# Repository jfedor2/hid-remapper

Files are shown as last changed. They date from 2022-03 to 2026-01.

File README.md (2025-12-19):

# HID Remapper

_For user documentation please see the project's website at [remapper.org](https://www.remapper.org/)._

This is a configurable USB dongle that allows you to remap inputs from mice, keyboards and other devices. It works completely in hardware and requires no software running on the computer during normal use.

It can do things like reassign buttons, change keyboard layouts, map mouse buttons to keyboard inputs, map keystrokes to mouse inputs, change mouse sensitivity (permanently or when a button is held), rotate mouse axes by arbitrary (non-90 degree) angles, drag-lock for mouse buttons, scroll by moving the mouse, and much more.

It is configurable [through a web browser](https://www.remapper.org/config/) using WebHID (Chrome or Chrome-based browser required).

Wireless receivers are supported and multiple devices can be connected at the same time using a USB hub (with different mappings for each device if desired).

In addition to the remapping functionality, it can do polling rate overclocking up to 1000 Hz.

A separate [serial](SERIAL.md) version of the remapper takes inputs from a serial (RS-232) mouse and translates them to USB.

There's also a [Bluetooth](BLUETOOTH.md) version that runs on nRF52840-based boards, which translates Bluetooth inputs to USB.

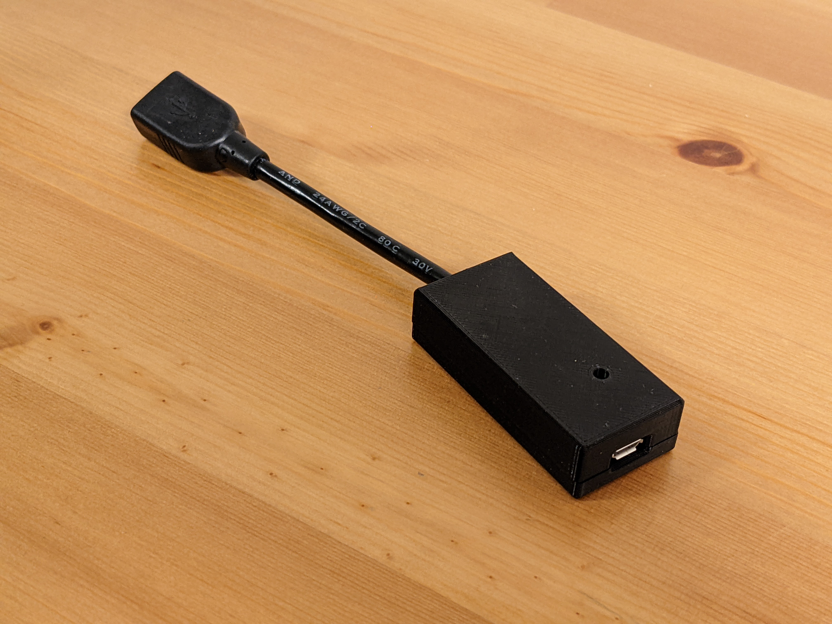
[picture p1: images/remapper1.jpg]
HID Remapper


## How to make the device

There are three main ways of making the HID Remapper. You can either buy [this board](https://www.adafruit.com/product/5723) from Adafruit, make it yourself using a Raspberry Pi Pico (or two), or you can use the provided files to manufacture a custom board at JLCPCB or a similar service. The functionality is the same in all cases.

If you get the Feather RP2040 USB Host board from Adafruit, the device is ready to use, you just need to flash it with the right firmware ([remapper\_feather.uf2](https://github.com/jfedor2/hid-remapper/releases/latest/download/remapper_feather.uf2)). Hold the "Boot" button on the board, then press the "Reset" button. A USB drive should show up on your computer. Copy the UF2 file to that drive. That's it.

See [here](HARDWARE.md) for details on how to make the Pico variants of the device and [here](custom-boards/) for details on the custom board option.

## How to use the configuration tool

A live version of the web configuration tool can be found at [remapper.org/config](https://www.remapper.org/config/).

For details on how to use it, please see the [HID Remapper Manual](https://www.remapper.org/manual/).

If you can't use the browser-based configuration tool, there's also a [command-line tool](config-tool) that takes JSON in the same format as the web tool on standard input. I only tested it on Linux, but in theory it should also run on Windows and Mac.

## How to update the firmware

The procedure to update the firmware is similar on all variants. When you go to the configuration website and try to connect to your device when it doesn't have the latest firmware, you will get a message and a link to a version of the configuration interface that is compatible with your current (old) firmware. Click that link, connect to your HID Remapper by clicking "Open device" as usual, then go to the "Actions" tab and click "Flash firmware". This will put your device in firmware flashing mode. A drive should appear on your computer. For all the RP2040-based variants, the drive will be named "RPI-RP2". For the Bluetooth variants, it will be called something else, depending on what board you're using. Download the correct firmware file for your variant (see table below) and copy it to that drive. On custom boards v1, v2, v5, v6 and v7 (dual RP2040 boards), after flashing the firmware you have to disconnect and reconnect your HID Remapper. That's it, you can go back to the regular version of the configuration interface and carry on.

_(Please note that previously a manual "Flash B side" step was required on custom boards v1, v2, v5, v6 and v7. That is no longer necessary.)_

If you're using the dual Pico variant then you need to flash the A side using the [remapper\_dual\_a.uf2](https://github.com/jfedor2/hid-remapper/releases/latest/download/remapper_dual_a.uf2) file as described above and then flash the B side manually. Disconnect your HID Remapper from your computer, disconnect the OTG adapter from the B-side Pico, hold the BOOTSEL button on the B-side Pico and then, while holding the button, connect the B-side Pico to your computer. A drive named "RPI-RP2" should appear. Copy the [remapper\_dual\_b.uf2](https://github.com/jfedor2/hid-remapper/releases/latest/download/remapper_dual_b.uf2) file to that drive. Disconnect the B-side Pico from your computer, reconnect the OTG adapter and reconnect your HID Remapper to your computer.

When updating firmware, the current configuration on your HID Remapper is preserved. For extra peace of mind you can export your configuration to a JSON file before performing the update. That way if you need to revert to the old version of the firmware for any reason, you'll be able to import the configuration from the JSON file (configuration is lost when going from a newer firmware to an older firmware).

variant | firmware file(s) | notes
------- | ---------------- | -----------------------
single Pico | [remapper.uf2](https://github.com/jfedor2/hid-remapper/releases/latest/download/remapper.uf2) |
dual Pico | [remapper\_dual\_a.uf2](https://github.com/jfedor2/hid-remapper/releases/latest/download/remapper_dual_a.uf2)<br>[remapper\_dual\_b.uf2](https://github.com/jfedor2/hid-remapper/releases/latest/download/remapper_dual_b.uf2) | each Pico needs to be flashed separately
Feather RP2040 with USB Host | [remapper\_feather.uf2](https://github.com/jfedor2/hid-remapper/releases/latest/download/remapper_feather.uf2) |
custom board v1 | [remapper\_board.uf2](https://github.com/jfedor2/hid-remapper/releases/latest/download/remapper_board.uf2) | disconnect and reconnect after flashing
custom board v2 | [remapper\_board.uf2](https://github.com/jfedor2/hid-remapper/releases/latest/download/remapper_board.uf2) | disconnect and reconnect after flashing
custom board v3 | [remapper\_feather.uf2](https://github.com/jfedor2/hid-remapper/releases/latest/download/remapper_feather.uf2) |
custom board v4 | [remapper\_feather.uf2](https://github.com/jfedor2/hid-remapper/releases/latest/download/remapper_feather.uf2) |
custom board v5 | [remapper\_board.uf2](https://github.com/jfedor2/hid-remapper/releases/latest/download/remapper_board.uf2) | disconnect and reconnect after flashing
custom board v6 | [remapper\_board.uf2](https://github.com/jfedor2/hid-remapper/releases/latest/download/remapper_board.uf2) | disconnect and reconnect after flashing
custom board v7 | [remapper\_board\_v7.uf2](https://github.com/jfedor2/hid-remapper/releases/latest/download/remapper_board_v7.uf2) | disconnect and reconnect after flashing
custom board v8 | [remapper\_board\_v8.uf2](https://github.com/jfedor2/hid-remapper/releases/latest/download/remapper_board_v8.uf2) |
Feather nRF52840 Express | [remapper_adafruit_feather_nrf52840.uf2](https://github.com/jfedor2/hid-remapper/releases/latest/download/remapper_adafruit_feather_nrf52840.uf2) |
Xiao nRF52840 | [remapper_seeed_xiao_nrf52840.uf2](https://github.com/jfedor2/hid-remapper/releases/latest/download/remapper_seeed_xiao_nrf52840.uf2) |
serial | [remapper_serial.uf2](https://github.com/jfedor2/hid-remapper/releases/latest/download/remapper_serial.uf2) |

For boards not listed above, use the same file name you used when flashing it for the first time.

## How to compile the firmware

The easiest way to compile the firmware is to let GitHub do it for you. This repository has GitHub Actions that build the firmware, so you can just fork, make your changes, wait for the job to complete, and look for the binaries in the artifacts produced.

To compile the RP2040 firmware on your machine, use the following steps (details may vary depending on your Linux distribution):

```
sudo apt install gcc-arm-none-eabi libnewlib-arm-none-eabi libstdc++-arm-none-eabi-newlib srecord
git clone https://github.com/jfedor2/hid-remapper.git
cd hid-remapper
git submodule update --init
cd firmware
mkdir build
cd build
cmake ..
# or, to build for the custom boards:
# PICO_BOARD=remapper cmake ..
make
```

To compile the nRF52 firmware, you can either follow [Nordic's setup instructions](https://docs.nordicsemi.com/bundle/ncs-latest/page/nrf/installation.html) and then `west build -b seeed_xiao_nrf52840` to compile the firmware, or you can use Docker with a command like this (start from the top level of the repository or adjust the path accordingly):

```
docker run --rm -v $(pwd):/workdir/project -w /workdir/project/firmware-bluetooth nordicplayground/nrfconnect-sdk:v2.2-branch west build -b seeed_xiao_nrf52840
```

## License

The software in this repository is licensed under the [MIT License](LICENSE), unless stated otherwise.

The hardware designs in this repository are licensed under the Creative Commons Attribution 4.0 International license ([CC BY 4.0](https://creativecommons.org/licenses/by/4.0/)), unless stated otherwise.

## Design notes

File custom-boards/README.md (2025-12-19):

# Custom HID Remapper boards

This document describes how to have custom HID Remapper boards manufactured using the provided design files at a service like JLCPCB. If you'd rather make the device using a Raspberry Pi Pico, see [here](../HARDWARE.md) for details on that option.

There are eight versions, imaginatively named v1-v8. v1, v2, v5, v6 and v7 are equivalent to the dual Pico variant when it comes to internal architecture and device compatibility. v3 and v4 are equivalent to the single Pico variant. v8 uses a single RP2040 chip, but it doesn't have USB inputs.

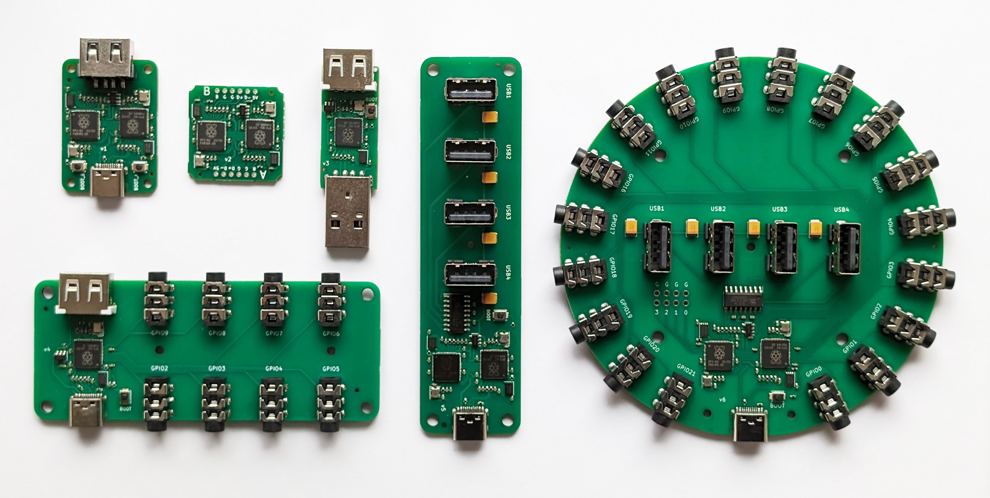
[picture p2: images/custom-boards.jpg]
Custom HID Remapper boards


The main advantage of the v1 board is that it can be made with no soldering, you just order the board, flash the firmware, and have a working device. Files for an optional 3D printable enclosure are also available (it uses M2x8 flat head screws).

The v2 board doesn't have USB connectors and is meant to be built into existing devices like trackballs by soldering the appropriate wires directly to the board.

The v3 board has the form factor of a USB dongle (you plug it directly into your computer).

The v4 board has eight 3.5mm connectors wired to GPIO2-9, meant to be used with external buttons or switches. The 3D printed case for it uses two M2x4 screws and four M3x10 flat head screws.

The v5 board has a built-in four port USB hub. The 3D printed case for it uses one M2x4 screw and four M3x10 flat head screws.

The v6 board has a built-in four port USB hub and eighteen 3.5mm connectors wired to GPIO pins that can be used with external buttons or switches. The 3D printed case for it uses three M2x4 screws and four M3x10 flat head screws.

The v7 board (not pictured above) is a companion device for accessibility controllers like the PlayStation Access and the Xbox Adaptive Controller. It has four analog and ten digital outputs that can be connected to the 3.5mm input ports on those controllers. More information [here](v7).

The v8 board (not pictured above) has one 3.5mm TRRS jack that can be used for analog inputs. For example it could be used to add analog stick inputs to the Hori Flex controller. The jack also works for one or two digital buttons or switches. More information [here](v8).

## How to order the boards

The process of ordering the boards is the same for all versions. You go to JLCPCB's [website](https://jlcpcb.com/), upload the Gerber zip file, enable the "PCB Assembly" option and upload the BOM and CPL files. All the options can be left at their default values. Then click through the rest of the process, making sure that all the components are in stock.

If you want to use some other service than JLCPCB, you will likely need to adapt at least the BOM and CPL files to match their requirements.

## How to flash the firmware

### Firmware flashing mode

v1 and v3-v8 boards have buttons labeled "BOOT\_A" and "BOOT", respectively. These work the same as the BOOTSEL button on a Raspberry Pi Pico. You hold the button while connecting it to a computer to put the board in firmware flashing mode. The v2 board doesn't have a button, but it has the equivalent pin broken out. Short the BOOT pin on the A side to GND while connecting the board to a computer to put it in firmware flashing mode. Then copy the UF2 file to the drive that appears.

If the board is already flashed with some version of the HID Remapper firmware then you can also put it in firmware flashing mode by going to the web config tool and pressing the "Flash firmware" button. This is useful when you want to upgrade the firmware on a device that is not easily accessible.

When the board is fresh from the factory (has never been flashed), it should enter firmware flashing mode automatically when you connect it to a computer with no additional steps necessary.

### v1, v2, v5 and v6

Flash the board with [remapper\_board.uf2](https://github.com/jfedor2/hid-remapper/releases/latest/download/remapper_board.uf2) file by putting it in firmware flashing mode and copying the file to the "RPI-RP2" drive that should appear on your computer.

Disconnect and reconnect your HID Remapper after flashing the firmware.

_(Please note that previously a manual "Flash B side" step was required on these boards. That is no longer necessary.)_

### v7

Flash the board with [remapper\_board\_v7.uf2](https://github.com/jfedor2/hid-remapper/releases/latest/download/remapper_board_v7.uf2) file by putting it in firmware flashing mode and copying the file to the "RPI-RP2" drive that should appear on your computer.

Disconnect and reconnect your HID Remapper after flashing the firmware.

_(Please note that previously a manual "Flash B side" step was required on this board. That is no longer necessary.)_

### v3 and v4

Flash the board with [remapper\_feather.uf2](https://github.com/jfedor2/hid-remapper/releases/latest/download/remapper_feather.uf2) file by putting it in firmware flashing mode and copying the file to the "RPI-RP2" drive that should appear on your computer.

### v8

Flash the board with [remapper\_board\_v8.uf2](https://github.com/jfedor2/hid-remapper/releases/latest/download/remapper_board_v8.uf2) file by putting it in firmware flashing mode and copying the file to the "RPI-RP2" drive that should appear on your computer.

## Acknowledgements

v1, v4, v5, v6 and v7 PCB designs use [Type-C.pretty](https://github.com/ai03-2725/Type-C.pretty) library by [ai03-2725](https://github.com/ai03-2725).

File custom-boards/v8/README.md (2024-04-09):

# HID Remapper custom board v8

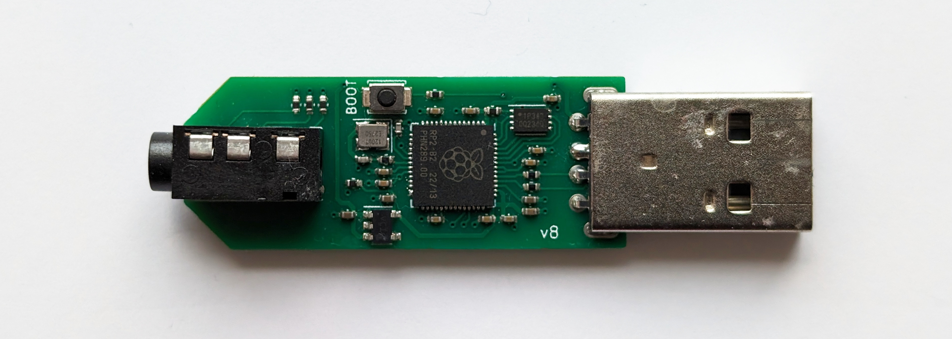
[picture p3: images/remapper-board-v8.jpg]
HID Remapper custom board v8


This variant of HID Remapper doesn't have USB inputs, it only has one 3.5mm TRRS jack. It can be used to connect an analog joystick or trigger (and also one or two digital buttons or switches).

It could be used to add analog stick inputs to the Hori Flex controller or for any type of input when plugged into a computer.

Because different devices will have different ranges and possibly neutral points, you will need to use expressions to scale the readings from the analog inputs to whatever range is expected by the outputs you want to map them to. Use the "Monitor" tab to check what raw values HID Remapper is getting from your joystick or other analog device.

The two analog values are exposed as usages 0xfff80000 and 0xfff80001.

So for example if your joystick sits around 2000 when neutral and goes from 500 to 3500 when moved, you could use an expression like this for one of its axes:

```
0xfff80000 input_state 
-2000 add 
0.085 mul
128 add
0 255 clamp
```

You might want to add some deadzone handling. Check the "Examples" tab for a complete configuration.

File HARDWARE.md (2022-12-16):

# How to make the Pico variants of the device

This document describes how to make the HID Remapper using a Raspberry Pi Pico (or two). Alternatively, if you don't want to do any soldering, you can have a custom board made at a service like JLCPCB. For more details on this option, see [here](custom-boards/).

There are two variants of the hardware: the single Pico version and the dual Pico version. They have the same functionality, but the dual Pico version has better device compatibility - most input devices work with either, but some will only work with the dual Pico version.

## Single Pico version

This version of the remapper is made using a Raspberry Pi Pico and a USB extension cable cut in half. It is possible thanks to this awesome [Pico-PIO-USB](https://github.com/sekigon-gonnoc/Pico-PIO-USB) library by [sekigon-gonnoc](https://github.com/sekigon-gonnoc). The Pico's built-in USB interface is used to connect to the host computer and the library is used to handle inputs from a USB mouse or keyboard.

Making the device is really simple, you just need to cut a USB extension cable in half and solder four wires to the right pins on the Pico: D+ to GPIO0 (pin 1), D- to GPIO1 (pin 2), VBUS to VBUS (pin 40) and GND to GND (pin 38). The wires are usually color coded (green, white, red, black, respectively). See the pictures below.

The [enclosure](enclosure) folder has 3D-printable files for an optional case, seen in the photo below. It uses four M2x8 flat head screws.

The provided [remapper.uf2](https://github.com/jfedor2/hid-remapper/releases/latest/download/remapper.uf2) file can be used to flash the firmware onto the Pico the usual way (hold BOOTSEL button while connecting to the computer, then copy the UF2 file to the USB drive that shows up).

HID Remapper single Pico version
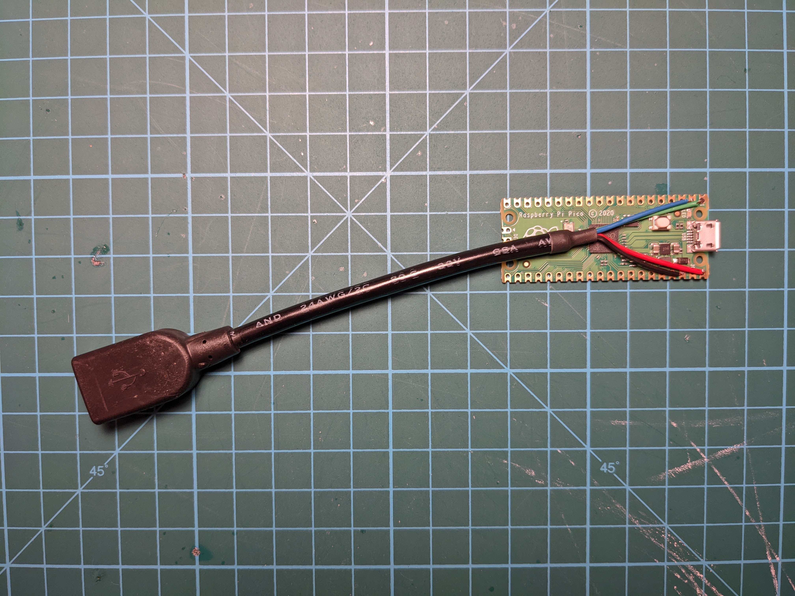
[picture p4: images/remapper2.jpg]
HID Remapper single Pico version inside

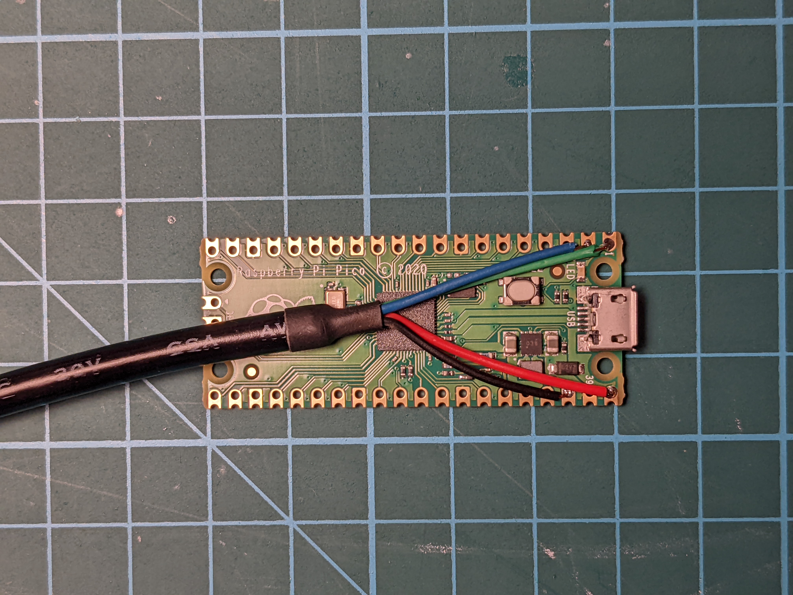
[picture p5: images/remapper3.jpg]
HID Remapper single Pico version soldering close-up


## Dual Pico version

This version of the remapper uses two Raspberry Pi Picos that talk to each other over serial. One of Picos (B side) receives inputs from a USB mouse via an OTG cable and sends them over the serial link to the other Pico (A side). This Pico processes the configured mappings and sends the resulting inputs to the computer.

You have to solder six wires between the two Picos, connecting the pins as shown below.

| A side | B side |
| -----: | -----: |
| VBUS (pin 40) | VBUS (pin 40) |
| GND (pin 38) | GND (pin 38) |
| GPIO20 (pin 26) | GPIO21 (pin 27) |
| GPIO21 (pin 27) | GPIO20 (pin 26) |
| GPIO26 (pin 31) | GPIO27 (pin 32) |
| GPIO27 (pin 32) | GPIO26 (pin 31) |

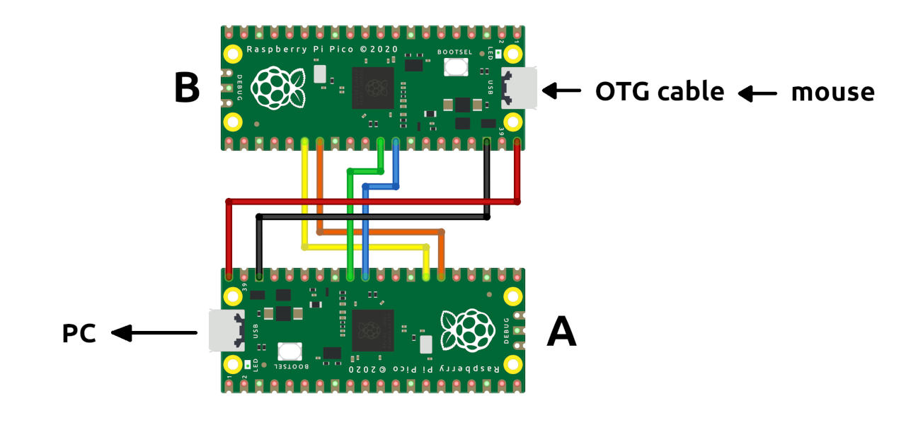
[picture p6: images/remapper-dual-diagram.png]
HID Remapper dual Pico version connection diagram


There are two firmware files, one for each side. The side that will be connected to the computer has to be flashed with the [remapper\_dual\_a.uf2](https://github.com/jfedor2/hid-remapper/releases/latest/download/remapper_dual_a.uf2) file, and the other side (that you will connect your input devices to using an OTG cable or adapter) has to be flashed with the [remapper\_dual\_b.uf2](https://github.com/jfedor2/hid-remapper/releases/latest/download/remapper_dual_b.uf2) file. Flashing is done the usual way: hold BOOTSEL button while connecting to the computer, then copy the UF2 file to the USB drive that shows up. It is okay to do the flashing after the two Picos are connected as described above, but don't connect both sides to a host at the same time.

The [enclosure](enclosure) folder has 3D-printable files for an optional case, seen in the photo below. It uses four M2x4 screws to attach the Pico boards and two M2x16 flat head screws to keep the two halves together.

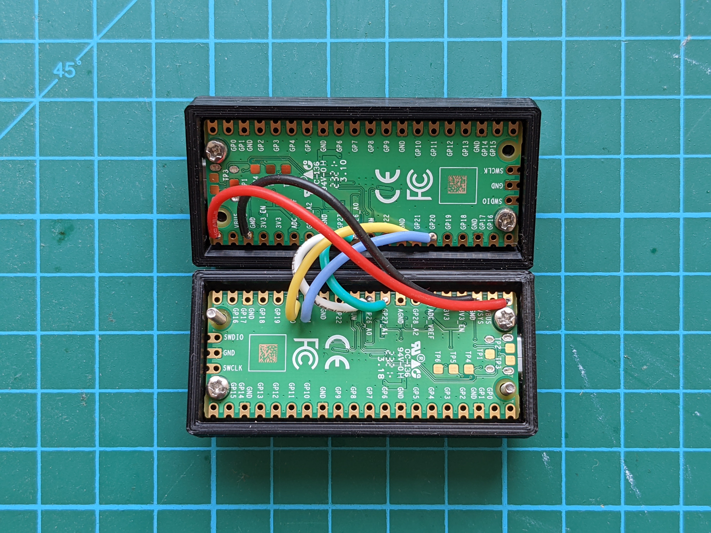
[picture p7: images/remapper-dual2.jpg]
HID Remapper dual Pico version inside

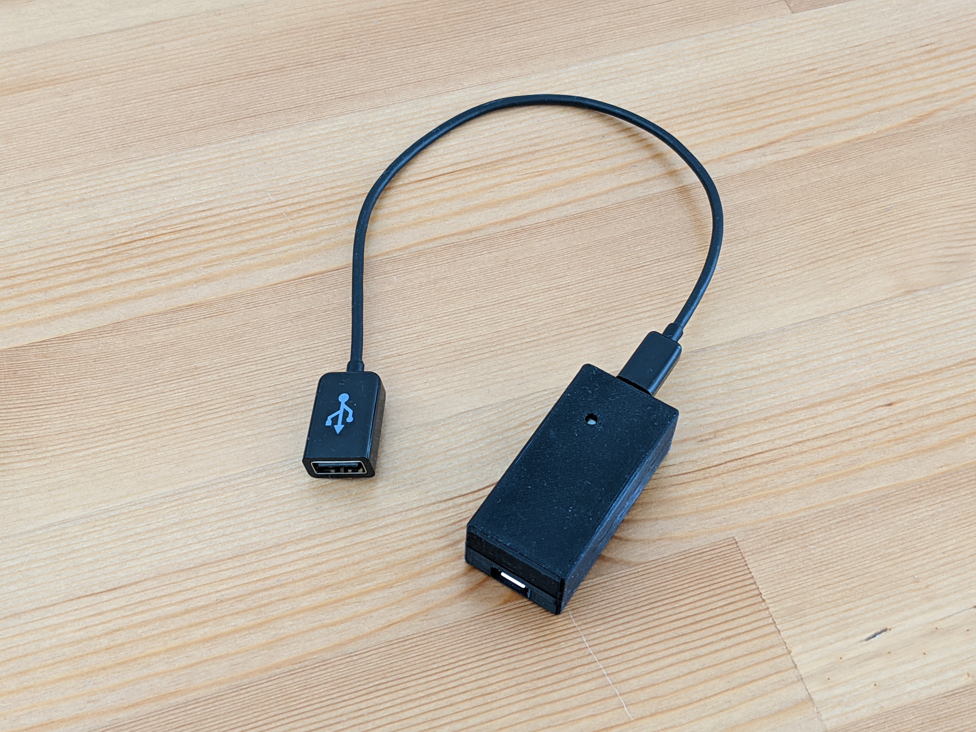
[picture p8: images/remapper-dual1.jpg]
HID Remapper dual Pico version


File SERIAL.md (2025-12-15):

# Serial mouse support

There's a special version of the remapper that takes inputs from a serial mouse and translates them to USB. It's different from most adapters in that they usually only convert RS-232 to USB serial. This converts to USB HID and you can use it even if your operating system doesn't support serial mice at all. The remapping functionality works as usual (there's no polling rate overclocking). Currently only the Microsoft serial mouse protocol is supported.

You can either use the [RP2040-RS232](https://github.com/jfedor2/rp2040-rs232) adapter or you can make your own as described below. If you use the RP2040-RS232 adapter, the multi-firmware that comes with it includes the serial variant of HID Remapper. You can also just use the firmware linked here if you want.

To make one yourself you will need a Raspberry Pi Pico, a [Pololu 23201a Serial Adapter](https://www.pololu.com/product/126), and also a null modem adapter and a DB9 gender changer (on the photo below these are two separate adapters, but you can also get one that does both).

The provided [remapper\_serial.uf2](https://github.com/jfedor2/hid-remapper/releases/latest/download/remapper_serial.uf2) file can be used to flash the firmware onto the Pico the usual way (hold BOOTSEL button while connecting to the computer, then copy the UF2 file to the USB drive that shows up).

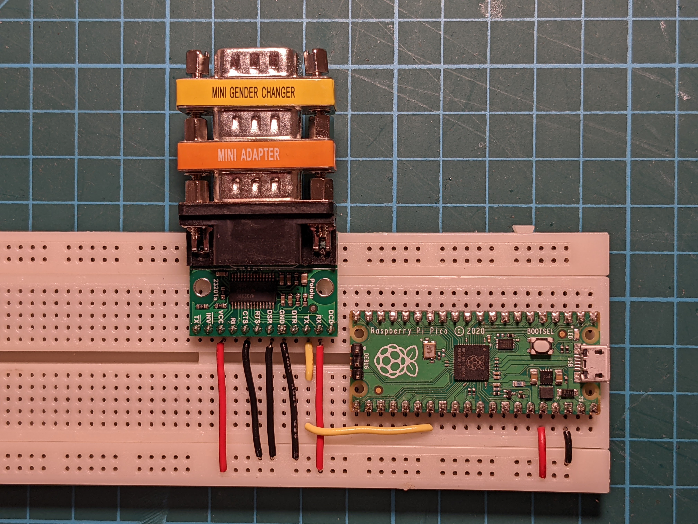
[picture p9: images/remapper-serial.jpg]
HID Remapper serial version


The pin connections are as follows:

| Pico | serial adapter |
| -----: | --- |
| 3V3 (pin 36) | VCC |
| 3V3 (pin 36) | RX |
| GND (pin 38) | GND |
| GND (pin 38) | DSR |
| GND (pin 38) | CTS |
| GPIO21 (pin 27) | TX |

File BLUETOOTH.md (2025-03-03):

# Bluetooth version

_(Please note this is experimental and hasn't been tested with a lot of devices.)_

There's a special version of the remapper that takes inputs from Bluetooth devices and translates them to USB. It's different from most Bluetooth USB dongles in that from the computer's point of view it is a USB mouse/keyboard, so it requires no special drivers. The remapping functionality works as usual. You can connect multiple devices to it at the same time.

**It only works with Bluetooth Low Energy devices, not Bluetooth Classic.** You can usually tell that a device uses Bluetooth LE if the documentation says it requires Bluetooth version 4 or 5, but some devices say they use Bluetooth 4 or 5 and still use Bluetooth Classic (which technically isn't wrong as Bluetooth Classic is still part of the newer spec).

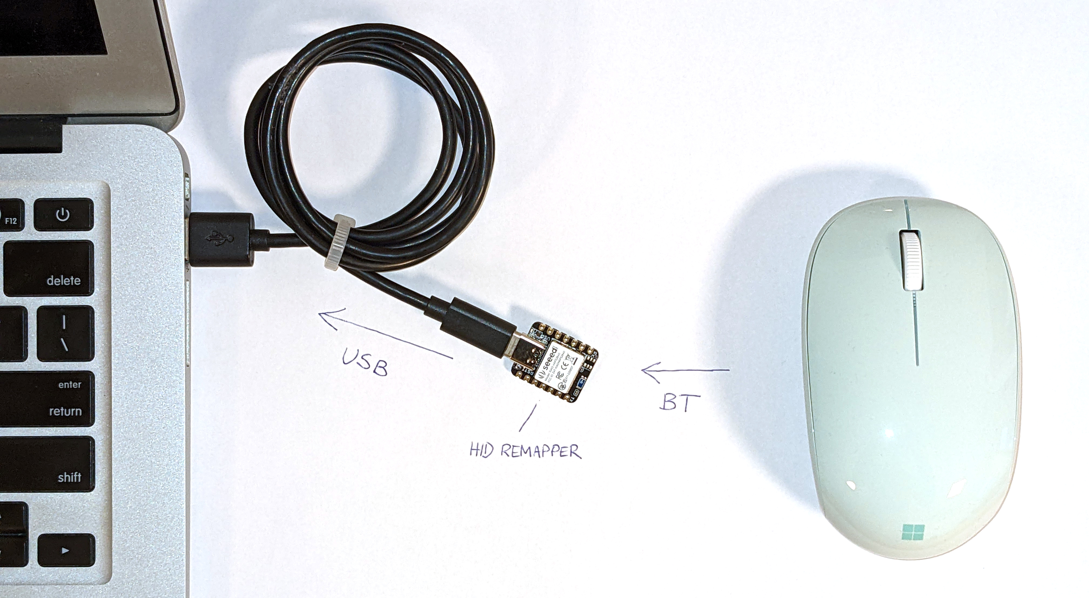
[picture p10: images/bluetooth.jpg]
HID Remapper Bluetooth


The Bluetooth version of the remapper runs on Nordic's nRF52840 chip. Currently precompiled binaries are available for the following boards:

* [Adafruit Feather nRF52840 Express](https://www.adafruit.com/product/4062)
* [Seeed Studio Xiao nRF52840](https://www.seeedstudio.com/Seeed-XIAO-BLE-nRF52840-p-5201.html)

To flash the [firmware](firmware-bluetooth), first put the board in flashing mode by double clicking the reset button quickly. A drive should appear on your computer. Copy the [UF2 file that matches your board](https://github.com/jfedor2/hid-remapper/releases/latest) to that drive and that's it. If you want to flash a newer version of the firmware in the future, you can also put the board in firmware flashing mode using the HID Remapper [web configuration tool](https://www.remapper.org/config/).

To connect Bluetooth devices to the remapper, you need to put the device in pairing mode. This is device-specific, but usually involves holding a button for a few seconds. Then you also need to put HID Remapper in pairing mode. You do this by either pressing the "user switch" button on the board or by clicking the "Pair new device" button on the web configuration tool (the Xiao board doesn't have a user button so you have to either do it through the web interface or by shorting pin 0 to GND). The remapper will also automatically enter pairing mode if no devices are currently paired.

You can tell the remapper is in pairing mode if the blue LED is lit constantly. When it's not in pairing mode, the blue LED will be blinking, with the number of blinks per cycle corresponding to the number of currently connected devices.

To make the remapper forget all currently paired devices, hold the "user switch" button for over 3 seconds, or click the "Forget all devices" button on the web configuration tool (or short pin 0 to GND for over 3 seconds on the Seeed Xiao board).

## Known issues

* Quirks mechanism for fixing broken report descriptors doesn't work.
* Reconnects could be faster if we cached attributes/report descriptor.

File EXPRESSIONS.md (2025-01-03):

# Expressions

_Please note: this is an experimental feature that is likely to evolve in the future._

Instead of setting a mapping input to a button or an axis and possibly adding a scaling factor, you can have HID Remapper evaluate an arbitrary arithmetic expression to determine the value to which the output of the mapping will be set. This allows for more flexibility, because the expression can be more complex than simply multiplying an input value by a factor.

HID Remapper expressions are currently input using [Reverse Polish Notation](https://en.wikipedia.org/wiki/Reverse_Polish_notation). If you’ve heard of the Forth programming language or used an HP scientific calculator, this may sound familiar to you. In the future I would like to also allow more user-friendly forms of input.

Each expression is a list of operations. The operations all work on _the stack_. The stack is simply a list of values, which the operations can add to and remove from. Last value added to the stack is said to be on top of the stack.

Let’s consider the simplest of expressions: 2+3. In RPN syntax this would be written as:
```
2 3 add
```
Note how the operands come first and the operator comes last. Let’s walk through how HID Remapper evaluates such an expression. Initially, the stack is empty. Then we go through each element of the expression, process it, and the value that is on top of the stack after we’re done is said to be the result of the expression (which will be used as the output value of the mapping).
When we encounter the `2`, we simply add it to the stack. The stack is now \[2\]. When we encounter the `3`, we also add it to the stack. The stack is now \[2, 3\]. Things get interesting when we encounter the `add` operation. It removes the top two values from the stack (2 and 3), adds them, giving 5, and puts that result on the stack. The stack now contains one value (5). If this was the expression that we set as the input of a mapping and set the output to, say, "Cursor X", this would result in the cursor moving 5 units to the right on every iteration of the mapping engine.

Of course in the real world we’ll want the result of the expression to not always be the same, but instead depend on the state of the inputs coming from the devices connected to the HID Remapper.

Let’s consider such a real world example. Let’s say we have a gaming controller, like a PS5 DualSense, and we want to map it so that moving the left analog stick moves the mouse cursor. To make things more interesting, let’s also say that we want to add a _dead zone_, so that small noise or drift in the analog stick doesn’t move the cursor.

To achieve this we add a mapping with "Expression 1" as the input and "Cursor X" as the output (the Y or vertical axis would also need to be configured in a similar way). Now let’s think what our expression needs to look like. First we need to fetch the current value of the input. To do that we need to know the usage code that the controller uses for the left analog stick. You can use the "Monitor" tab to check this. Game controllers usually use the code 0x00010030 for the horizontal axis of the left analog stick, which also happens to be the code that mice use for the horizontal axis. To fetch the value of this input, we start our expression like this:
```
0x00010030 input_state
```
The `0x00010030` part puts that value on the stack. The `input_state` operation takes one value from the stack, fetches the input state value corresponding to that usage code, and puts it on the stack. What values does a controller send for the left analog stick? Again, this is something that you could check using the "Monitor" tab. In our case it sends values between 0 and 255, with 0 corresponding to the stick all the way to the left, 255 all the way to the right, and 128 corresponding to the stick’s neutral center position. What we would like to have is negative values for when the stick is moved to the left and positive values when it’s moved to the right, so we’ll just subtract 128 from the input value. We can do that by extending our expression like this:
```
0x00010030 input_state -128 add
```
Then let’s handle the dead zone. Let’s say that if the current value is between -10 and 10, we want to act as if it was zero, giving us around 8% dead zone. To do this we’ll use a certain trick involving Boolean logic. The expression evaluation process doesn’t have conditional logic, but it does have a `gt` operation that takes two values from the stack and puts either 1 or 0 back to the stack, depending on whether one of the values is greater than the other. This way we can know whether the input value was greater than some threshold or not. But how can we set the output to the original value if it’s bigger than the threshold and to zero if not? Let’s consider this expression and walk through it step by step:
```
0x00010030 input_state -128 add dup abs 10 gt mul
```
As we’ve discussed before, `0x00010030 input_state -128 add` fetches the input value and subtracts 128 from it. `dup` makes a copy of the top of the stack, if the stack was \[x\] before it, it is now \[x, x\]. `abs` takes a value from the stack and puts its absolute value back on the stack. So if the stack was, say \[-30, -30\], it will now be \[-30, 30\]. If it was \[5, 5\], it will still be \[5, 5\]. `10` puts the threshold value on the stack and `gt` takes two values from the stack and compares them. If the stack was \[-30, 30, 10\] before, it will now be \[-30, 1\]. If it was \[5, 5, 10\], it will now be \[5, 0\]. Now comes the trick. Even though `0` and `1` in our example corresponds to logical _false_ and _true_, there’s nothing stopping us from treating it as a number and multiplying it by the other value on the stack. That’s what the `mul` operation does. If the stack was \[-30, 1\], it will now be \[-30\]. If it was \[5, 0\], it will now be \[0\], effectively giving us the dead zone that we wanted.

Two things remain, first we should scale the output to a reasonable range. Through experimentation we find that multiplying it by 0.025 makes the cursor move with the speed we want, so we do just that:
```
0x00010030 input_state -128 add dup abs 10 gt mul 0.025 mul
```
Still with us? Let’s consider another example more briefly. Let’s say we want the D-pad on our game controller to also move the mouse cursor. We happen to know (from the "Monitor" tab) that the D-pad sends the usage code 0x00010039 with values between 0 and 7 when it’s pressed in some direction and a value outside this range (say, 8 or 15) when it’s in the neutral position. Here’s an expression that we could use for the "Cursor X" mapping:
```
0x00010039 input_state 7 gt not 0x00010039 input_state 45 mul sin mul
```
`0x00010039 input_state` fetches the input value. `7 gt` checks if it’s outside the valid range. `not` inverts that condition. If at this point we have a `1` on the stack, this means that the D-pad is being pressed in some direction. If we have a `0`, it means that it’s not. Then we fetch the input value again (we could use `dup` before the `7 gt`, but then we’d also need `swap` which we currently don’t have). The D-pad sends a 0 for North, 1 for North-East, 2 for East etc. So to get a value in degrees (0-360), we multiply the received value by 45 (`45 mul`). Trigonometry tells us that to get the horizontal axis part of the movement in a certain direction, we can use the sine function (`sin`). Now the stack is either `1` and a valid sine result or `0` and some garbage value that we’ll disregard by multiplying the two values (`mul`).

For the vertical axis the expression is almost the same, we just need to use cosine instead of sine and negate its output value:
```
0x00010039 input_state 7 gt not 0x00010039 input_state 45 mul cos -1 mul mul
```
In this case we don’t do additional scaling because we’re happy with the way it is, but we could of course do that if we wanted to.

The two examples above already show us how we can do things that weren’t previously possible with the existing mapping mechanism, but let’s go further. As you’ve noticed we can fetch the state of some input more than once in an expression. What we can also do is fetch the state of multiple different inputs and do some calculations on them to produce an output. When would we want to do that? We could for example check if some button is pressed and apply some part of the calculation only if it is, emulating the layer mechanism in a more flexible way. Or let’s say that we have a joystick, like the ones used for flight simulators, that has a stick and a throttle lever. Here’s an expression that makes the stick move the mouse cursor, but with the speed controlled by the throttle lever!
```
0x00010030 input_state -128 add dup abs 10 gt mul 0.025 mul 0x00010036 input_state -1 mul 255 add 0.007 mul mul
```
Our joystick sends the 0x00010030 usage code (range 0-255) for the X axis of the stick and the 0x00010036 usage code (also 0-255, but with 0 being the maximum speed and 255 the minimum) for the throttle lever. We fetch the state of the stick (`0x00010030 input_state`), re-center it around zero (`-128 add`), apply the dead zone (`dup abs 10 gt mul`), apply a scaling (`0.025 mul`), fetch the state of the throttle lever (`0x00010036 input_state`), invert it so that zero corresponds to the state we want to be the minimum speed (`-1 mul 255 add`), scale it (`0.007 mul`), and finally multiply the stick value by the throttle value (`mul`).

In addition to fetching the state of inputs in expressions, you can also fetch the current time. This has some interesting applications, for example you could write an expression like this to make a button work in "turbo" mode (press and release the button quickly when you hold it):
```
time 200 mod 100 gt 0x00090001 input_state_binary mul
```
`time` fetches the current time in milliseconds. `200 mod` takes that value modulo 200. `100 gt` checks if the result is in the upper half of the 200 millisecond time window, `0x00090001 input_state_binary` fetches the state of the button input and `mul` multiplies the two values, effectively pressing the button 50% of the time, with a 200 ms period.

The `time` operation could also be used to make a mouse jiggler (a function that makes the mouse move by itself). Check the "Examples" section in the web configuration tool to see what that expression might look like.

Looking for more inspiration? Try writing a set of expressions that will press one button when an analog trigger on a game controller is half-pressed and another button when it is fully pressed, like a dual stage trigger on a flight sim joystick.

## Registers

For certain behaviors it is necessary not only to be able to define a function that takes current input state and returns an output state, but also to consider previous states of some inputs. HID Remapper has a mechanism to store some value during expression evaluation and recall that value in another expression or in the same expression at a later time.

There are 32 registers, starting at number 1. They are shared between all expressions. To store a value in register 1 we would use something like this (`store` consumes two values from the stack):
```
128 1 store
```
To recall (put on top of the stack) the contents of a register we would use something like this:
```
1 recall
```
Expressions don't have conditional execution, but with some clever arithmetic we can achieve similar results. Say we wanted to increase the counter in register 1 when the mouse is moved horizontally by more than 3 units. We could use the following expression:
```
0x00010030 input_state abs 3 gt 1 recall add 1 store
```
Instead of saying "change the register if something is true", we're saying "unconditionally change the register, but increment it by a value that happens to be zero when a certain condition is not met".

When writing expressions that use registers, it's important to know when and in what order expressions are evaluated.

All expressions are evaluated once per millisecond (technically USB frame), in order, regardless of whether they are used as inputs in mappings. This means that if you use Expression 2 to calculate some value and store it in a register, you will see this new value in Expression 3 in the same iteration of the remapping engine, but Expression 1 would still see the register contents from the previous iteration.

See the "Examples" section in the web configuration tool for some ideas on how registers can be used in practice.

## Comments

You can put `/* comments */` in expressions, but they are not saved to the device, so if you save your configuration and later load it from the device, the comments will be lost. But they are preserved when you export the configuration to a JSON file and later import it.

## Tips and tricks

Use `input_state` to fetch the state of relative usages like a mouse axis and non-binary absolute usages like a D-pad or an analog stick or trigger. Use `input_state_binary` to fetch the state of binary absolute usages (buttons).

The values stored on the stack and in registers are 32-bit integers that are multiplied by 1000 to simulate fractional values. Therefore it is impossible to put 0.0001 on the stack. If you want to multiply a value by 0.0001, first multiply it by 0.001 and then by 0.1.

When fetching the currently active layers with `layer_state` (and, similarly, `sticky_state`), the bitmask value is put on the stack as is, without the x1000 scaling just mentioned. Therefore if you want to perform a `bitwise_and` operation on that value, let’s say to check if layer 1 is active, you need to either use 0.002 or 0x02 as the other operand (hex values are passed as is because they’re normally used for HID usage codes). For example:
```
layer_state 0x02 bitwise_and not not 0x00090001 input_state_binary mul
```

Currently, the tap-hold and the sticky logic is only triggered for usages that are an input in a mapping with those flags set. Therefore if you want to make use of those states in an expression, you have to add another dummy mapping with the button in question set as input and `Nothing` set as output, with the appropriate tap/hold/sticky flag set.

When you fetch the state of an input in an expression that is used as an input in a mapping, that input is considered to be mapped on the layers the mapping is active on for the purpose of unmapped inputs passthrough.

## Operation reference

Here's a list of all operations that can be used in an expression. Each operation takes the values listed in the Input column from the stack and puts the values listed in the Output column on the stack. If multiple values are listed, the last one corresponds to the top of the stack.

| Operation | Input | Output | Notes |
| --- | --- | --- | --- |
| `12345` | | 12345 | Puts the value on the stack. |
| `0x00120034` | | 0x00120034 | Puts the value on the stack. Use for usage codes. |
| `input_state` | _usage_ | state of _usage_ input | |
| `input_state_binary` | _usage_ | state of _usage_ input | Use for buttons. |
| `input_state_scaled` | _usage_ | state of _usage_ input | Scaled to 0-255 range for non-binary absolute usages. |
| `prev_input_state` | _usage_ | previous state of _usage_ input | |
| `prev_input_state_binary` | _usage_ | previous state of _usage_ input | Use for buttons. |
| `prev_input_state_scaled` | _usage_ | previous state of _usage_ input | Scaled to 0-255 range for non-binary absolute usages. |
| `add` | _x_, _y_ | _x + y_ | |
| `sub` | _x_, _y_ | _x - y_ | |
| `mul` | _x_, _y_ | _x * y_ | |
| `div` | _x_, _y_ | _x / y_ | 0 if y == 0. |
| `eq` | _x_, _y_ | _x == y_ | 1 if equal, 0 otherwise. |
| `mod` | _x_, _y_ | _x % y_ | Modulo function. |
| `gt` | _x_, _y_ | _x > y_ | 1 if x > y, 0 otherwise. |
| `lt` | _x_, _y_ | _x < y_ | 1 if x < y, 0 otherwise. |
| `min` | _x_, _y_ | _min(x, y)_ | x if x < y, y otherwise. |
| `max` | _x_, _y_ | _max(x, y)_ | x if x > y, y otherwise. |
| `not` | _x_ | _!x_ | 1 if x == 0, 0 otherwise. |
| `ifte` | _x_, _y_, _z_ | _x ? y : z_ | y if x != 0, z otherwise. |
| `abs` | _x_ | _abs(x)_ | -x if x < 0, x otherwise. |
| `sign` | _x_ | _sign(x)_ | 1 if x > 0, -1 if x < 0, 0 if x == 0. |
| `sin` | _x_ | _sin(x)_ | Sine function, x in degrees. |
| `cos` | _x_ | _cos(x)_ | Cosine function, x in degrees. |
| `atan2` | _x_, _y_ | _atan2(x, y)_ | Two-argument arctangent. |
| `sqrt` | _x_ | _sqrt(x)_ | Square root. |
| `round` | _x_ | _round(x)_ | Rounds to nearest integer. |
| `relu`| _x_ | _relu(x)_ | 0 if x < 0, x otherwise. |
| `clamp` | _x_, _y_, _z_ | _clamp(x, y, z)_ | y if x < y, z if x > z, x otherwise. |
| `dup` | _x_ | _x_, _x_ | Duplicates top value on the stack. |
| `swap` | _x_, _y_ | _y_, _x_ | Swaps top two values on the stack. |
| `bitwise_or` | _x_, _y_ | _x \| y_ | |
| `bitwise_and` | _x_, _y_ | _x & y_ | |
| `bitwise_not` | _x_ | _~x_ | |
| `store` | _x_, _n_ | | Puts x in register n |
| `recall` | _n_ | register n contents | |
| `time` | | current time | In milliseconds, starting at some arbitrary point. |
| `time_sec` | | current time | In seconds (but with millisecond precision), starting at some arbitrary point. Wraps less often than `time`. |
| `layer_state` | | _layer\_state_ | Bit mask of currently active layers. |
| `sticky_state` | _usage_ | _sticky\_state(usage)_ | Bit mask of layers on which given usage is in sticky state. |
| `tap_state` | _usage_ | _tap\_state(usage)_ | 1 if input is in tap state, 0 otherwise. |
| `hold_state` | _usage_ | _hold\_state(usage)_ | 1 if input is in hold state, 0 otherwise. |
| `port` | _port number_ | | Sets the value of the port register that determines which input state is fetched by `input_state` etc. Defaults to 0 at the beginning of each mapping engine iteration, which means "all ports". |
| `plugged_in` | | plugged-in state | 1 if something is plugged into the currently selected port or if selected port is 0, 0 otherwise. |
| `deadzone` | _x_, _y_, _deadzone\_radius_ | _new\_x_, _new\_y_ | Applies a radial deadzone to stick inputs.
| `deadzone2` | _x_, _y_, _inner\_deadzone_, _outer\_deadzone_ | _new\_x_, _new\_y_ | Applies a radial inner and outer deadzone to stick inputs.
| `dpad` | _left_state_, _right_state_, _up_state_, _down_state_ | d-pad output state | Takes four input states and produces a 0-8 value like the one used by the d-pad (hat switch). |
| `monitor` | _x_, _usage_ | | Sends x to the Monitor as the given usage. |

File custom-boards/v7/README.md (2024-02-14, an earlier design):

# HID Remapper custom board v7

This variant of HID Remapper is meant to be a companion device for accessibility controllers like the PlayStation Access controller and the Xbox Adaptive Controller, especially the former, since it lacks its own USB inputs.

It has fourteen 3.5mm output ports, four of which are analog outputs. Two of the analog outputs can be used for analog sticks and the other two for analog triggers.

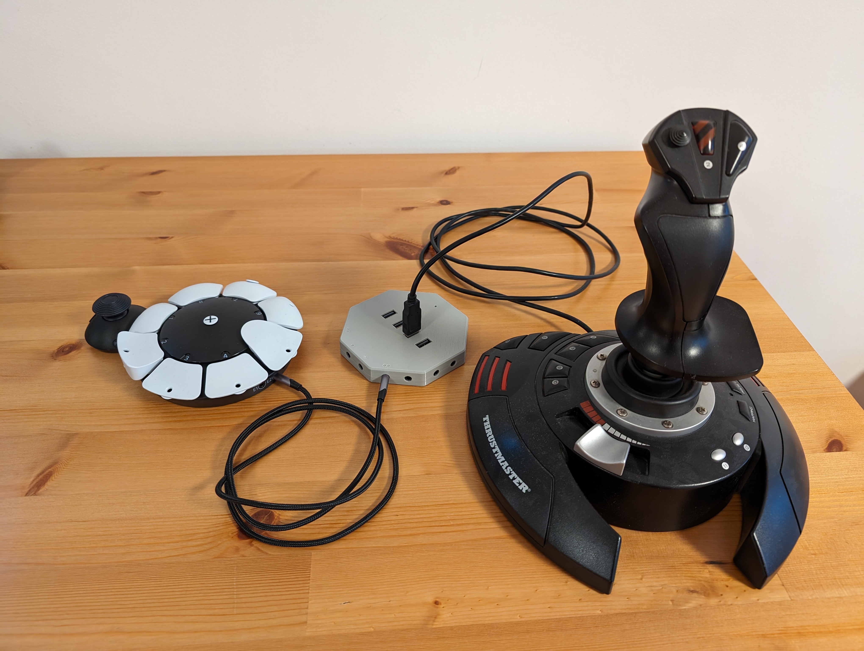
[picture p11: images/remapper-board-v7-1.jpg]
Connecting a USB joystick to the PlayStation Access controller using HID Remapper custom board v7


The way it would typically be used is you would plug some USB input device like a joystick into one of the USB ports and then configure HID Remapper to map the axes from this joystick to analog outputs. Then you would connect the analog output port on HID Remapper to a 3.5mm input port on the PlayStation Access controller with a TRRS cable. Similarly you could map buttons on your joystick to digital HID Remapper outputs (GPIOs). The ports on the PlayStation Access controller can all work as joysticks, triggers and buttons, but on HID Remapper you have to use the dedicated ports for each.

In this case the USB-C port on HID Remapper is only used for powering it and configuration. It has to be plugged into something for the device to have power, but it doesn't have to be your PS5. You can have it plugged into a PC and change the configuration on the fly, while testing it on your console in real time.

Of course you can make use of all the mapping capabilities of HID Remapper, you can connect multiple USB devices, including mice and keyboards, and configure the mappings the way you like. The only limitation is that the PlayStation Access controller only has four 3.5mm ports so even you have two of them, you're still limited to eight ports in total.

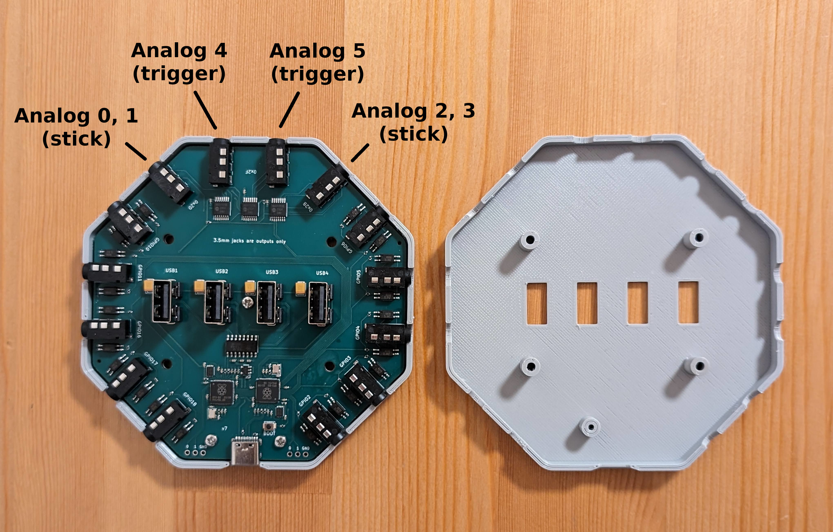
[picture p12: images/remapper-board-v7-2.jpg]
HID Remapper custom board v7 details


The 3D printed case uses three M2x4 screws and four M3x10 flat head screws.

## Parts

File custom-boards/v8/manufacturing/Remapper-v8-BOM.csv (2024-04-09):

Comment | Designator | Footprint | LCSC
1u | C15,C16,C110,C113 | Capacitor_SMD:C_0402_1005Metric | C52923
100n | C101,C102,C103,C104,C105,C106,C107,C108,C109,C117 | Capacitor_SMD:C_0402_1005Metric | C1525
15p | C118,C119 | Capacitor_SMD:C_0402_1005Metric | C1548
AudioJack4 | J1 | Jack:C18185602 | C18185602
1k | R1,R2,R106,R107 | Resistor_SMD:R_0402_1005Metric | C11702
100k | R3,R4 | Resistor_SMD:R_0402_1005Metric | C25741
27 | R103,R104 | Resistor_SMD:R_0402_1005Metric | C138021
10k | R105 | Resistor_SMD:R_0402_1005Metric | C25744
SW_Push | SW102 | Button_Switch_SMD:SW_SPST_B3U-1000P | C231329
TLV73333PDBV | U4 | SOT-23-5:SOT-23-5 | C134139
RP2040 | U103 | RP2040:RP2040-QFN-56 | C2040
W25Q128JVS | U105 | USON:8-USON | C2843335
USB_A | USB2 | Type-A:C98125 | C98125
Crystal_GND24 | Y101 | Crystal:Crystal_SMD_2520-4Pin_2.5x2.0mm | C90603

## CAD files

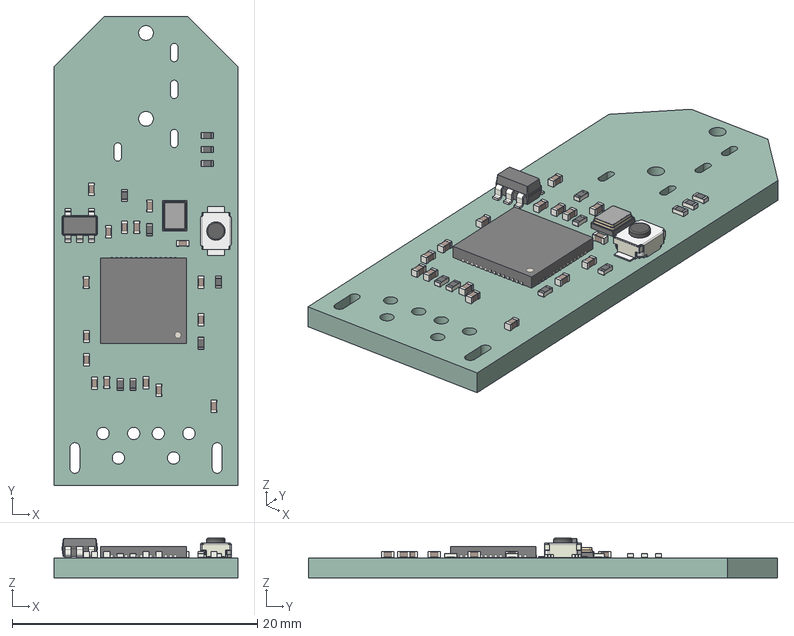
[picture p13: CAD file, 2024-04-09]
custom-boards/v8/extras/Remapper-v8-pcb.step
15.0 x 38.2 x 3.24 mm
SOT_23_5
C_0402_1005Metric x 16
R_0402_1005Metric x 9
QFN-56-1EP_7x7mm_Pitch0.4mm
Crystal_SMD_2520-4Pin_2.5x2.0mm
SW_SPST_B3U-1000P
_autosave-Remapper_PCB

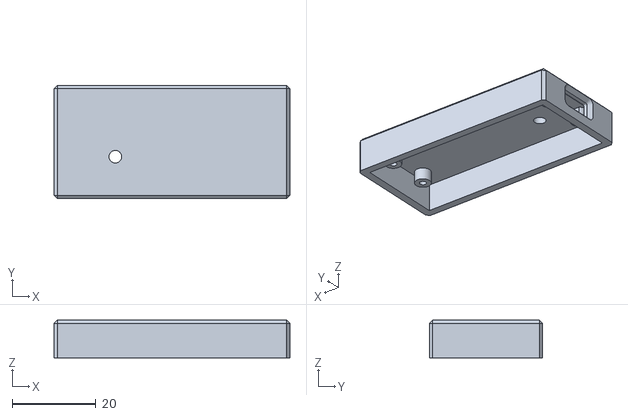
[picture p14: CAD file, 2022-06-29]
enclosure/EnclosureDualTop.stl
56.2 x 27.0 x 9.00

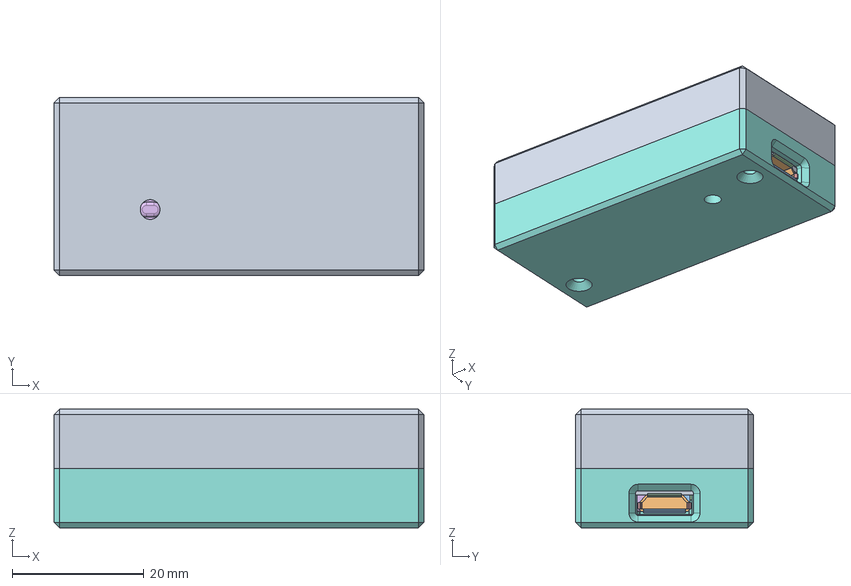
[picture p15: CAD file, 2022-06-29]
enclosure/hid-remapper-enclosure-dual.step
56.2 x 27.0 x 18.0 mm
PICO_REF_BOARD.STEP x 2
PICO_REF_USB.STEP x 2
PICO_REF_SWITCH.STEP x 2
PICO_REF_MICROCONTROLLER.STEP x 2
PICO_REF_LED.STEP x 2
PICO_REF_ONSEMI.STEP x 2
PICO_BOURNS.STEP x 2
PICO_MURATA.STEP x 4
PICO_RICHTEK.STEP x 2
PICO_DIODES.STEP x 2
PICO_AEL.STEP x 2
PICO_WINBOND.STEP x 2

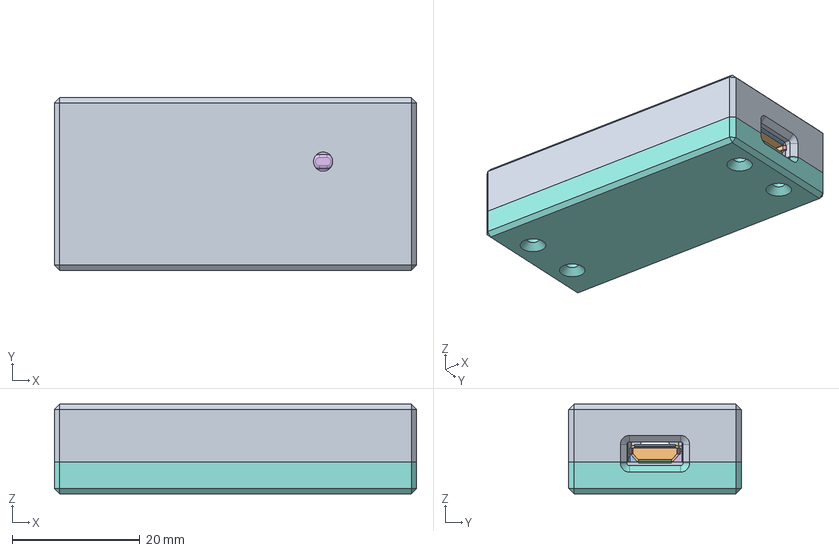
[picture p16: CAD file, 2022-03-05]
enclosure/hid-remapper-enclosure-single.step
56.6 x 27.0 x 14.0 mm
PICO_REF_BOARD.STEP
PICO_REF_USB.STEP
PICO_REF_SWITCH.STEP
PICO_REF_MICROCONTROLLER.STEP
PICO_REF_LED.STEP
PICO_REF_ONSEMI.STEP
PICO_BOURNS.STEP
PICO_MURATA.STEP x 2
PICO_RICHTEK.STEP
PICO_DIODES.STEP
PICO_AEL.STEP
PICO_WINBOND.STEP

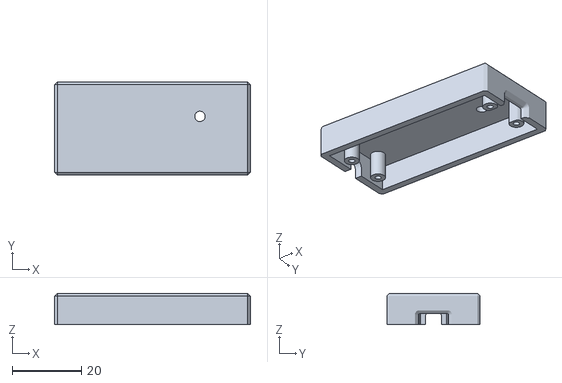
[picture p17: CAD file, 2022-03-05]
enclosure/EnclosureSingleTop.stl
56.6 x 27.0 x 9.00

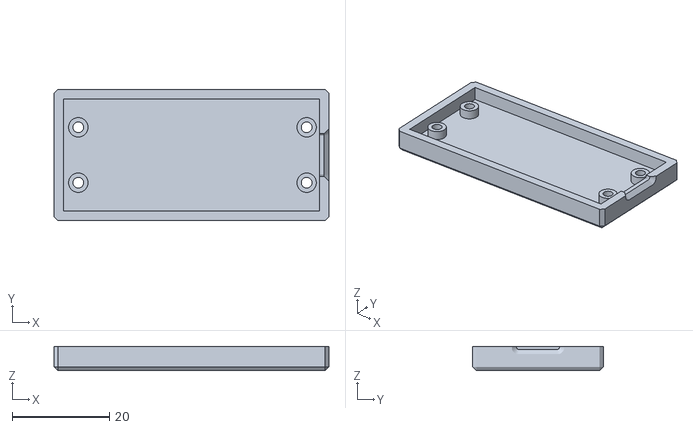
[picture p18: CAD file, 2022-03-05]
enclosure/EnclosureSingleBottom.stl
56.6 x 27.0 x 5.00

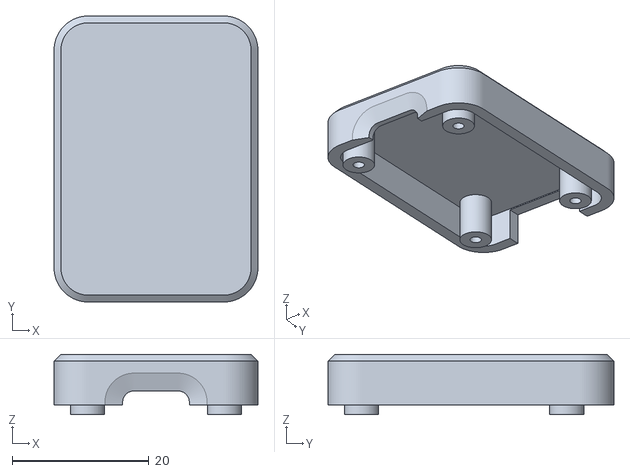
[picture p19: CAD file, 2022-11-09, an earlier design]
custom-boards/v1/3d-printed-case/Remapper-v1-Top-no-holes.stl
29.8 x 41.8 x 8.80

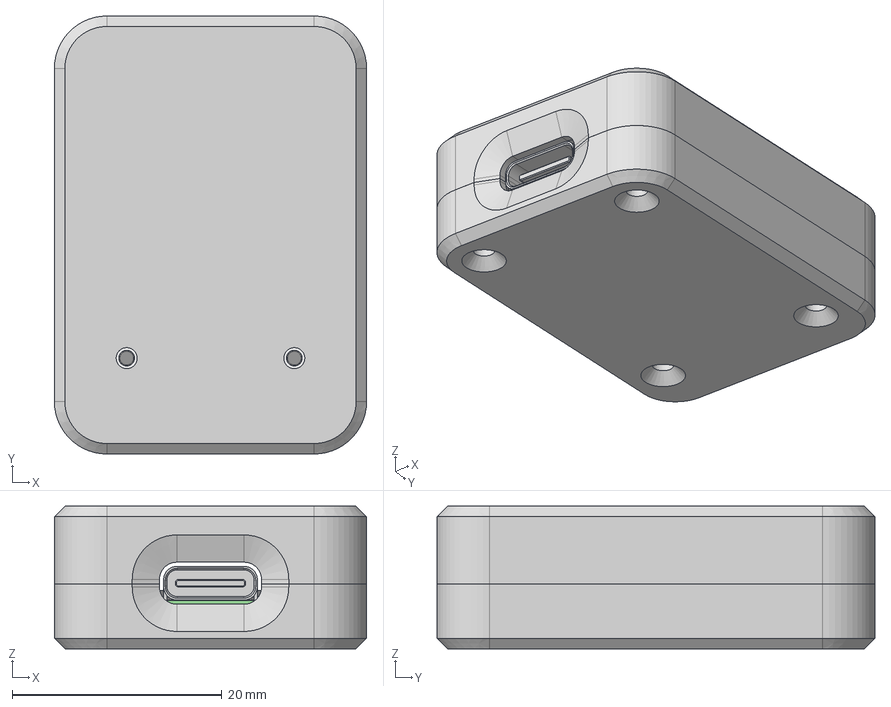
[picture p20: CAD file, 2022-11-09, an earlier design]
custom-boards/v1/extras/Remapper-v1-case.step
29.8 x 41.8 x 13.6 mm
Remapper PCB

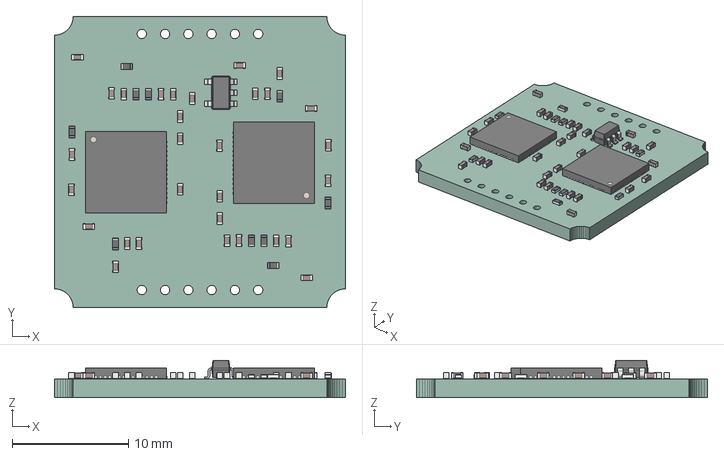
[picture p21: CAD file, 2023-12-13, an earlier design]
custom-boards/v2/extras/Remapper-v2.1-pcb.step
25.0 x 25.0 x 3.18 mm
PCB

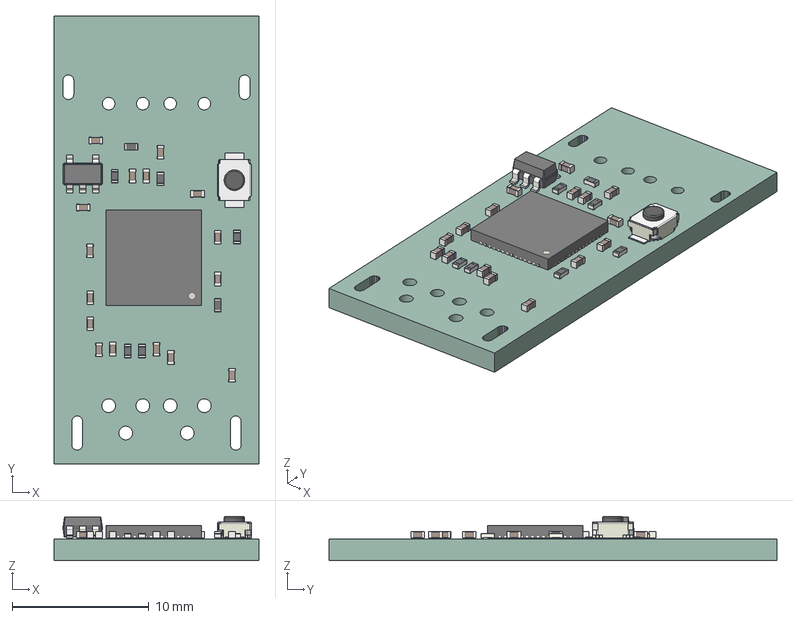
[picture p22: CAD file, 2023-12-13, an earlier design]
custom-boards/v3/extras/Remapper-v3.1-pcb.step
15.0 x 32.8 x 3.22 mm
PCB

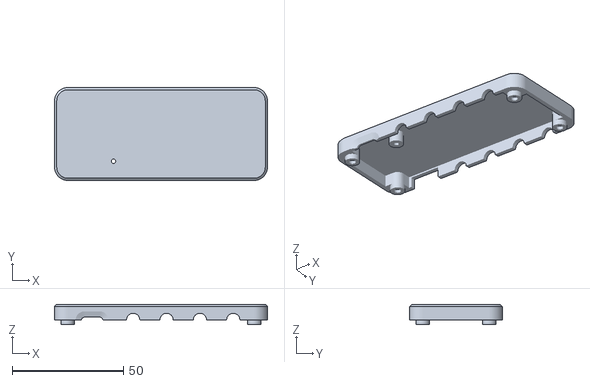
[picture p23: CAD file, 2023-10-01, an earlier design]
custom-boards/v4/3d-printed-case/Remapper-v4-Top.stl
95.8 x 41.8 x 9.22

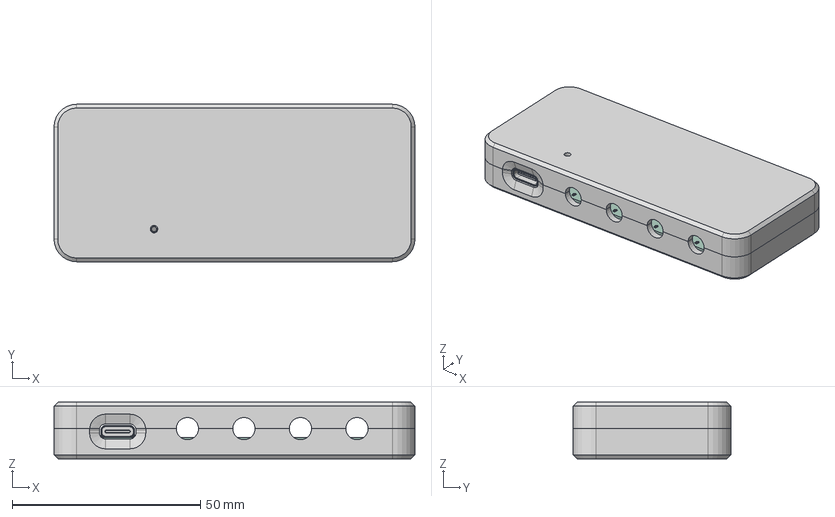
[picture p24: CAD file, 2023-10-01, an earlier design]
custom-boards/v4/extras/Remapper-v4-case.step
95.8 x 41.8 x 15.0 mm
PCB

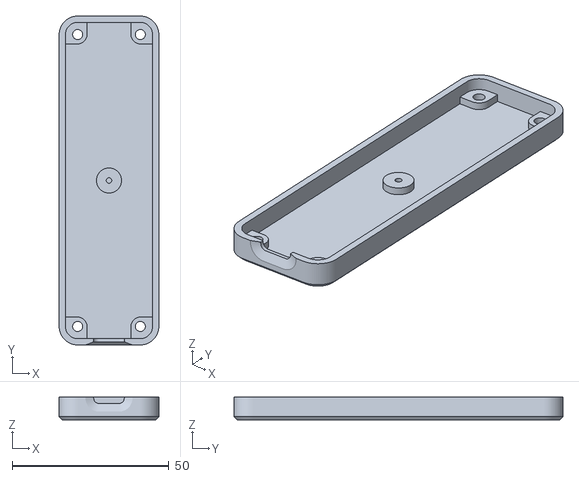
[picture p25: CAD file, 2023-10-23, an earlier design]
custom-boards/v5/3d-printed-case/Remapper-v5-Bottom.stl
31.8 x 104.8 x 7.23

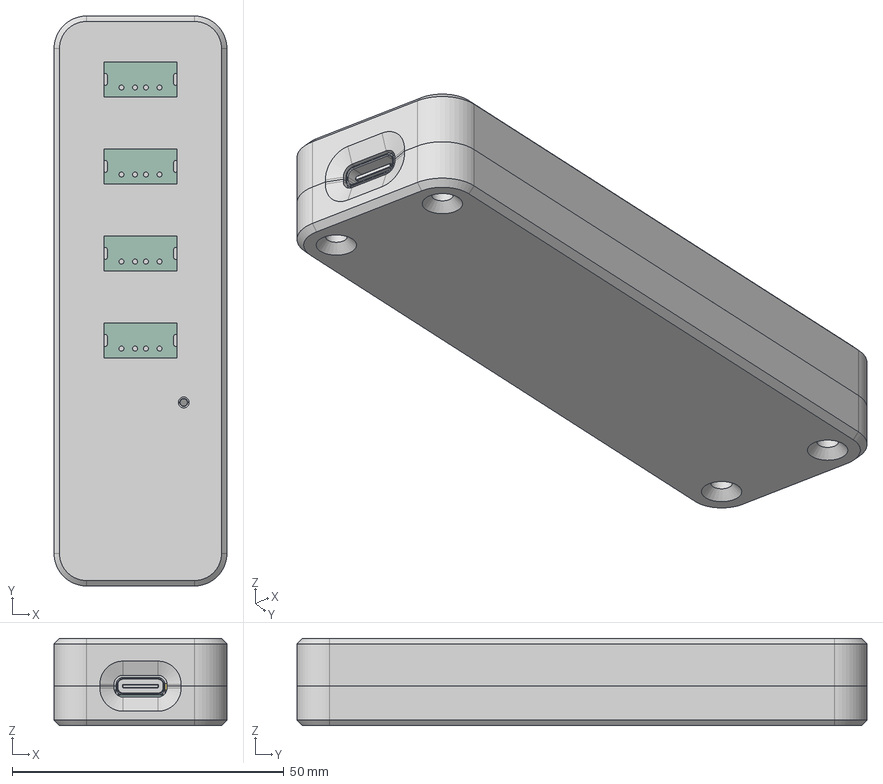
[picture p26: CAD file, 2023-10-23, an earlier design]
custom-boards/v5/extras/Remapper-v5-case.step
31.8 x 104.8 x 16.0 mm
PCB

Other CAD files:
enclosure/EnclosureDualBottom.stl
custom-boards/v6/3d-printed-case/Remapper-v6-Top-with-labels.stl
custom-boards/v7/3d-printed-case/Remapper-v7-Top-with-labels.stl
custom-boards/v1/3d-printed-case/Remapper-v1-Bottom.stl
custom-boards/v1/3d-printed-case/Remapper-v1-Top-with-holes.stl
custom-boards/v4/3d-printed-case/Remapper-v4-Bottom.stl
custom-boards/v5/3d-printed-case/Remapper-v5-Top.stl
custom-boards/v6/3d-printed-case/Remapper-v6-Bottom.stl
custom-boards/v6/3d-printed-case/Remapper-v6-Top.stl
custom-boards/v7/3d-printed-case/Remapper-v7-Bottom.stl
custom-boards/v7/3d-printed-case/Remapper-v7-Top.stl

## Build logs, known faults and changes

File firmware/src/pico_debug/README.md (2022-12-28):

Derived from [essele/pico\_debug](https://github.com/essele/pico_debug). MIT license.

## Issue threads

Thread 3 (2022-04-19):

Overclocking MLT04 mice (IMO 1.1a specifically), mouse won't respond?

yourrandomnobody, 2022-04-19:
Hello, these are the steps I've done:
-Got microUSB to USB cable from my motorola charger
-Held the BOOTSEL button (while having microUSB put in) and inserted the USB part in my PC
-Linux/Windows found the RPI Pico, opened the folder up and inserted the remapper.uf2 file inside
-Folder closed, all things are still plugged in
-Opened up the website and connected the mouse to the soldered USB hub
-Mouse has LED's turned on but it doesn't recognize any input?
I've tried mapping cursor X and Y, etc. to the same outputs but to no avail. I feel like I'm either connecting the mouse early/late or not using the website right, any help?

https://youtu.be/nxhV84Gcb0g

https://cdn.discordapp.com/attachments/263456086001057804/966016984535928892/20220419_184516.jpg

jfedor2, 2022-04-19:
Hi,

In theory it should work without using the website at all (it's not very useful that way, but it should at least move the cursor).

Do you have some other USB mouse (or keyboard) to try and check if it's a problem with the Pico setup or this particular mouse?

yourrandomnobody, 2022-04-19:
The mouse by itself works fine, when directly plugging into the USB port of my motherboard (I am using the USB2.0 port btw)
Tried another mouse, problem still persists.
Is it possible that the soldering is bad? Or perhaps the female USB plug is faulty?

jfedor2, 2022-04-19:
Yeah, I meant that perhaps the remapper doesn't like this particular mouse for some reason, not that it doesn't work otherwise. I've had it happen with one mouse in the past.

If no other device works when plugged into the remapper then I would definitely check the wiring.

michelwoo, 2022-04-23:
To add to this. I also have issues with the io1.1a not moving or clicking at all. Another mouse that also doesnt move is the finalmouse ultralight capetown. I've tried a different mouse (Vaxee NP01) and that works. @jfedor2 Is it possible to adjust the remapper to work with other mice?

jfedor2, 2022-04-23:
As mentioned above, it looks like the library that I'm using for the device side (the one which you connect your mouse to) doesn't like certain devices, I'm not sure why. The issue has been reported to the author: https://github.com/sekigon-gonnoc/Pico-PIO-USB/issues/18

I can't speculate on what the chances are for a fix.

On my side I'm considering making a version of the remapper that wouldn't use that particular library and instead would use two Pico boards, one for the host and one for the device USB interface (with the two sides communicating over serial or whatever). The idea being that the native hardware USB of the Pico should hopefully work with more (all) devices as it's more mature than the bit-banging library.

michelwoo, 2022-04-23:
Ahh I see. Yeah a "double" pico board would be nice if it would work with all mice.

jfedor2, 2022-04-24:
@yourrandomnobody @michelwoo There might still be hope for the current hardware. If you have a moment, please try this firmware, in my tests it worked with at least one mouse that didn't work with the regular firmware.

[remapper-experimental-2022-04-24.zip](https://github.com/jfedor2/hid-remapper/files/8550493/remapper-experimental-2022-04-24.zip)

There are some caveats, in my tests it sometimes stopped working randomly, so try connecting and disconnecting a few times if possible.

Also the overclocking setting currently doesn't work - it will work as if set to 1000 Hz regardless of which option you choose.

But it might provide some guidance on whether this path is worth pursuing.

yourrandomnobody, 2022-04-25:
>

This one made my WMO and IMO 1.1a work! Cursor, left and right mouse button works. The scroll wheel doesn't work however.

jfedor2, 2022-04-25:
@yourrandomnobody Yeah, the scroll wheel is a silly mistake, changing the library inadvertently made the mouse work in boot protocol mode. That should be an easy fix. But overall it's a good result, it means that it works on the hardware level.

I think we can followup on the polling rate stability once I manage to make the rate configurable again in this version. Stay tuned.

yourrandomnobody, 2022-04-26:
@jfedor2 Great to read! Also, the polling rate stability was an issue in the original .uf2 file as well, just wanted to clarify.
It's not something from this experimental build.
Eagerly waiting for the new version to test!

michelwoo, 2022-04-27:
Awesome to hear @jfedor2 , looking forward to trying the next verison

shriramhr, 2022-05-11:
> @yourrandomnobody Yeah, the scroll wheel is a silly mistake, changing the library inadvertently made the mouse work in boot protocol mode. That should be an easy fix. But overall it's a good result, it means that it works on the hardware level.
>
> I think we can followup on the polling rate stability once I manage to make the rate configurable again in this version. Stay tuned.

Hi,
First of all, thanks a ton for making this 🙏
Been trying to figure out a way to do this myself for a while, never got to it though thinking its way more complicated than it looked. Obviously I was wrong.

I newer experimental firmware solves the issues for most mice. As it has been mentioned, only the scroll is an issue. Just wondering what steps were taken to generate/compile the uf2 file? Is the same library available for other rbp models, especially ones which can be configured as high speed devices? If so then we can oc at higher clock speeds I believe.

jfedor2, 2022-05-13:
> I newer experimental firmware solves the issues for most mice. As it has been mentioned, only the scroll is an issue. Just wondering what steps were taken to generate/compile the uf2 file?

@shriramhr

Scroll is an easy fix like I mentioned, I will make a new version with that and hopefully make the polling rate override configurable again, I'm just waiting for the merges in the tinyusb and pio-usb repositories to happen so that we're tracking a somewhat stable target (though some changes on top of that will probably still be needed for the overclocking).

If you want to compile this yourself, the steps are pretty much the same as for the pico-sdk examples. Something along the lines of:

```
git clone https://github.com/raspberrypi/pico-sdk.git
cd pico-sdk && git submodule update --init
export PICO_SDK_PATH=`pwd`
cd ..
git clone https://github.com/jfedor2/hid-remapper.git
cd hid-remapper
mkdir build
cd build
cmake ..
make
```

(Note that the "experimental" changes aren't pushed to the repository yet, so this would get you the normal, "stable" firmware currently.)

> Is the same library available for other rbp models, especially ones which can be configured as high speed devices? If so then we can oc at higher clock speeds I believe.

If you're referring to the "big" (non-Pico) Raspberry Pis that run Linux then no, the library won't run on them. Though the general idea should be doable on them as they can act as both USB hosts and devices AFAIK.

shriramhr, 2022-05-14:
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

Thanks for the reply. I wanted to check if i can fiddle around with the code. Right now more than any other mouse I wanted to get the dell ms116 working with 1000hz. The experimental firmware works for it but its glitchy. Like holding left/right click doesnt work, it just does multiple clicks and in general it stutters a bit. I think it can be fixed in code. The intelli mice work flawlessly though.

jfedor2, 2022-06-13:
Hi guys,
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
jfedor2, 2022-06-13:
> Just a quick question - will this double pico setup cause any sort of extra input delay? Will it be like around 200us ish or so or like 1ms since both will be running at 1KHz?

In my tests it adds ~0.9ms latency on average. The single Pico version is essentially the same.

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

(Using this setup: https://inputlag.science/controller/methodology )

shriramhr, 2022-06-14:
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

Thanks a ton for the extra effort. I'll make this and let you know how it goes

shriram-es, 2022-06-14:
Not sure if it's some loose contact in my otg cable or the jumper wires, it doesn't seem to work right now. Probably some loose contact, ordered some new wires and an otg cable.

shriram-es, 2022-06-15:
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

DUUUUUDE! I got it to work like a charm! Basically old wires were useless... now I've tried all MLT04 mice + old Dell MS116 mouse.... works flawlessly

jfedor2, 2022-06-15:
> DUUUUUDE! I got it to work like a charm! Basically old wires were useless... now I've tried all MLT04 mice + old Dell MS116 mouse.... works flawlessly

Glad to hear that. Thank you for testing!

I will add some docs and hopefully a case for the dual Pico version in the future.

urfdvw, 2022-06-21:
Just a comment.

Are you interested in documenting the signal from board B?
This can be a good replacement for [USB Host Co-Processor](https://github.com/gdsports/usbhostcopro),
which is not active any more, and sadly not working for many of my devices.

I am only familiar with Arduino and CircuitPython,
and that is why I am not very ready to fork and contribute to this repo directly.
If signal from board B is understood,
that opens possibility for me to make a board A' that runs CircuitPython.

This is just my thoughts,
by no means to be any push or priority.

jfedor2, 2022-06-25:
> Are you interested in documenting the signal from board B?
> This can be a good replacement for [USB Host Co-Processor](https://github.com/gdsports/usbhostcopro),
> which is not active any more, and sadly not working for many of my devices.

Yeah, I still need to document the dual Pico version properly.

The A-B protocol is very much "ad-hoc" and suited to this particular use case, but perhaps with a little modification it could serve your purpose as well.

I uses a 4 million baud serial link with hardware flow control (RTS/CTS lines connected). On top of that it sends packets as defined in RFC 1055 (simple byte stuffing). Each packet's payload is followed by its CRC32.

Possible packet types are defined in dual.h.

The B side can send the following packet types:

DEVICE_CONNECTED (comes with HID report descriptor)
DEVICE_DISCONNECTED
REPORT_RECEIVED
REQUEST_B_INIT

The A side can send the following:

B_INIT (contains configuration, currently only the polling rate override parameter)
RESTART (tells the B side to restart, needed if the polling rate override is changed)

The B side starts by sending REQUEST_B_INIT in a loop until it receives B_INIT. Then it sends the DEVICE_CONNECTED/DISCONNECTED and REPORT_RECEIVED packets as appropriate.

This is just a quick description, but if you're familiar with Arduino you should be able to read the relevant source files and figure out the details. Again, it would probably make more sense to modify the B side a bit to serve the more generic use case. Also keep in mind it only supports USB HID (not MIDI for example).

schwarz, 2024-03-21:
@jfedor2 Are MLT04 mice (WMO) supposed to work with the Adafruit Feather RP2040 board or only with two Picos?
Trying the Feather board the mouse (and others of the same make) is not lighting up.

jfedor2, 2024-03-21:
> @jfedor2 Are MLT04 mice (WMO) supposed to work with the Adafruit Feather RP2040 board or only with two Picos? Trying the Feather board the mouse (and others of the same make) is not lighting up.

I don't know, I don't have one to test. There was certainly a time when it didn't work with a single RP2040, but compatibility has improved for some devices since then. But if it doesn't work for you then apparently not for these.

shriramhr, 2024-03-21:
> @jfedor2 Are MLT04 mice (WMO) supposed to work with the Adafruit Feather RP2040 board or only with two Picos? Trying the Feather board the mouse (and others of the same make) is not lighting up.

Hey,

So I had this working with a single pico board a while ago but I think the scroll wheel did not work or some such but after that I tried with 2 picos and all the old mice I tried worked including the ime 3.0, mx518 etc.

Closed 2022-06-29.

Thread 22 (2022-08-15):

Question regarding high speed instead of full speed usb for >1khz polling

shriramhr, 2022-08-15:
Hi JF,

Is there a way to program the pico so that it selects usb high speed instead of full speed? If this is possible then maybe devices can be forced to poll at greater than 1 KHz.

jfedor2, 2022-08-15:
The hardware doesn't support High Speed. The Pico-PIO-USB library doesn't either.

shriramhr, 2022-08-15:
> The hardware doesn't support High Speed. The Pico-PIO-USB library doesn't either.

So technically if this code can be replicated for a different pi board which supports HS usb, it should work right?

jfedor2, 2022-08-15:
In principle, yes. Some parts of the code are specific to the RP2040, in particular the overclocking stuff, but something similar could be done on another chip.

Closed 2022-09-06.

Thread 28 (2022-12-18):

Question: Support for wired Apple Magic Keyboard?

GhostInTheSteiner, 2022-12-18:
I'm currently considering to use your guide to use an Apple Magic Keyboard on Windows. I could mostly solve mapping problems with autohotkey so far, but for RDP sessions or virtual machines these autohotkey scripts won't work for obvious reasons.

My plan would be to buy the v1 board from JLCPCB and then use it on a Windows based OS.

I'm somewhat worried because the Magic Keyboard is custom tailored for Mac computers, although it works on Windows just fine with some swapped buttons like Alt and Win.

Are your boards are compatible with the Magic Keyboard? Or is there something I should take into consideration before ordering the boards?

peterburk, 2024-08-22:
I tried building it today (both the single Pico and dual Pico variants) and the Magic Keyboard A1843 does not work :(

I'll be looking into the reasons why, and trying to find a solution.

peterburk, 2024-08-29:
The problem is in enumeration in Pico-PIO-USB, so I've raised an issue with that project.

[https://github.com/sekigon-gonnoc/Pico-PIO-USB/issues/135](https://github.com/sekigon-gonnoc/Pico-PIO-USB/issues/135
)

peterburk, 2024-08-29:
Trying with the `host_cdc_msc_hid` example, I had some success!

```
 TinyUSB Host CDC MSC HID Example
HID device address = 1, instance = 0 is mounted
HID Interface Protocol = None
HID has 2 reports
HID device address = 1, instance = 1 is mounted
HID Interface Protocol = Keyboard
A device with address 1 is mounted
```

Typing on the keyboard then emits serial packets.

However, the CAPS lock LED doesn't turn on when it's pressed.

Closed 2022-12-19.

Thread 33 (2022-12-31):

Support for standalone Linux app on (Raspbian)?

AdrianKielbowicz, 2022-12-31:
Hey, not sure if this is the right place to ask questions but here it goes.. Will the hid-remapper work as a standalone app on Raspbian or any other Linux OS?

I would like to use a full OS so pico is not cutting it for me.

If the answer is no, would you be able to recommend a similar software that allows keys to be re-mapped in software? I've been digging into xmodmap but still unsure if I can remap 1 key to multiple I.e. key number 1 for example to ALT+SHIFT+F18 etc.

michelehokuto, 2022-12-31:
i don't understand your purpose. Do you want create custom shortcut on your rasperryPi/other distro?

AdrianKielbowicz, 2022-12-31:
> i don't understand your purpose. Do you want create custom shortcut on your rasperryPi/other distro?

I would like to use the hid-remapper on a fully fledged OS like Raspbian and not just execute the code on a pico or custom board. So a standalone application is what I am after that you can run within Linux. Does that make sense?

claviger-pc, 2022-12-31:
You could use xmk on Linux, but I think there are desktop specific remapping possibilities as well.
https://github.com/manna-harbour/xmk

b-, 2023-01-03:
> > i don't understand your purpose. Do you want create custom shortcut on your rasperryPi/other distro?
>
> I would like to use the hid-remapper on a fully fledged OS like Raspbian and not just execute the code on a pico or custom board. So a standalone application is what I am after that you can run within Linux. Does that make sense?

I understand what you want, and I think I could help, but before I get to that I need to say that I think you might be misunderstanding the point of this project and the Pico/custom board's purpose. You're not supposed to use the Raspberry Pi Pico as a computer at all. In the case of this project it's acting sort of as a mouse "driver" implemented in hardware. You plug your mouse (or other input device) into whatever you've programmed with the HID-remapper firmware, and then you plug the other end of that device into your computer.

This way, your computer doesn't need to spend any extra CPU time remapping your inputs (which can add some latency and jitter, especially if the computer is under load from other things). In my opinion, HID drivers should almost invariably be running with near-realtime priority and performance so that you never have to worry about your computer keeping up with how fast you can type or click :)

_That said,_ if you really want to remap your input devices via software on your operating system, there are definitely some awesome projects out there to do so. I used a few myself before switching to hardware running QMK and this HID remapper. The big downsides to such software solutions are that if the software has a problem you might need to reboot your computer or something, and if you use more than one computer you'll need to set up something on each one you want to remap your inputs on. And for that matter, if you want to remap your inputs on more than one operating system you need to use a different software tool for each one.

But here's a list of things I used before coming across QMK and this repository:

For Linux, I have to mention [Interception-Tools](https://gitlab.com/interception/linux/tools). I used their example caps2esc script for the longest time.

For macOS, use [Karabiner-Elements](https://github.com/pqrs-org/Karabiner-Elements) and/or [Steermouse](https://www.plentycom.jp/en/steermouse/).

For Windows, use [X-Mouse Button Control](https://www.highrez.co.uk/downloads/XMouseButtonControl.htm) or [AutoHotkey](https://autohotkey.org).

All of these tools have their own pros and cons, but in my opinion the biggest problems with them are that they're all different. Even X11 and Wayland treat the mouse a little differently, so the behavior of these sorts of tools becomes entirely dependent on the computer you're using. If you use something like HID-remapper or a mouse/keyboard with QMK or similar firmware, or the XMK firmware proposed above, you'll solve all of these problems by sticking a dongle between your computer and your mouse.

Closed 2023-05-26.

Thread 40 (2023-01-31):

Bug: Low-speed USB devices are not recognized

kelnishi, 2023-01-31:
For single Pico PIO setup. Keyboards operating in USB Low-Speed 1.5Mbps mode are not recognized.

jfedor2, 2023-01-31:
If you have a moment, please try this build. It uses an updated version of the pico_pio_usb library and in my tests it helped with some devices. (Unfortunately it also seems to break some other devices, which is why I haven't put this in the normal release yet.)

[remapper-newer-pio-usb.zip](https://github.com/jfedor2/hid-remapper/files/10551049/remapper-newer-pio-usb.zip)

kelnishi, 2023-02-01:
This newer firmware does indeed work with low-speed (1.5Mbps), however it no longer works with high-speed (12Mbps). The latest host_hid_to_device_cdc.c from Pico-PIO-USB does recognize both speed devices and can successfully hot plug both in succession.

jfedor2, 2023-02-01:
Interesting. I need to look into this. Thank you for testing.

jfedor2, 2023-02-03:
So the difference between HID Remapper and the host_hid_to_device_cdc example is that HID Remapper uses the Pico-PIO-USB library directly, while host_hid_to_device_cdc uses it as a backend to tinyusb. I've tried this setup before, but I've ran into some issues, I don't remember the details. I've tried it again with the current versions of tinyusb and Pico-PIO-USB and everything seems to work fine and it does work with some devices that the current single Pico version doesn't. In fact it seems to work with all the devices I have, except some hub that has issues even with the dual Pico version.

Here's a single Pico test build that uses Pico-PIO-USB as a backend to tinyusb if you're up for some more tests.

[remapper_pio_tinyusb_backend.zip](https://github.com/jfedor2/hid-remapper/files/10581923/remapper_pio_tinyusb_backend.zip)

kelnishi, 2023-02-03:
This one successfully connects to all the devices I have (HS keyboard, LS keyboard, HS wireless mouse dongle).
I do see an error when using the configuration tool however:
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
This error happens when saving the configuration to device. Once it's in this state, further configuration is not possible and a hard reset (via the pico reset button) is required. The configuration does appear to make it to the board before the error though, so once the pico is rebooted, the remappings are present.

jfedor2, 2023-02-03:
Hmm this kind of sounds like the issues I had with this setup before, but weirdly I'm not experiencing them now.

petrm, 2023-02-06:
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

This build works for me with Kinesis Freestyle 2. The default release doesn't send any keys.

jfedor2, 2023-02-06:
@petrm Do you see any issues when clicking "save to device" on the web config interface with this build?

jfedor2, 2023-02-06:
@kelnishi Do you get the error every time you save the settings to the device? I'm tempted to put this change in the regular release, but not with this problem, obviously.

kelnishi, 2023-02-07:
The NotAllowedError issue when saving the mapping configuration happens 100% for me. In chrome for Windows and macOS. I'm running on an rp2040-zero board without debug pins exposed. I can solder up some other boards with TTL pins to see if I can get more debug for you if that will help.

kelnishi, 2023-02-07:
I wonder if TinyUSB is causing Chrome to be more restrictive with sendReport. Seems like access to HID devices like keyboards is intentionally handicapped https://github.com/WICG/webhid/issues/12#issuecomment-645487885

jfedor2, 2023-02-07:
That's not it, on the computer-facing side all versions use tinyusb, this change only affects the mouse-facing side. And if reading the configuration works, then it means sending reports works. The NotAllowedError can be misleading, it also happens when the device crashes for some reason and stops responding at all. In this case it looks like it crashes when writing the configuration to flash.

It's good that you mentioned that you're using an RP2040-Zero board and not a Pico. I will test with an RP2040-Zero and see if I'm able to reproduce. Usually they work the same, but maybe a different flash chip makes the write take a little longer or something.

kelnishi, 2023-02-07:
I've done some more tests and I've narrowed down the crash/NotAllowedError.
If a HS (12Mbps) USB keyboard or mouse is plugged into the board when mappings are saved, the board will freeze and/or NotAllowedError will present. LS devices do not seem to be affected.

The problem occurs on all the boards I've assembled:
- Raspberry Pi Pico
- RP2040-Plus
- RP2040-Zero

Both HS and LS devices work correctly on all the boards.
Saving mappings does succeed even when the board freezes, a hard reset will get it functioning again.
Unplugging the HS devices prior to saving mappings will allow the mappings to be saved without freeze/crash. The device can then be re-plugged after saving and the board will continue to function normally.

petrm, 2023-02-08:
> @petrm Do you see any issues when clicking "save to device" on the web config interface with this build?

No issues, I am using RP2040-Zero.

jfedor2, 2023-02-08:
Oh, so it's not board-specific, but depends on what device is connected. What devices are you using specifically, @kelnishi ? I don't think it's as simple as low-speed vs. full-speed, at least I'm not able to reproduce it with my FS devices.

jfedor2, 2023-02-08:
@kelnishi

OK, so this is a bit of a shot in the dark as I'm not able to test it on my side, but if you haven't had enough yet, please try this build and see if it makes any difference.

(The change is that I'm no longer disabling interrupts before writing to flash - it shouldn't be necessary on the single Pico version as the code is always running from RAM anyway.)

[remapper_do_not_disable_interrupts.zip](https://github.com/jfedor2/hid-remapper/files/10686908/remapper_do_not_disable_interrupts.zip)

jfedor2, 2023-02-08:
Oh, cool! Thank you for all the testing.

Closed 2023-02-08.

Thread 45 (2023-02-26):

Can't pair on NRF52840. No Bluetooth device visible

Warpshock, 2023-02-26:
Flashed the appropriate firmware on Seeed nRF52840.
Solid blue light when plugged in.
Successfully connected through web tool and clicked pair.
No bluetooth signal visible to laptop or cell phone (S22 Ultra).
I tried nRF Connect app and still don't see it.
Flashed SEEED "HID Keyboard Demo" and that works correctly. [Wrote down MAC address]
Reflashed hid-remapper, but still can't find it.

Can you help?
Thanks!!

jfedor2, 2023-02-26:
There might be some confusion as to what the Bluetooth version (currently) does.

You connect it to your computer via USB and then you connect a mouse or keyboard to it via Bluetooth, not the other way round.

Warpshock, 2023-02-27:
That's how I thought it worked. I failed to mention that I tried pairing with a Logitech Harmony Keyboard and with a Logitech MX 3 Mouse (both) BLE. I tried both the web button and shorting pin 0 to ground for several seconds. Neither caused the solid blue led to change. Clearing all devices did cause a flash.

I tried thought it should be visible to the nRF Connect app, even if it was not broadcasting its name.

jfedor2, 2023-02-27:
Did you put your peripherals in pairing mode? Can you see *them* in nRF Connect?

jfedor2, 2023-07-24:
Can you install the nRF Connect app on your phone and see if the keyboard is visible there?

orbit3r, 2023-07-26:
I did, the keyboard actually doesn't show up on scan despite showing up and being pairable with my Desktop pc using an intel ax200 wifi/bluetooth card (I put it in pairing mode using another one of the 3 pairing slots)
I assume the issue is with my keyboard, any idea on how to troubleshoot this?

jfedor2, 2023-07-26:
It's not that there's anything wrong with your keyboard, but if you can't see it in nRF Connect then it most likely uses Bluetooth Classic, not Bluetooth Low Energy. HID Remapper only works with Bluetooth LE devices (currently).

Closed 2023-05-26.

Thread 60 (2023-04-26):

feather_rp2040_usb_host need to have GPIO18 enabled to USB to work

dglaude, 2023-04-26:
The USB 5V on the Feather is controlled by RP2040 GPIO18.
That need to be set to ouput and "True" to have the Green LED next to the USB turn on and the external keyboard/mouse be powered.
Else the behaviour is random, and my board does not behave like the one of ATmaker that is working on a fix.

ATMakersBill, 2023-04-26:
I've got a fix to this (its' straightforward) and it's confirmed - I can turn on and off the USB at will.  Might also be a good feature to expose via the web interface (handy to turn off/on the device).

I'm setting up a fork so I can do a pull request with this fix, but for anyone waiting the fix is easy:
Add
`#include <pico/stdlib.h>`
to the top of main.cc (not inside the extern "C" block)
then add this just before the main loop
```
    /* On the Feather Host board, the 5V boost converter needs to be turned on
       If not, the pin is floating and it may/may not be enabled */
#ifdef FEATHER_HOST_BOARD
#define POWER_5V_PIN 18
    gpio_init(POWER_5V_PIN);
    gpio_set_dir(POWER_5V_PIN, GPIO_OUT);
    gpio_put(POWER_5V_PIN, 1);
#endif
```

jfedor2, 2023-04-26:
Ugh. There's supposed to be a pull-up resistor on that pin (at least it's on the schematic).

ATMakersBill, 2023-04-26:
Well, it's an easy fix - I have a fork setup - I was going to add the log() stuff to it but I can do this first if you want a pull request.  If not you can just copy/paste.

It might be that the pull-up's not adequate or it's a defect in the board.  Not a bad idea to set the pin anyway

ATMakersBill, 2023-04-26:
Ok - I'll leave this to you then - David's got a custom build and is making progress

dglaude, 2023-04-26:
> Yeah, it's no problem, driving that pin is even already present in TinyUSB (https://github.com/hathach/tinyusb/blame/master/hw/bsp/rp2040/family.c#L128) so it's just a matter of adding a define. I just thought it wasn't necessary.

Sorry, I cannot explain the why...
The board of @ATMakersBill was working without this fix.
My board does not power up the 5V without this patch.

First I was thinking my board was dead on arrival.
So I booted into Circuit Python where I was able to turn on the power with GPIO18.
My board was OK but not behaving exactly like his board.

@ATMakersBill tested on his board that he could turn off the power on his board, and then reversed to turn on the power. I tested his patched UF2 and it works for me (and still works for him).

For me, this change is a must have, else I cannot even use the board.

jfedor2, 2023-04-26:
Of course, it's no problem. Please try this build if you can, it should contain the same fix:

https://github.com/jfedor2/hid-remapper/releases/download/r2023-04-26/remapper_feather.uf2

dglaude, 2023-04-26:
It works perfectly.
( also it is really useful to be able to jump to UF2 mode directly from https://www.jfedor.org/hid-remapper-config/ )

jfedor2, 2023-04-26:
Awesome, thank you!

Closed 2023-05-26.

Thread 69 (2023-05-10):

feature request: hard reset

itsnoteasy, 2023-05-10:
I have some hardware, both logitech mouses, g102 and g502, also a teensy 2.0 based keyboard, that occasionally need to be unplugged and re inserted to wake them up. I haven't used any of them with the hid remapper yet, but i was looking at a video on youtube of how usb speed is negotiated by enabling the pullup resistors one at a time on d+ and d-.  link here https://hackaday.com/2023/05/09/minimal-usb-device-connects-with-just-a-couple-of-resistors/#comments

anyway, i figure you could add a watchdog timer feature that detects when a device stops responding and if so, disables the pullups for a few seconds so it appears that the device has been unplugged. i'm not sure if that would work to wake them up, but it seems like an easy thing to do so what do you think.

ATMakersBill, 2023-05-10:
If you're using the Adafruit Feather USB Host, you can also turn off the 5V regulator via a pin (18?) and that would completely reset the device

itsnoteasy, 2023-05-11:
good to know, but that device would be rare both due to limited availability and increased price compared to the alternative. I'm  not sure is the proposal a good idea even. not everyone wants to run buggy hardware that could die at any time, but a device that only dies at system boot is usable.

Closed 2023-05-23.

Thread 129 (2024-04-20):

HID Remapper with hand held speechmike

whyaaronbailey, 2024-04-20:
HID Remapper doesn't seem to recognize or react to button presses from the Nuance PowerMic II. Please see the attached USB capture. I have two projects: one is to remap the buttons from the PowerMic to macros, for which I hope to use HID Remapper. I currently use AHKHID and autohotkey to accomplish this, but I'm looking for a solution that requires no software to be installed on the PC, hence HID Rempapper.  PowerMic API is attached.

I'm also trying to replicate the effects of the "record" and other buttons on the PowerMic using my QMK keyboard, but have not been successful. Any guidance would be appreciated. I've essentially been using a likely erroneous method to do this, which essentially just sends the same HID report as the button press I captured with Wireshark:

`		case RECORD:
        if (record->event.pressed) {
            // Send the HID report for the button press
            uint8_t data_down[32] = {0x1b, 0x00, 0x60, 0x72, 0xe1, 0x28, 0x0a, 0x99, 0xff, 0xff, 0x00, 0x00, 0x00, 0x00, 0x09, 0x00, 0x01, 0x01, 0x00, 0x0f, 0x00, 0x81, 0x01, 0x03, 0x00, 0x00, 0x00, 0x00, 0x04, 0x00};
            raw_hid_send(data_down, sizeof(data_down));
        } else {
            // Send the HID report for the button release
            uint8_t data_up[32] = {0x1b, 0x00, 0x10, 0x75, 0x56, 0x2b, 0x0a, 0x99, 0xff, 0xff, 0x00, 0x00, 0x00, 0x00, 0x09, 0x00, 0x01, 0x01, 0x00, 0x0f, 0x00, 0x81, 0x01, 0x03, 0x00, 0x00, 0x00, 0x00, 0x00, 0x00};
            raw_hid_send(data_up, sizeof(data_up));
        }
        return false;  // Skip all further processing of this key`

[2024-0420.zip](https://github.com/jfedor2/hid-remapper/files/15049057/2024-0420.zip)
[Nuance PowerMic API.pdf](https://github.com/jfedor2/hid-remapper/files/15049085/Nuance.PowerMic.API.pdf)

jfedor2, 2024-04-20:
You realize that once you connect the microphone through HID Remapper, it will no longer function as a microphone, right?

whyaaronbailey, 2024-04-20:
Ufff. No I didn’t realize that — I thought pass through would work for everything else :-(

whyaaronbailey, 2024-04-23:
Is it not detected because it comes over as multiple HID devices ( mouse / mic )?

jfedor2, 2024-04-23:
That in itself shouldn't be a problem, HID Remapper should ignore the audio part of the device. It works with a PS5 controller  for example, which also has an audio interface.

I took a quick look at the HID report descriptor in the dump you attached and I don't think there's anything there that would stop it from working either.

Some devices still just don't work. Are you using a single Pico variant of HID Remapper? Dual Pico sometimes works better.

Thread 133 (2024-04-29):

How would i? Capslock is Escape, or Control if pressed with a key?

simonvc, 2024-04-29:
I want to do this in hardware. Is it possible?

https://www.autohotkey.com/boards/viewtopic.php?t=92738

jfedor2, 2024-04-29:
Are people really such fast typists? I guess you can always play around with the tap-hold threshold setting.

led, 2024-04-29:
I can only speak for myself, but it's something that I've tried to adjust, but still sometimes find myself coming up against the issue (vim and tmux user, so use caps-lock is used a lot for escape and control - eg this makes the difference from intending to switch tmux panes/windows smoothly (ctrl-a …) but instead ending up just bumping out of insert mode in vim). Really breaks the editing flow.

jfedor2, 2024-04-29:
This wouldn't help with the situation you're describing, but if the problem was that you're getting A instead of Ctrl-A (because you didn't hold CapsLock long enough for the "hold" mapping to trigger) then you could try disabling the "hold" flag and just let CapsLock work as Control all the time. Then if you wanted to press Escape, it would always be preceeded by a short press of Control, but that is usually harmless.

The behavior where the action depends on whether other keys were pressed or not could possibly be emulated with expressions, but that would be some long-ass expressions as they would have to check the state of all the individual keys.

I will keep all this in mind for the future.

simonvc, 2024-04-30:
You guys are awesome. have ordered some hardware.

simonvc, 2024-05-10:
My device arrived. this works perfectly for me:

 CAPS->ESCAPE (tap)
 CAPS->Left Control (no tap or hold)

Closed 2024-05-10.

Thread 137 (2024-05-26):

Support for 8BitDo Lite SE(There seems to be a bug)

CrowKing63, 2024-05-26:
Hello there.

First of all, I would like to thank you very much for working on such a handy project. I've been using an Arduino Leonardo and a USB host shield to remap the numeric keypad for a few years now, and it's relatively simple to remap the numeric keys to mouse clicks for better accessibility, or to set up macros for playing Diablo. I recently discovered that a joystick manufacturer called 8BitDo has released a product aimed at increasing accessibility for people with disabilities. I've tried it out and it's certainly much easier to use than other gamepads, but I have a severe disability, so I don't expect to be able to play games like Zelda using it as is.

In fact, I'm interested in something else. That is to remap the soft joystick of 8BitDo's Lite SE into a kind of 8-button switch(I think this is an economical way to press the most buttons with the least amount of movement. Or not...). To do this, I bought an additional developer board and started to learn about the joystick HID communication protocol, but was immediately frustrated: it's just too hard! I've been trying to figure out how to do it somehow, and I found your HID REMAPPER project. It speaks an unfamiliar language, but seems to be very fully accessible, and for that I am truly grateful.

Sorry, that was a long editorial.

I'm writing this because I'm stuck, and I'm also curious.

1. does HID REMAPPER support 8BitDo Lite SE properly?

I flashed the "remapper_waveshare_rp2040_pizero.uf2" firmware with the 'r2024-05-23' version on my Waveshare RP2040-PiZero Development Board. After some testing, my mouse (https://www.pulsar.gg/collections/mice/products/xlite-v3-medium-gaming-mouse?variant=44387994173694) was recognized by the web configuration tool just fine, but the wired USB numpad for my Macally laptop (https://www.amazon.com/-/ko/gp/product/B079HF1HLM/ref=ppx_yo_dt_b_asin_title_o00_s00?ie=UTF8&psc=1) didn't even work (probably a power supply issue, judging by the blinking number lock LED?). 8BitDo Lite SE is recognized well. However, the first time I pressed a button(or pushed a joystick) on the 8BitDo Lite SE, the monitor tab of the web configuration tool detected a signal, and the mouse cursor was pushed to the bottom right corner. When I move the mouse cursor, it bounces back up, but until I uninstall the HID REMAPPER, the mouse cursor moves to the bottom right indefinitely. Just in case, I uploaded the previous version (r2024-04-19, remapper_waveshare_rp2040_pizero.uf2), but it doesn't even recognize 8BitDo Lite SE. This is the most recent version, and I have the same symptoms (infinite mouse cursor movement) on Windows as well as Mac. What else can I check? I need advice. If necessary, I'll get a feather board and test different firmware (but the board is out of stock and I doubt I'll ever get it back in stock).

2. Lack of Expressions slots to turn a joystick into an 8-button switch

Reverse Polish Notation is a strange language to me. Plus I'm a beginner in coding, I think I need eight Expressions slots to turn one joystick into an 8-button switch. But then what about the other joystick? Need More Other Expressions? My simple idea seems to be lacking in eight Expressions slots. Of course, it's a hasty story because I still can't use the 8BitDo Lite SE properly. My first question is whether there are any plans to expand the Expressions slot, and whether there is a smarter way to remap the joystick with an 8-button switch.

As I wrote it, the writing became too long. I'm sorry.

CrowKing63, 2024-05-26:
Just in case, I tried another keyboard at home (I don't know the manufacturer because it's a cheap bundle), but it doesn't turn on at all. Am I doing something wrong? Is the board I bought defective? I don't know...

jfedor2, 2024-05-26:
The runaway mouse cursor actually means it's working, believe it or not. To stop it from happening, disable the "Unmapped inputs passthrough" option in the "Settings" tab.

To map directions on an analog stick to keys, use a configuration like this:

Expression 1:
```
0x00010030 input_state -128 add dup mul /* stick x^2 */
0x00010031 input_state -128 add dup mul /* stick y^2 */
add /* x^2 + y^2 */
sqrt
1 store /* sqrt(x^2+y^2) */
0x00010030 input_state -128 add
0x00010031 input_state -128 add
atan2
2 store /* stick angle */

2 recall 45 gt /* angle > 45 */
135 2 recall gt /* angle < 135 */
mul
1 recall 64 gt /* deadzone */
mul
3 store

2 recall -135 gt /* angle > -135 */
-45 2 recall gt /* angle < -45 */
mul
1 recall 64 gt /* deadzone */
mul
4 store

2 recall 135 gt /* angle > 135 */
-135 2 recall gt /* angle < -135 */
bitwise_or
1 recall 64 gt /* deadzone */
mul
5 store

2 recall -45 gt /* angle > -45 */
45 2 recall gt /* angle < 45 */
mul
1 recall 64 gt /* deadzone */
mul
6 store
```

Then create mappings with Register 3, 4, 5, 6 as their inputs and whatever keys you want pressed as the outputs.

This gives you four buttons, one per cardinal direction. A similar thing could be done for 8 directions by adding four more similar entries and adjusting the angles.

As you can see with registers you're not limited by the number of expression slots as everything can go into the same slot pretty much.

CrowKing63, 2024-05-27:
It's a really simple and beautiful solution. Thank you for letting me know! I just turned off and tested all of the "Unmapped inputs passthrough" options, and made sure my mouse cursor was properly monitored without running away. Yay !

Looking at the Expressions 1 you wrote down, the method I envisioned was really an infantile idea at the level of 'if ~ else' (laughs). Thank you once again. I will take the time to open the code you wrote carefully and make good use of the registers.

Thank you.

CrowKing63, 2024-05-28:
I'm sorry, but I have one more question.

Every time a device is connected for the first time, when the computer is turned on with the device connected, or when it is initialized by changing the settings, it starts with a certain input held.

I've tested it in many ways, and for now it looks like the output you set for Register 4 as input starts with hold.

(Although I changed the register number) If I set a scroll-up on Register 4, the scroll-up starts with a hold every time a device starts up, and when I assign a right mouse button to Register 4, the device will also start as if I were holding that button.

Register 4 is in the west direction, I tested it with the right stick just in case my left stick was defective, but it showed the same symptoms perfectly.

This symptom only occurs at the beginning, and disappears with other manipulations. I have also tried to explicitly initialize the register but it doesn't seem like the cause of the problem. I don't know what the hell is wrong.

I'm worried if you're asking too a sa scrimbary question. Sorry.

jfedor2, 2024-05-28:
Yeah, this is because the analog stick on a gamepad sends 0-255 values and the neutral position is 128, not 0.

After you connect it, or turn everything on, if you don't touch the gamepad, it doesn't send anything until you press some buttons or move the sticks. And HID Remapper's internal state for those inputs defaults to 0, which translates to northwest on the analog stick.

An inelegant solution to this is to change this part of the expression:
```
2 recall -135 gt /* angle > -135 */
-45 2 recall gt /* angle < -45 */
mul
1 recall 64 gt /* deadzone */
mul
4 store
```
to read:
```
2 recall -134 gt /* angle > -134 */
-45 2 recall gt /* angle < -45 */
mul
1 recall 64 gt /* deadzone */
mul
4 store
```
Making a 1-degree wide gap in the northwest corner that corresponds to the sticks initial position.

A more elegant solution would involve having a flag that basically means "have we seen movement on the stick yet".

Let's say register 32 will be that flag.

Then our expression would look like this:
```
/* update register 32 to 1 if there's a change in left stick state */
32 recall
0x00010030 input_state
0x00010030 prev_input_state
eq not bitwise_or
0x00010031 input_state
0x00010031 prev_input_state
eq not bitwise_or
32 store

0x00010030 input_state -128 add dup mul /* stick x^2 */
0x00010031 input_state -128 add dup mul /* stick y^2 */
add /* x^2 + y^2 */
sqrt
1 store /* sqrt(x^2+y^2) */
0x00010030 input_state -128 add
0x00010031 input_state -128 add
atan2
2 store /* stick angle */

2 recall 45 gt /* angle > 45 */
135 2 recall gt /* angle < 135 */
mul
1 recall 64 gt /* deadzone */
mul
32 recall mul
3 store

2 recall -135 gt /* angle > -135 */
-45 2 recall gt /* angle < -45 */
mul
1 recall 64 gt /* deadzone */
mul
32 recall mul
4 store

2 recall 135 gt /* angle > 135 */
-135 2 recall gt /* angle < -135 */
bitwise_or
1 recall 64 gt /* deadzone */
mul
32 recall mul
5 store

2 recall -45 gt /* angle > -45 */
45 2 recall gt /* angle < 45 */
mul
1 recall 64 gt /* deadzone */
mul
32 recall mul
6 store
```
The `32 recall mul` part zeroes the value that we put in registers 3, 4, 5, 6 if there hasn't been any change in left stick state yet.

Though this is not perfect either, at least while you work on the configuration - when you save the configuration to the device, the input states are reset, but the register states aren't. So you get the same problem. But during normal use it should be fine. Something to think about for me perhaps.

CrowKing63, 2024-05-29:
Aha! I understood what was going on. Thank you so much for the easy and kind explanation. And thank you again for the solutions you wrote down. As you say, the solutions are elegant. It's like watching a puzzle game broadcast!

Wouldn't it be helpful to set the dead zone to reverse? Like `127 1 recall gt`? It's fun because it feels like playing a game!

Closed 2024-08-08.

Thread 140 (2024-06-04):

inconvenient delay when drag scrolling.

itsnoteasy, 2024-06-04:
i'm using the hid-remapper with the current release and a slimblade pro wired. My settings are to invert the trackball rotation 180 degrees, remap all the buttons to my preferred location, and to slow the drag scroll speed by 0.02. polling rate overclocking is disabled and i use it in the wired mode for 1000hz i think.

my problem is that there is a time lag of 1 to 2 seconds between when i right click to enter layer 1 and when it enters the layer. therefore, i have to wait over the appropriate area, because if i do not, then the mouse moves away when i go to make the drag scroll movement motion, and then i have to repeat the action.

It seems to me to be a bug of some kind since the latency is so low otherwise.

itsnoteasy, 2024-06-04:
[inconvenient_delay.json](https://github.com/user-attachments/files/15571127/inconvenient_delay.json)
here you go.

itsnoteasy, 2024-06-07:
ah that makes sense. forgive me if i have asked about this issue before, which i suspect it wasn't my intention to be repetitive. this should be added to a frequently asked question page.
I think that in theory it should be possible to create a faster layer dedicated to scroll wheel events, because they would not be triggered accidentally due to requiring a specific ball motion in conjunction with the button press.
This would be similar to the concept of speculative execution in a modern 64 bit cpu.
hid-remapper would enter a layer in parallel with the button tap, perhaps on an extra unused core.
I will think about it when i am less tired.

itsnoteasy, 2024-06-07:
I managed to fix the issue. I created an extra duplicate layer for drag scrolling, with the only change being that it has the tap flag set, whereas the original drag scroll layer was set to hold. This avoids double scroll events and the lag.
[hid-remapper-nodelay.json](https://github.com/user-attachments/files/15726372/hid-remapper-nodelay.json)

jfedor2, 2024-06-07:
Have your tried a simple "left button -> Layer X" mapping, no tap, no hold?

itsnoteasy, 2024-06-07:
seems to work fine with your suggestion, though i had to add a v scroll to v scroll mapping on layer 1 to make  it less confusing when the wheel didn't work.
I think in older versions, doing this would tend to break the button function. you had to use separate tap and hold to be usable.

Closed 2024-06-08.

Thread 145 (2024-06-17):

Mapping problems with Bluetooth version

ozunion, 2024-06-17:
There may be something I've missed...

The environment used is

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

The mouse and keyboard are paired with the HID-Remapper and are working perfectly.

When I set "tap-hold: middle button is middle-click when clicked, but switches layer when held" in the example tab, it worked perfectly.
However, when I set "map caps lock to control" while keeping this setting, the caps-lock key remains the caps-lock key.

So I tried adding the "tap-hold~" setting after setting "map caps lock to control" first.
However, "tap-hold~" did not work properly.
To be more specific, CursorY to Vscroll is not reflected, and the cursor only moves up and down.

I thought that the problem might be with the "Unmapped inputs passthrough on layer" setting, so I unchecked the box, and the cursor stopped moving up and down, but I still couldn't scroll vertically.

So, when used individually, both work well, but when used together, one of them breaks.

Is there something I'm doing wrong with the settings?
Or is this just the way it is?

jfedor2, 2024-06-17:
Can you export your configuration to JSON and post it here and also describe what you expected it to do?

ozunion, 2024-06-17:
This is a JSON file.
If the middle mouse button is held down while moving the mouse, the page will scroll in the direction of the movement (X to H scroll, Y to V scroll).
[hid-remapper-config (1).json](https://github.com/user-attachments/files/15874567/hid-remapper-config.1.json)

I would also like CapslockToControl to work.

jfedor2, 2024-06-17:
The configuration seems correct. Are you sure your keyboard is connected through HID Remapper and not directly to your computer? It may not be obvious with Bluetooth. You can verify that by going to the Monitor tab and pressing some keys on your keyboard. Also the blue LED on HID Remapper blinks as many times as there are devices connected so it should blink twice every second or so.

ozunion, 2024-06-18:
Connections are checked first.The monitor tab shows a report that the keyboard and mouse are each securely connected and recognized to work...On Jun 18, 2024, at 6:58, Jacek Fedoryński ***@***.***> wrote:
The configuration seems correct. Are you sure your keyboard is connected through HID Remapper and not directly to your computer? It may not be obvious with Bluetooth. You can verify that by going to the Monitor tab and pressing some keys on your keyboard. Also the blue LED on HID Remapper blinks as many times as there are devices connected so it should blink twice every second or so.

—Reply to this email directly, view it on GitHub, or unsubscribe.You are receiving this because you are subscribed to this thread.Message ID: ***@***.***>

Closed 2025-09-14.

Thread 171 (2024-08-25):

incompatible keyboard?

ccccff, 2024-08-25:
Hi,

First thanks a lot for your great project! I was in need for this for such a long time.

Now I have a problem with a particular keyboard (this one : https://www.coolermaster.com/en-global/products/quick-fire-pro/).

I have made both the single RP pico and dual RP pico and both are working perfectly with the multiple keyboards I've tested.

But with the CoolerMaster, both are not working but differently.

On the single pico version, this is working for most of the keys but many keys on the keyboard appear not to be working at all (space, backspace, tab, etc.). I see nothing on the "Monitor" tab of the HID Remapper Configuration for those keys.

On the dual pico version, no keys at all are registering at all, even though the keyboard is powered.

Any ideas?

thanks a lot

jfedor2, 2024-08-25:
Can you dump the report descriptor from this keyboard as shown below and post it here?

https://www.youtube.com/watch?v=Qt-UlTNUnu8

Even better if you can also press the keys that are not working while the capture is running.

ccccff, 2024-08-25:
thanks for the quick answer!

capture file sent via email.

jfedor2, 2024-08-25:
While the report descriptors on this keyboard are a bit unusual, I don't think they're incorrect, I think it's HID Remapper that's not currently handling entries like these correctly (specifically the fact that there's both Usage and Usage Minimum/Maximum):
```
...
0x19, 0x04,        //   Usage Minimum (0x04)
0x29, 0x28,        //   Usage Maximum (0x28)
0x09, 0x4F,        //   Usage (0x4F)
0x09, 0x50,        //   Usage (0x50)
0x09, 0x2B,        //   Usage (0x2B)
0x09, 0x2C,        //   Usage (0x2C)
0x09, 0x51,        //   Usage (0x51)
0x09, 0x52,        //   Usage (0x52)
0x95, 0x2B,        //   Report Count (43)
0x81, 0x02,        //   Input (Data,Var,Abs,No Wrap,Linear,Preferred State,No Null Position)
...
```

I will think on how to fix this, in the meantime you can try this config:

[cm-storm-quickfire-pro.json](https://github.com/user-attachments/files/16741809/cm-storm-quickfire-pro.json)

It has "custom usages" for these problematic keys (in the Settings tab).

Let me know if it works, I might have messed up some bit positions and didn't test it in any way.

As far as I can tell these are the affected keys:

arrow keys
tab
space
escape
backspace
minus/underscore
equals/plus

jfedor2, 2024-08-25:
As for why it doesn't work on the dual Pico version at all, I'm not sure, typically it's the other way round.

Are you plugging the keyboard into the HID Remapper through a hub by any chance?

ccccff, 2024-08-26:
I think your list of affected key is bang on.

Unfortunately, the json config appears to have no effect on any of them.

As for the dual pico version, I've tried direct connexions in many USB ports with many different cables without any success. There is a quick flash of the keyboard l LED when connecting then nothing is working except the local keyboard FN key (like LED mode change and brightness). Then Num lock LED would usually be on but it never turns on.

thanks a lot!

jfedor2, 2024-08-26:
Hmm then I'm not sure what's going on. Did you unplug an replug the HID Remapper after saving the config? The custom usages take effect after a restart.

ccccff, 2024-08-26:
that is exactly it! I just had to restart the rapberry pi! All working now, thanks a lot!

Do not hesitate if I can help testing something.

Closed 2024-08-26.

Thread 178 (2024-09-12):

NiceNano clones connectivity issue

JostBrand, 2024-09-12:
Hi,

First, I want to thank you for this awesome project. I am running a couple of split keyboards with NiceNano clones and wanted a solution to enter LUKS passwords wirelessly. The process for setting up your tool on an additional nRF52840 and pairing my keyboard took less than 3 minutes.

**Problem:**

I have noticed a clear connectivity issue when typing. Some keystrokes are just not recorded. When connecting to my regular Bluetooth dongle, I have no issues.

**Questions:**

1. Are these chips missing anything required to have a stable connection with this tool?
2. Or is it more likely that the board definition of the `Adafruit Feather nRF52840 `is a little bit different?

Thanks for your help in advance.

jfedor2, 2024-09-12:
Sorry, what are you running HID Remapper on? Another NiceNano clone? If it's running at all then I don't think the board definition would be causing dropped inputs.

And what are you running on your keyboards? ZMK?

JostBrand, 2024-09-13:
Sorry for not providing more context. The [nice!nano](https://nicekeyboards.com/nice-nano/) is a well known Nordic nRF52840 chip used in DIY Ergonomic keyboards.  Here is a popular example [Sweep](https://github.com/davidphilipbarr/Sweep). Most of them have two of these chips (one for each side) one connecting to the other half, while the main half connects to the PC.

There are different firmware options to run these keyboards like QMK, KMK and ZMK. Where [ZMK ](https://zmk.dev/)is the most used option for wirless keyboards. They allow to fully customize the keyboard.

So I have one NiceNano on my keyboard running zmk and one with your software running connected via usb to my desktop pc as a dongle.

domiluci, 2024-09-23:
@JostBrand Which nice!nano clone are you using? I've tried with the [Pro Micro](https://keeb.io/products/supermini-nrf52840-pro-micro-bluetooth-le-ble-controller) "nice!nano" version, using the Adafruit Feather nRF52840 version of HID Remapper. And while it shows up as an HID Remapper device and accepts programming, and even connects to my Bluetooth devices and accepts their inputs, nothing gets output by the hardware via USB. Joypad.ai shows nothing when I test the mapping.

It sucks because I have a ton of these I got dirt cheap, and my XIAO nRF52840 Sense isn't something I want to use for this long term, nor buy another of considering one costs 4-8x as much as one Pro Micro nRF52840 that I have in oodles.

Oh, and the LEDs are kind of wonky on the Pro Micro as well. Red LED doesn't work, and Blue LED just flashes no matter what.

So I'm just curious how you got these working. Thanks!

jfedor2, 2024-09-24:
@domiluci Can you post your configuration (JSON file)?

domiluci, 2024-09-24:
@jfedor2 Sure thing, though it's not something I'm particularly proud of. The expressions are a bit confusing, so I basically just went with trial and error until it functioned how I wanted it to. And it does function perfectly fine when I run it on my XIAO nRF52840 Sense. I can use my Bluetooth trackpad as a Left Stick that resets back to center when I lift my finger up and off it, which is what I wanted. But when I flash the nRF52840 Pro Micro with the firmware, then connect the same BT trackpad and load this same config onto it, everything is mission go, but there's no output being registered from the Pro Micro despite the fact I can see the exact same input from the BT trackpad under the "Monitor" tab as I do with the XIAO.

Everything is essentially identical between the XIAO and Pro Micro, sans the LEDs, but there's no output from the Pro Micro.

I've got to run, but I'll pick this back up when I get home. Thanks!

JSON Config: [20240922-P1MouseBT_to_LeftStick.json](https://github.com/user-attachments/files/17115622/20240922-P1MouseBT_to_LeftStick.json)

jfedor2, 2024-09-24:
While I don't see how this would explain the behavior you're seeing, you generally don't want two expressions setting the same output.

Instead you can have one expression that sets it to the value coming from the trackpad coordinates when your finger is on it and 128 otherwise, like so:
```
0x00010030 input_state 0 add 0.099 mul
0x000d0042 input_state_binary
mul

128
0x000d0042 input_state_binary not
mul

add
```

And similarly for the Y axis. Here's the whole config: [trackpad-to-stick.json](https://github.com/user-attachments/files/17117375/trackpad-to-stick.json)

Like I said I don't think this would explain your issue, but hey, you can give it a try.

(I assume you're seeing the inputs from the trackpad in the Monitor tab on the "Pro Micro" board?)

jfedor2, 2024-09-24:
@JostBrand Sorry, I missed your edit with further info. That is interesting. Something like that could happen if both the key-down and key-up reports somehow got batched from HID Remapper's point of view and the processing engine didn't run in between them. (Then the next time it runs, the key is not pressed and therefore the keystroke is missed.)

I'll try to come up with something to verify this hypothesis.

jfedor2, 2024-09-24:
@JostBrand One thing you could check is do these missed keystrokes show up in the Monitor tab on the configuration website?

domiluci, 2024-09-24:
@jfedor2 I was 100% sure I had the expressions gorked up in some way LOL. Like I said, I found it a tad confusing, so I just trial-and-errored it until it did what I wanted. Thank you very much for fixing it though. That was very kind of you 😄.

And it actually seems to have fixed the problem because now Joypad.ai is registering output from the nice!nano/Pro Micro. Why my bad expressions worked on the XIAO and not the Pro Micro when they're functionally identical was beyond me. But then I realized (and I'm spitballing as I haven't looked through the code or repo extensively) that they may actually be somewhat different, code-wise, as the Pro Micro takes the Adafruit Feather nRF52840 firmware while the XIAO nRF52840 takes the XIAO nRF52840 firmware. Like I said, I'm not well versed on your code or repo, so I'm hoping I'm not making an idiot of myself here, but maybe there's a difference in the two firmwares that made the Adafruit Feather nRF52840 firmware on the Pro Micro not pass my messed up expressions through? Just a thought. Now if I could just get that RP2040 Pi Zero working... 😆

Anyways, sorry for hijacking the thread. But thank you for the help on this. It's very much appreciated!

jfedor2, 2024-09-25:
@JostBrand I made a test build of the firmware that addresses what I think might be the issue causing dropped inputs. You can try it here (the "artifact" link at the bottom):

https://github.com/jfedor2/hid-remapper/actions/runs/11039276703

JostBrand, 2024-09-26:
@domiluci I used the superMini ones, I think these are the most popular on Aliexpress.

@jfedor2 Thank you, your test build fixes the issue now the &mt are registered as they should. :heart_eyes:

Closed 2024-12-14.

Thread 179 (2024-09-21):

Using 2.4Ghz wireless devices?

CrowKing63, 2024-09-21:
As the title says, I want to know if it is possible to have a wireless connection via a 2.4Ghz adapter.
I've actually tried it, I've tested both a bluetooth dongle adapter and a 2.4Ghz wireless adapter, but I wasn't expecting anything from the bluetooth, and I was expecting something from the 2.4Ghz wireless, and they both failed.
The reason I'm posting this question is because I've confirmed that the 2.4Ghz wireless communication works with a device called the Titan Two, so I have a small hope that it's just not working due to device compatibility, and that the 2.4Ghz adapter itself works.
So I thought I'd ask just to be sure.

CrowKing63, 2024-09-21:
Aha! Good to know that it works. Thanks for letting me know.

The product I tried, VXE R1 SE PLUS, is a recently released cheap mouse from China. I plugged in the adapter, moved the mouse around and even clicked on it, but nothing came up in the Monitor tab.

CrowKing63, 2024-09-28:
hello. I once sought your advice to remap the joystick in 8BitDo Lite SE to an 8-way switch, and you wrote the code to make it accessible, which I am very grateful for.

Recently, 8BitDo released the second generation of the Lite SE with Microsoft. I bought it because I liked the ability to add external switches, and I tried to remap it once again, but the new gamepad is not recognized. Both the 2.4Ghz wireless connection and the USB cable wired connection are not recognized. I don't see anything in the monitor tab. Can you give me another idea of what I should try?

jfedor2, 2024-09-28:
That device just doesn't work currently. It's an Xbox One controller, not a class-compliant USB HID one. We do support some Xbox One controllers like the Xbox Adaptive Controller (and I think the regular first-party ones too), but some of them require custom initialization for some reason.

I have some USB traffic dumps for the new Xbox Lite SE, but I don't have the controller itself so I haven't made any attempts.

CrowKing63, 2024-09-29:
Thanks for letting me know, it's quite a relief to know why it's not working.

jfedor2, 2024-10-24:
So good news and bad news, I got the Xbox version of the 8BitDo Lite SE to work, but only on dual Pico based HID Remappers.

There's a test build of the firmware you can try here:

https://github.com/jfedor2/hid-remapper/actions/runs/11502343575

CrowKing63, 2024-10-25:
Thank you for always being so attentive!
I'll try it as soon as I get a pico board, thank you very much.

jfedor2, 2024-10-29:
Actually scratch that, in the latest release (r2024-10-29) the Xbox version of the 8BitDo Lite SE should work with both single and dual variants. I noticed it's sometimes finicky when using the wireless dongle, but should be fine with a USB cable.

CrowKing63, 2024-10-30:
Aha! I see, I'll try it as soon as possible then, thanks sir!

CrowKing63, 2024-10-31:
I uploaded the latest released remapper_waveshare_rp2040_pizero firmware and tested it. For some reason, I don't see anything on the monitor tab. I tried both wireless dongle and wired... I even changed the cable just in case, but no luck. When I plug the cable into the pad, the green light above the pad lights up, but then goes out, and when I press the button, it comes back on. I also tried my old gamepad under the same conditions and it was recognized correctly. I guess I'll have to get another board. I'm sorry I can't give you good news after all your hard work. I'll be in touch.

jfedor2, 2024-10-31:
One thing I noticed about the RP2040-PiZero is that it only works if I plug a device into it first and then connect the PiZero to the computer, not the other way round.

CrowKing63, 2024-10-31:
Oh, really? That's really important information. Thanks! I'll try again.

CrowKing63, 2024-10-31:
Umm... again, no.
But I've had the same problem with numeric and cheap keyboards before, so I'm thinking it's my board.

jfedor2, 2024-10-31:
I can't get it to work with the Waveshare RP2040-PiZero either. As mentioned elsewhere it has pull-up resistors on the USB data lines which seem to be messing with stuff.

jfedor2, 2024-10-31:
I can sometimes get it to work with the RP2040-PiZero using the wireless dongle.

jfedor2, 2024-11-01:
I don't know, do you have a soldering iron? If not, getting one will cost more than the Feather probably.

CrowKing63, 2024-11-01:
Hmmm, I have one, but I'll have to see if I can get my family to try it out since I have limited mobility. Pico is definitely a lot cheaper, and feathers take forever to ship.

Closed 2024-09-29.

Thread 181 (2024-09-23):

Waveshare RP2040 Pi Zero not accepting anything via USB-PIO port

domiluci, 2024-09-23:
Bought a [Waveshare RP2040 Pi Zero](https://www.amazon.com/dp/B0CJ6VM6H6?ref=ppx_yo2ov_dt_b_fed_asin_title) the other day to use with an old USB trackpad I have. The firmware upload went smooth, the board shows up fine as "HID Remapper ACHB", but there's no input from the USB trackpad plugged into the USB-PIO port. In fact, there's no power whatsoever going to the trackpad.

I tried a slew of different USB adapters with the trackpad, same result. I tried plugging the Pi Zero into different USB ports, same result. So then I think the keypad must be drawing too much current or something, despite barely drawing anything, so I hook up a plain, B flat [USB numpad](https://www.amazon.com/dp/B0BNPVMQVT?ref=ppx_yo2ov_dt_b_fed_asin_title) instead and, you guessed it, same result. No power to the device on USB-PIO. No input on HID Remapper.

I have stuff to build a RP2040 HID Remapper, but I don't have the physical means to assemble one easily anymore. I was hoping the Pi Zero would've been an easy plug-n-play solution so I could avoid soldering and assembly, plus the header makes GPIO additions and expansions easy. I'm hoping there's still a redeeming fix here to get it working, but I can't find one.

Any help you could give would be greatly appreciated! Thanks!

jfedor2, 2024-09-23:
Did you flash the correct firmware (remapper_waveshare_rp2040_pizero.uf2)?

Can you try with some other devices like your regular keyboard or mouse?

domiluci, 2024-09-24:
@jfedor2 Yessir, firmware is right. I even reflashed it just to be sure. Same issue.

But I don't have anything else I can try right now in the USB department. I'm disabled and can't get down on/up off the ground to get to the cables for my keyboard and gamepad, but both devices are RGB and draw like 10x more current, at least. I doubt they'd power on.

I just ordered a replacement Pi Zero from Amazon. Won't arrive until Wednesday. Hopefully it's just a faulty board. Will update Wednesday/Thursday, and try and find something else to test with in the meantime.

jfedor2, 2024-09-28:
One thing I noticed about the RP2040-PiZero just now is that the order of plugging things in seems to matter, where it doesn't in other cases.

If I plug a mouse or a keyboard into the RP2040-PiZero and then connect it to the computer, it works, but when I first connect the RP2040-PiZero to the computer and then plug a mouse or keyboard into it, it doesn't work. Not sure why.

sonik-br, 2024-09-30:
PiZero works perfectly fine if you connect the usb port to another set of gpio pins. The USB-PIO pins on the board (GPIO06/07) does not work correctly. I think it's related to the [resistors](https://github.com/adafruit/Adafruit_TinyUSB_Arduino/issues/442#issuecomment-2275670753)?

jfedor2, 2024-09-30:
The 22 ohm series resistors are fine, but I'm not sure why they put the other two there (the pull-ups).

Of course the whole point of using this board was to avoid soldering or messing with wires at all so if you're going to wire the USB port to some other pins then you might as well just use a Pico.

It should be possible to cut the traces going to 3.3V, but again, at this point just use the Feather.

I should probably stop recommending the RP2040-PiZero as an option.

sonik-br, 2024-09-30:
> Of course the whole point of using this board was to avoid soldering or messing with wires at all so if you're going to wire the USB port to some other pins then you might as well just use a Pico.

Exactly. I've got one to test as the Feather USB Host is not available here (also not on aliexpress).
Got to the conclusion that PiZero is a no go.

domiluci, 2024-10-03:
> ...at this point just use the Feather.
>
> I should probably stop recommending the RP2040-PiZero as an option.

Well, I sent the PiZero back and ordered two Adafruit RP2040 Feathers with USB Host built-in. I was stoked when they got here, but now I'm getting genuinely irritated. It's the _same problem as the PiZero_. Whatever you plug into the Feather's USB Host port **_will NOT power on!_** I've flashed the appropriate firmware multiple times on both boards, but the firmware is accessible and functional. I've tried working with the Feathers on two different PCs; both PCs see the Feathers, I can access and change HID Remapper settings using the web tool, but there's nothing that shows up under "Monitor" because the USB device just won't power on. I've even tried my XAC _(with DC power)_ just to see if it's some BS PC USB power issue, but no USB Host power there, either. And I even found some other USB HID devices/mice/keyboards that I've been testing with, too. They work when used normally, but not a single one of those USB HID devices will power on when plugged into the RP2040 Feather's USB Host port.

I'm disabled, but I'm very far from being an idiot, which is an annoying assumption most people make at first glance these days just because my issues have now become visibly apparent. The fact is that I've been working with electronics for over two decades. I earned degrees in comp sci and engineering sci by the time I was 19 years old. And I have legitimate, honest-to-God patents on several of my creations. So, in short, I think I'm at least marginally qualified enough to troubleshoot a ready-to-go, plug-n-play system like HID Remapper, especially if the RP2040 Feather has worked for you in the past. And I _have_ gone through the efforts of troubleshooting, and beyond, but it's still not working and I genuinely cannot figure out why.

@jfedor2: What was the last release of HID Remapper you know, for sure, was tested and working with the RP2040 Feather boards? How about the RP2040 PiZero boards?

jfedor2, 2024-10-03:
The latest release (r2024-06-27) works on both boards, with the caveats mentioned above for the RP2040-PiZero.

I tested the XAC with the Feather just now and it works for me.

sonik-br, 2024-10-03:
@domiluci I don't have any experience with the Feather USB Host.
But I do know that it needs a gpio pin state to send power to the usb host port.
https://github.com/jfedor2/hid-remapper/issues/181#issuecomment-2391390277

Flashed the "remapper_feather.uf2" file?

Please keep in mind that, like I said, I've never used a Feather USB Host before. I'm just trying to help :)

domiluci, 2024-10-03:
> Flashed the "remapper_feather.uf2" file?

Yes I did. On both boards, several times, as mentioned. The firmware works fine. I can read/write to it perfectly with the web tool. But the device plugged into the USB Host port, whatever device I try, fails to power on.

> But I do know that it needs a gpio pin state to send power to the usb host port.

Well, @jfedor2 just mentioned that the latest release works for him and his RP2040 Feather, which leads me to conclude that the relevant GPIO pin was properly set in the firmware before compilation. So we're back to square one. Unless I just got two bad boards and/or all five USB devices I'm trying happen to be the only generic HID devices on the planet that just don't work with HID Remapper (which I find unlikely in both cases).

domiluci, 2024-10-06:
Still playing with this and still can't get it to work no matter what's plugged into what. I'd really like to resolve this considering how financially invested I am in this now, and the fact Adafruit won't accept returns on opened items. So if anyone out there has a fix, I'd love to hear it.

sonik-br, 2024-10-06:
@domiluci can you code?
You could do simple tester to just test if the usb-pio is working. I can help with that.

domiluci, 2024-10-07:
> @domiluci can you code? You could do simple tester to just test if the usb-pio is working. I can help with that.

I can. But usually I just ChatGPT the hard stuff and fill in the blanks. However, I flashed the boards with a TinyUSB HID Remapper example and they still didn't work. I'm pretty sure it's some kind of enumeration issue because USB-PIO is, definitely, getting power.

**_BUT_** this morning I had (some) success! Finally! I purchased a [Darmoshark SK16 macro keypad](https://www.amazon.com/dp/B0CYBRPL87) on Amazon. It's a mini QMK keyboard with BLE/USB/2.4G functionality. A pure HID device. I remapped some of the buttons to give me a WASD/LRUD layout, plugged it into the RP2040 Feather and, whaddya know? The SK16 powered on and HID Remapper recognized it. Which begs the question, out of seven different USB HID devices, _what's special about the SK16, and what's preventing HID Remapper from working with the other six HID devices?_ Might be worth looking into.
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
sonik-br, 2024-10-07:
> The SK16 powered on and HID Remapper recognized it.

Interesting.

Btw I've seen various devices with different behaviors.
This happens on all RP2040 boards I've tested.

* Some devices only works if connected to native usb port.
* Some devices only works if connected to pio emulated port.
* Some devices works on both but only enumerates if connected to pico before the pico being powered up.

The native port when used as usb host works with almost everything but I do have one device that does not work.
And I've tested four devices that simply does not work at all when using PIO. So yeah, PIO is not perfect.

There's a two board version of hid-remapper that uses the native port as host.
You could try this setup as I believe you now have two RP2040 boards, right?

domiluci, 2024-10-12:
> Is your XAC on the latest firmware (at least 5.21.3242.0, released in June 2024)?
> Is HID Remapper plugged into the left USB port on the XAC?
> If you have anything remapped on the XAC itself then of course the inputs will no longer match.

@jfedor2 Yup. And everything's up to date, and all the XAC mappings are unchanged. But I should clarify that this only happens when the RP2040 Feather is plugged into my PC (when updating mappings), not the XAC. And yes, HID Remapper is set to XAC/Flex mode, and I power cycle the board after saving and before testing. But when I go to Joypad.io or GPV to check the mappings, before swapping the Feather from my PC to XAC, they show up incorrectly with the aforementioned mappings.

_However,_ when I then plug the same RP2040 Feather with the same HID Remapper mappings into the XAC, and then check my mappings again with Joypad/GPV, they show up correctly. So I'm not exactly sure what's up there. It works in the end, but it's an odd bug I thought I'd mention. It just makes things a bit confusing LOL 😕

> There's a two board version of hid-remapper that uses the native port as host.
> You could try this setup as I believe you now have two RP2040 boards, right?

@sonik-br Yeah, I actually have several RP2040 boards now. I got a bunch of these [RP2040 Zero](https://www.amazon.com/gp/product/B0DGH2W61Z) boards, among others. I was thinking of making a dual RP2040 HID Remapper contraption out of a couple of them. Maybe a PCB if it works. We'll see 😄!

jfedor2, 2024-10-12:
The button labels are not a part of the USB spec. On some gamepads button 1 is "X", on others it's "A" or "square" or whatever.

If you want to increase the chance of your PC getting the right button map, use the "Switch gamepad" or "Stadia controller" modes, as things like Chrome and Steam have the correct mappings for them hardcoded.

The "XAC/Flex compatible" mode is for plugging HID Remapper into the XAC (and the Hori Flex).

domiluci, 2024-10-15:
Yes, I'm thoroughly aware it's for plugging into the XAC/Flex, and that button labels aren't part of the USB spec. I was just trying to be of assistance and mention something I thought was odd and potentially buggy. But that's fine, and it really doesn't matter at this point. I got it working well enough to hold me over until I finish a more permanent, all-in-one ground-up build.

Thanks for the help.

Closed 2024-10-15.

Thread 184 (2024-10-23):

new firmware doesnt work

undecideduser8, 2024-10-23:
flashed the new firmware to the adafruit feather and it doesnt work
had to install the one before because it doesnt detect the mouse

jfedor2, 2024-10-23:
What mouse model are you using?

undecideduser8, 2024-10-23:
> What mouse model are you using?

logitech g502 hero

JostBrand, 2024-10-24:
For me the mouse wheel stopped working. The input is  registered in the monitor tab of the configuration page as:
`Usage 0x00010038 V scroll
Last value 1
Min value -1
Max value 1
`

jfedor2, 2024-10-24:
@undecideduser8 When your mouse wasn't working, did the inputs still show up in the Monitor tab?

hanga61, 2024-10-24:
For me it turns out that "only" usb hub isn´t working. single mouse or keyboard works.

jfedor2, 2024-10-24:
@hanga61 Has it worked for you on the previous release?

hanga61, 2024-10-24:
I´ve tried the june release and it´s also not working.
I have tried three different hubs, but all passive.
Also tried different USB Ports.

Found your project on the weekend and imemdiately ordered two adafruit feather! :) Thanks for your work!

sdixon99, 2024-10-25:
The latest firmware also caused my pico based hid-remapper to stop working.  In my case, the pico is wired into a two port hub directly so that correlates with the report from hanga61.   Going back to the last firmware release restores functionality.  In addition, I put together another pico wired to a single usb (from a cut off usb extension cable) and that one works fine with the latest firmware.  So it does appear that the problem is with the new firmware used with usb hubs.

undecideduser8, 2024-10-25:
> @undecideduser8 When your mouse wasn't working, did the inputs still show up in the Monitor tab?

didnt check that

undecideduser8, 2024-10-25:
> The latest firmware also caused my pico based hid-remapper to stop working. In my case, the pico is wired into a two port hub directly so that correlates with the report from hanga61. Going back to the last firmware release restores functionality. In addition, I put together another pico wired to a single usb (from a cut off usb extension cable) and that one works fine with the latest firmware. So it does appear that the problem is with the new firmware used with usb hubs.

mine is also plugged to a usb hub

jfedor2, 2024-10-25:
OK, I can replicate the hub issue.

Any other issues with the new release, or existing previously, please file separate issues.

jfedor2, 2024-10-25:
I have a test build that should fix this regression if anyone wants to try ("artifact" link at the bottom):

https://github.com/jfedor2/hid-remapper/actions/runs/11525026520

Please note it doesn't make _all_ hubs work, just the ones that worked before the latest release.

sdixon99, 2024-10-25:
The remapper.uf2 firmware from artifact.zip restores function to my single pico based device with usb hub.  Thanks!

hanga61, 2024-10-27:
Do you have any advice for a working USB hub? Iḿ new to the project and my existing hubs doesn´t work. (Not with the new version, nor an older)

jfedor2, 2024-10-27:
I've had good results with this UGREEN one, but keep in mind that with products like this, silent revisions are not uncommon so there's no guarantee that you will get the same internals when you buy something that looks like this.

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

hanga61, 2024-10-31:
I could borrow one from AUKEY that looks similar to the ugreen and yes, it works.
But from time to time mouse or keyboard stopped working. Sometimes completly Till replug, Sometimes for seconds.
Also then it sends the last State, e. G. Wehen i'm typing it could send lllllllllllllllllllllllllllllllllllllots of letters.

jrhaggerty, 2024-10-31:
@sdixon99 What two port hub do you have wired to the single pico? I actually tried this last week with cheap splitter board/cables and it didn't work.. but I just found this issue was present so may have to try again. Curious what works for you though.

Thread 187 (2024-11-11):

Not an issue, just want to know if this is possible with expressions...

ThePilgrums, 2024-11-11:
Hi, absolutely love the project! A great thing for assistive technology and anyone converting an hid device. I've been looking for a device that can do this.

So anyway, I have duchenne muscular dystrophy and I use a setup involving an XAC and software called xpadder to use it as a mouse. The problem is certain programs/Windows pop ups stop it from functioning, so I've been looking for an arduino/pi pico alternative or adapter.

I read through your expression guide, but my very limited coding knowledge and unfamiliarity with reverse Polish notation didn't get me very far.

Anyway, before I waste any more of your time, can you have an input alternate between two key presses/mouse movements? In my setup I have right bumper set to move the mouse up while held, then the next time you hold the right bumper it moves the mouse down, then it goes back and forth in a loop from there. The right trigger does the same with left and right mouse movement. I'm not sure this matters, but this is all on one "layer" as you call them in your software.

I uploaded a video just in case I didn't explain myself well enough:
[https://youtu.be/OoyuBFAy59Y](https://youtu.be/OoyuBFAy59Y)

Any help would be very much appreciated!

jfedor2, 2024-11-11:
Yeah, something like that should be possible.

You could make a mapping like this:

Expression 1 -> Cursor X

and set Expression 1 to:
```
/* register 1 is either 1 or -1 */
/* meaning the cursor will move right or left */

1 recall
/* register is initially 0 so make it 1 in that case */
dup not add
/* check if button was just pressed */
0x00090007 prev_input_state_binary not
0x00090007 input_state_binary
mul
/* if the button was just pressed, flip the direction */
-1
1
ifte
mul
/* store the value for next time */
1 store

/* apply the direction to the movement */
0x00090007 input_state_binary
1 recall
mul
```

And a similar thing for Cursor Y. Here's a JSON file with the complete config: [hid-remapper-flip-mouse.json](https://github.com/user-attachments/files/17707185/hid-remapper-flip-mouse.json)

You would of course have to update it with the specific buttons you want to use and possibly adjust sensitivity etc.

I know the expression syntax isn't the most user friendly thing. Let me know if you need any clarification or have some other ideas.

jfedor2, 2024-11-11:
Actually this should be possible even without using expressions at all, but I'm not sure if such a configuration is necessarily easier to understand.

It uses layers 1-4 and the web configuration interface currently only shows layers up to 3 (they go up to 7 internally).

But if anyone's curious here's the JSON file: [hid-remapper-flip-mouse2.json](https://github.com/user-attachments/files/17707577/hid-remapper-flip-mouse2.json)

And here's what it looks like with Layer 4 photoshopped into where it should be:
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

ThePilgrums, 2024-11-13:
Oh, thank you!! I'll try it as soon as I can!

Closed 2024-11-13.

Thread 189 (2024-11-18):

Issues when switching computers using a KVM

1-lost-cause, 2024-11-18:
Hello, I found this repo and gave it a shot. Everything has worked great, but today as I tried to change inputs in my KVM (TESmart HKS402-P23-USBK) and I have the device (singe rasperry pi pico) connected to one of the standard USB connectors (vs the ones where the KVM intercepts the HID inputs for special hotkeys that it uses), and everything works fine until I try to switch from one PC to another. The device becomes unresponsive until I remove the mouse's dongle (Kensington Expert Mouse Wireless Trackball) from the rasperry pi and put it back in.

I'm still pretty new to using custom boards with these custom boards, but it seems like there could be some sort of setting or something that could "reset" the connection from the USB dongle?

jfedor2, 2024-11-18:
We've had similar reports (#146) in the past, I didn't get around to investigating it properly yet. My guess was that the device plugged into HID Remapper goes into suspend while the switch is happening and we fail to wake it up afterwards.

jfedor2, 2024-11-18:
#83 might also possibly have the same root cause.

1-lost-cause, 2024-11-19:
Not 100% sure what the difference is, but I tried out the two rasperry pi configuration, and that seems to be working to keep the connection while it switches

jfedor2, 2024-12-08:
You can try this test build and see if it makes a difference:

https://github.com/jfedor2/hid-remapper/actions/runs/12225991612

jgermade, 2024-12-10:
It would be awesone to use hid remapper as kvm being able to use a hotkey for switch target device

jgermade, 2024-12-10:
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

wow! this is great! sad not maintained...

in my case hotkey is more convenient because I work with 4 displays

I was thinking about any kind of daisy-chain with hid-remappers for reach this behavior

braxlan, 2024-12-14:
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

Any plans to update screen-hopper and merge the improvements of hid-remapper there?

jfedor2, 2025-03-10:
> Any plans to update screen-hopper and merge the improvements of hid-remapper there?

No immediate plans but it would be nice.

jfedor2, 2025-03-10:
The latest release contains the fix from the test build above.

jgermade, 2025-04-16:
@jfedor2 how about add the hability to connect boards using I2C and be able to send all events throught one of these boards. The change of the target could be triggered with a button or a hotkey.

This way HID remapper would be working just like a ~kvm~ hid switcher

mccore, 2025-04-18:
Hi @jfedor2,

I am using a [wireless Elecom Huge](https://elecomusa.com/products/huge-trackball-mouse-wireless-usb) with a [level1tech KM switch](https://www.store.level1techs.com/products/p/4-port-km-switch-with-usb-32-gen-1-mouse-roaming-function). I have hid remapper set up using the [recommended Adafruit RP2040](https://www.adafruit.com/product/5723) running the latest u2f file and plugged in to the HID port on the KM switch. I tried both a macro and just mapping buttons separately but when pressing ctrl+ctrl+0 to switch to a second PC, the remapper freezes and stops taking inputs and then seems to reset itself and all is well again. The input does not change to the second computer though after the combination is run. If I press ctrl+ctrl via hid remapper and then 0 via a second HID compliant keyboard the input will switch successfully to the second PC (both PCs are running the latest updates on Windows 11).

Any idea what the issue could be? Is there more troubleshooting or logs I can do to provide you with more information?

As a note, something I keep coming across when researching the L1T KM switch is that it perfectly adheres to the HID standard and that most issues arise from the source device not adhering properly. Not sure if that helps at all.

Here is my config just in case:
`{
    "version": 17,
    "unmapped_passthrough_layers": [
        0,
        1,
        2,
        3,
        4,
        5,
        6,
        7
    ],
    "partial_scroll_timeout": 1000000,
    "tap_hold_threshold": 200000,
    "interval_override": 0,
    "mappings": [
        {
            "target_usage": "0x000700e0",
            "source_usage": "0x00090006",
            "scaling": 1000,
            "layers": [
                0
            ],
            "sticky": false,
            "tap": false,
            "hold": false,
            "source_port": 0,
            "target_port": 0
        },
        {
            "target_usage": "0x00070027",
            "source_usage": "0x00090007",
            "scaling": 1000,
            "layers": [
                0
            ],
            "sticky": false,
            "tap": false,
            "hold": false,
            "source_port": 0,
            "target_port": 0
        },
        {
            "target_usage": "0xfff20004",
            "source_usage": "0x00090008",
            "scaling": 1000,
            "layers": [
                0
            ],
            "sticky": false,
            "tap": false,
            "hold": false,
            "source_port": 0,
            "target_port": 0
        }
    ],
    "macros": [
        [
            [
                "0x000700e0",
                "0x000700e0",
                "0x0007001e"
            ]
        ],
        [
            [
                "0x000700e0",
                "0x000700e0",
                "0x0007001f"
            ]
        ],
        [
            [
                "0x000700e0",
                "0x000700e0",
                "0x00070027"
            ]
        ],
        [
            [
                "0x000700e0"
            ],
            [],
            [
                "0x000700e0"
            ],
            [],
            [
                "0x00070027"
            ]
        ],
        [],
        [],
        [],
        [],
        [],
        [],
        [],
        [],
        [],
        [],
        [],
        [],
        [],
        [],
        [],
        [],
        [],
        [],
        [],
        [],
        [],
        [],
        [],
        [],
        [],
        [],
        [],
        []
    ],
    "expressions": [
        "",
        "",
        "",
        "",
        "",
        "",
        "",
        ""
    ],
    "gpio_debounce_time_ms": 5,
    "our_descriptor_number": 0,
    "ignore_auth_dev_inputs": false,
    "macro_entry_duration": 100,
    "gpio_output_mode": 0,
    "quirks": [],
    "input_labels": 0
}`

jfedor2, 2025-04-18:
@mccore

So just to be clear, you connect a keyboard to an HID Remapper that's plugged into the switch and you manually press Control, Control, 0, with no macros or anything, and it triggers the issue?

mccore, 2025-04-18:
> [@mccore](https://github.com/mccore)
>
> So just to be clear, you connect a keyboard to an HID Remapper that's plugged into the switch and you manually press Control, Control, 0, with no macros or anything, and it triggers the issue?

That is correct @jfedor2.

jfedor2, 2025-04-18:
> That is correct [@jfedor2](https://github.com/jfedor2).

And when you connect HID Remapper and the keyboard both directly to the switch and do the switching command from the keyboard, what happens?

mccore, 2025-04-18:
> > That is correct [@jfedor2](https://github.com/jfedor2).
>
> And when you connect HID Remapper and the keyboard both directly to the switch and do the switching command from the keyboard, what happens?

The input switches correctly which means the command worked. The HID remapper also continues to work albeit with a small delay because the USB devices are switching over to the second PC. The HID remapper does not freeze like I have been describing in this scenario.

mccore, 2025-04-18:
@jfedor2 I also just made a dual pico version of this because I saw a comment in another issue that a dual pico setup _might_ help with a KVM setup because switching hosts should only affect one of the two picos. Unfortunately, I get the same behavior as with the RP2040. Additionally, when I use the switching key combination with the dual picos the LED on both goes solid green for a second before turning off. That second is when the remapper freezes and then goes back to working.

braxlan, 2025-04-19:
> [@jfedor2](https://github.com/jfedor2) how about add the hability to connect boards using I2C and be able to send all events throught one of these boards. The change of the target could be triggered with a button or a hotkey.
>
> This way HID remapper would be working just like a ~kvm~ hid switcher

You mean like his (jfedor2's) already existing [screen-hopper](https://github.com/jfedor2/screen-hopper) project? It uses serial instead of I2C, but does what you suggested, but only for 2 PCs.

mccore, 2025-04-24:
@jfedor2 any ideas on the issue with my KVM? Anything I can do to help provide you with logs or more troubleshooting?

jfedor2, 2025-04-26:
I don't have a theory here. If the act of switching somehow causes some weird behavior in HID Remapper, why does it matter if the switch was triggered from it or from another device? If the switch sees the switch command coming from HID Remapper, why doesn't it switch ports, regardless of what weird behavior it triggers in HID Remapper?

mccore, 2025-05-04:
Hi @jfedor2,

I went searching for some more data/answers and have a possible theory. I'll admit though, this is nowhere near my area of expertise so its possible that I'm completely wrong.

I downloaded [USB Device Tree Viewer](https://www.uwe-sieber.de/usbtreeview_e.html) to get the full device reports of both the HID remapper as well as the keyboard that works for switching between the KM host devices (aka between computers). That produced the attached full devices reports. I also took the two "HID Keyboard Device" portions from the respective "USB Input Device" sections and created [this diffchecker](https://www.diffchecker.com/m1v9RuiJ/) output. The thing that stands out most to me in that output is that the keyboard that works with the KM switch hotkeys has support for the D1 power state whereas the HID remapper does not.

In the D1 power state the USB bus **cannot** force devices to lose context whereas in the D2 state (which the remapper uses) the USB bus **can**. I am not entirely sure what that context is or if it even matters.

My theory is that when HID Remapper sends the hotkey combo to the KM switch that it enters D2 state which loses context and that causes an issue whereas the generic keyboard I am using enters D1 state which does not lose context and so no issue happens with the KM switch and the hotkey combo works successfully thus switching inputs.

Maybe all of this is completely incorrect and I look like an idiot. Hopefully the information I provided will at least help in diagnosing the issue even if I am entirely wrong.

Does any of this help?

[Source](https://uefi.org/htmlspecs/ACPI_Spec_6_4_html/Apx_A_Device_Class_Specifications/Apx_A_Device_Class_Specifications.html) for power state information.

[RP2040 HID Remapper 8U9H USB Composite Device.txt](https://github.com/user-attachments/files/20025903/RP2040.HID.Remapper.8U9H.USB.Composite.Device.txt)
[Darfon USB+PS2 Keyboard USB Composite Device.txt](https://github.com/user-attachments/files/20025904/Darfon.USB%2BPS2.Keyboard.USB.Composite.Device.txt)

jfedor2, 2025-05-04:
These are not USB concepts. The difference is the keyboard supports wakeup from suspend.

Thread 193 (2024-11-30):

HID remapper doesn't monitor any game controller except mouse  and keyboard

pftmclub, 2024-11-30:
Hello, i'm trying to remap my GP2040 controller, but none of them working . Tried it with keyboard and it's work successfully, does  anyone know this  problem?

Gamepad:

https://github.com/user-attachments/assets/c69d0429-65f2-4e99-80c4-f71d3a473d2d

Keyboard:

https://github.com/user-attachments/assets/e6717dcd-671b-4fcc-85de-6fc36c832ff7

jfedor2, 2024-11-30:
I just tested that it works in Switch mode for example.

HID Remapper doesn't care about the shape of the plug as long as the data lines are wired properly. Does your keyboard work with the same cable?

pftmclub, 2024-11-30:
> I just tested that it works in Switch mode for example.
>
> HID Remapper doesn't care about the shape of the plug as long as the data lines are wired properly. Does your keyboard work with the same cable?
My  keyboard have usb cable built-in ,

I tried to plug the USB-C directly into the usb hud and it's flashing. The other case is plug the Printer cable (USB-B) , nothing seem work .

USB-C:
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

USB-B :
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

jfedor2, 2024-11-30:
So it works when you connect it directly, but doesn't work when it goes through the Neutrik-or-whatever-style port on the enclosure? I don't see why it wouldn't.

pftmclub, 2024-12-01:
> So it works when you connect it directly, but doesn't work when it goes through the Neutrik-or-whatever-style port on the enclosure? I don't see why it wouldn't.

Yeah, and its strange that the controller still function over OLED screen but the remapper doesn't recognize it.
To put it simple , i plug the cable to usb-c to usb-b hud , then using the usb-b cable into usb hud of the pico board

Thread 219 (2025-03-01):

A custom board with LED indicator connected to GPIO

xuhdev, 2025-03-01:
The idea is to modify v4 (or even retrofit v1-v3) and connect some GPIOs to LED indicators. In this way, users can use LED indicators to, for example, confirm which layer they are in.

What do you think?

xuhdev, 2025-03-02:
@jfedor2 I created a modified version of v3 at https://github.com/xuhdev/hid-remapper/tree/led/custom-boards/v3/kicad . The only things I added are the LED and the resistor next to it (connected to GPIO 18). I also moved the track left to the LED a bit further to the left. Also modified the version number slightly to distinguish from the previous version.

I've sent it to production today and will wait and see if it works.

Let me know what you think!
It's my first time working with a PCB so please don't put too much trust in my judgment 😄

xuhdev, 2025-03-11:
I've received the board and it works well. However, I still have to add GPIO 18 to valid pins:

```diff
diff --git a/firmware/src/boards/feather_host.h b/firmware/src/boards/feather_host.h
index 1d1b871d221f..2a45222403fd 100644
--- a/firmware/src/boards/feather_host.h
+++ b/firmware/src/boards/feather_host.h
@@ -8,7 +8,7 @@

 #define FEATHER_HOST_BOARD

-#define GPIO_VALID_PINS_BASE 0b00111111000000001101111111111111
+#define GPIO_VALID_PINS_BASE 0b00111111000001001101111111111111

 // On some samples, the xosc can take longer to stabilize than is usual
 #ifndef PICO_XOSC_STARTUP_DELAY_MULTIPLIER
```

It seems like this won't work with the feather board, which uses the pin of GPIO 18 for USB power.

I can change the LED to connect to GPIO 19. This is a convenient port space-wise, but is also disabled in the firmware. Would you mind enabling GPIO 19 in the long term for feather_host? It doesn't seems like it would affect the feather board. If so, I can make changes to the PCB and order another batch to test out.

xuhdev, 2025-03-12:
I opened #223 to keep track of the progress. Could you reply to the previous message? I can proceed further if you are OK with the change :)

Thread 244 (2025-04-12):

Rev 8 - GPIO buttons not registering

Bonktacular, 2025-04-12:
Got my Rev 8 board back from JLPCB, flashed the firmware you compiled, slapped on my buttons and... Only GPIO buttons 1-6 register inputs.

Tried several of the boards, all the same results. Was there a GPIO extender or something missing from the firmware? I'm pretty new to hardware/firmware. 🤔

Also not sure if this should go over in the flatbox repo. Let me know if I need to move it!

jfedor2, 2025-04-12:
How did you mount the switches, can you show a picture?

Does it work if you short the pads with tweezers or a piece of wire?

Bonktacular, 2025-04-12:
I can show a picture when I get back later this evening, thank you for the response. the kailh browns are soldered in by their contact pins, and shorting the contacts does not produce anything on the monitor.

Bonktacular, 2025-04-13:
Evidently my soldering job was garbage, I heated the pins again and they're beginning to show up. Sorry to bother you!

Closed 2025-04-13.

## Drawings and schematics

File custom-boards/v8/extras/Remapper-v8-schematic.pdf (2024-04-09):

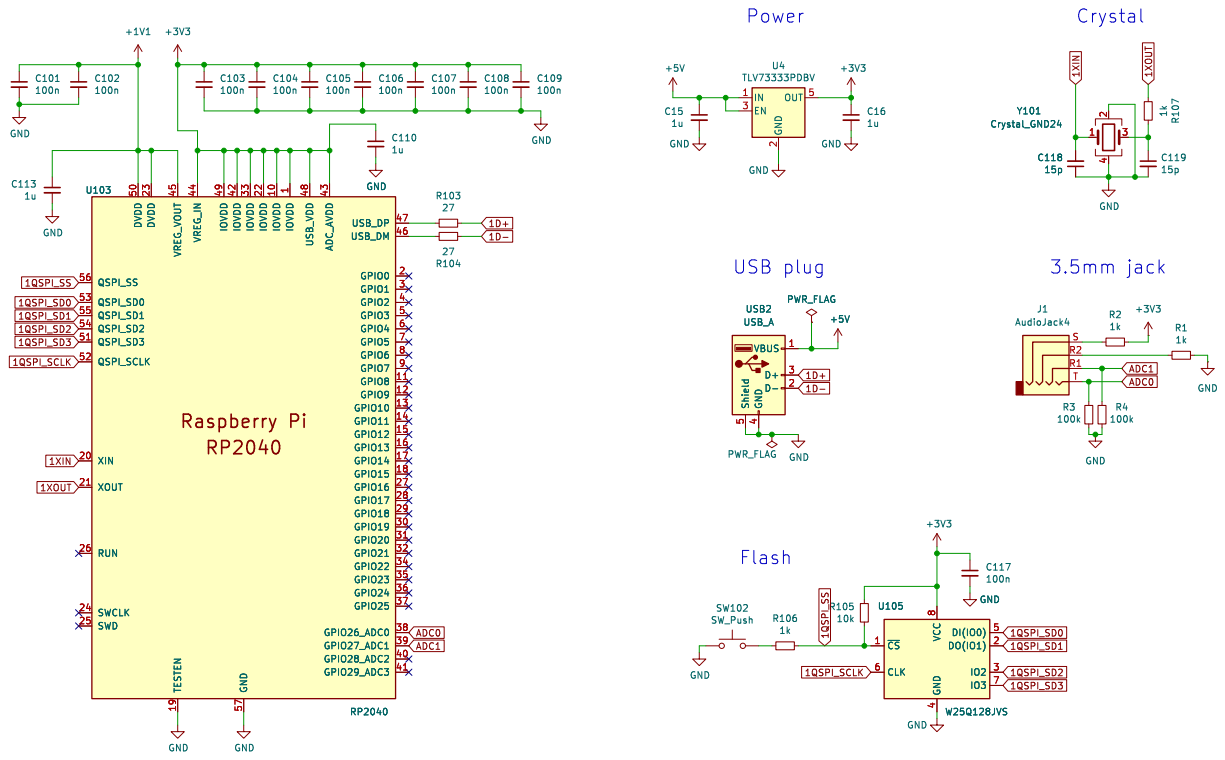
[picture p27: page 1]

1 IOVDD 10 GPIO8 11 GPIO9 12 GPIO10 13 GPIO11 14 GPIO12 15 GPIO13 16 GPIO14 17 GPIO15 18 TESTEN 19 GPIO0 2 XIN 20 XOUT 21 IOVDD 22 DVDD 23 SWCLK 24 SWD 25 RUN 26 GPIO16 27 GPIO17 28 GPIO18 29 GPIO1 3 GPIO19 30 GPIO20 31 GPIO21 32 IOVDD 33 GPIO22 34 GPIO23 35 GPIO24 36 GPIO25 37 GPIO26_ADC0 38 GPIO27_ADC1 39 GPIO2 4 GPIO28_ADC2 40 GPIO29_ADC3 41 IOVDD 42 ADC_AVDD 43 VREG_IN 44 VREG_VOUT 45 USB_DM 46 USB_DP 47 USB_VDD 48 IOVDD 49 GPIO3 5 DVDD 50 QSPI_SD3 51 QSPI_SCLK 52 QSPI_SD0 53 QSPI_SD2 54 QSPI_SD1 55 QSPI_SS 56 GND 57 GPIO4 6 GPIO5 7 GPIO6 8 GPIO7 9 GND

1 IOVDD 10 GPIO8 11 GPIO9 12 GPIO10 13 GPIO11 14 GPIO12 15 GPIO13 16 GPIO14 17 GPIO15 18 TESTEN 19 GPIO0 2 XIN 20 XOUT 21 IOVDD 22 DVDD 23 SWCLK 24 SWD 25 RUN 26 GPIO16 27 GPIO17 28 GPIO18 29 GPIO1 3 GPIO19 30 GPIO20 31 GPIO21 32 IOVDD 33 GPIO22 34 GPIO23 35 GPIO24 36 GPIO25 37 GPIO26_ADC0 38 GPIO27_ADC1 39 GPIO2 4 GPIO28_ADC2 40 GPIO29_ADC3 41 IOVDD 42 ADC_AVDD 43 VREG_IN 44 VREG_VOUT 45 USB_DM 46 USB_DP 47 USB_VDD 48 IOVDD 49 GPIO3 5 DVDD 50 QSPI_SD3 51 QSPI_SCLK 52 QSPI_SD0 53 QSPI_SD2 54 QSPI_SD1 55 QSPI_SS 56 GND 57 GPIO4 6 GPIO5 7 GPIO6 8 GPIO7 9 U103 RP2040 GND

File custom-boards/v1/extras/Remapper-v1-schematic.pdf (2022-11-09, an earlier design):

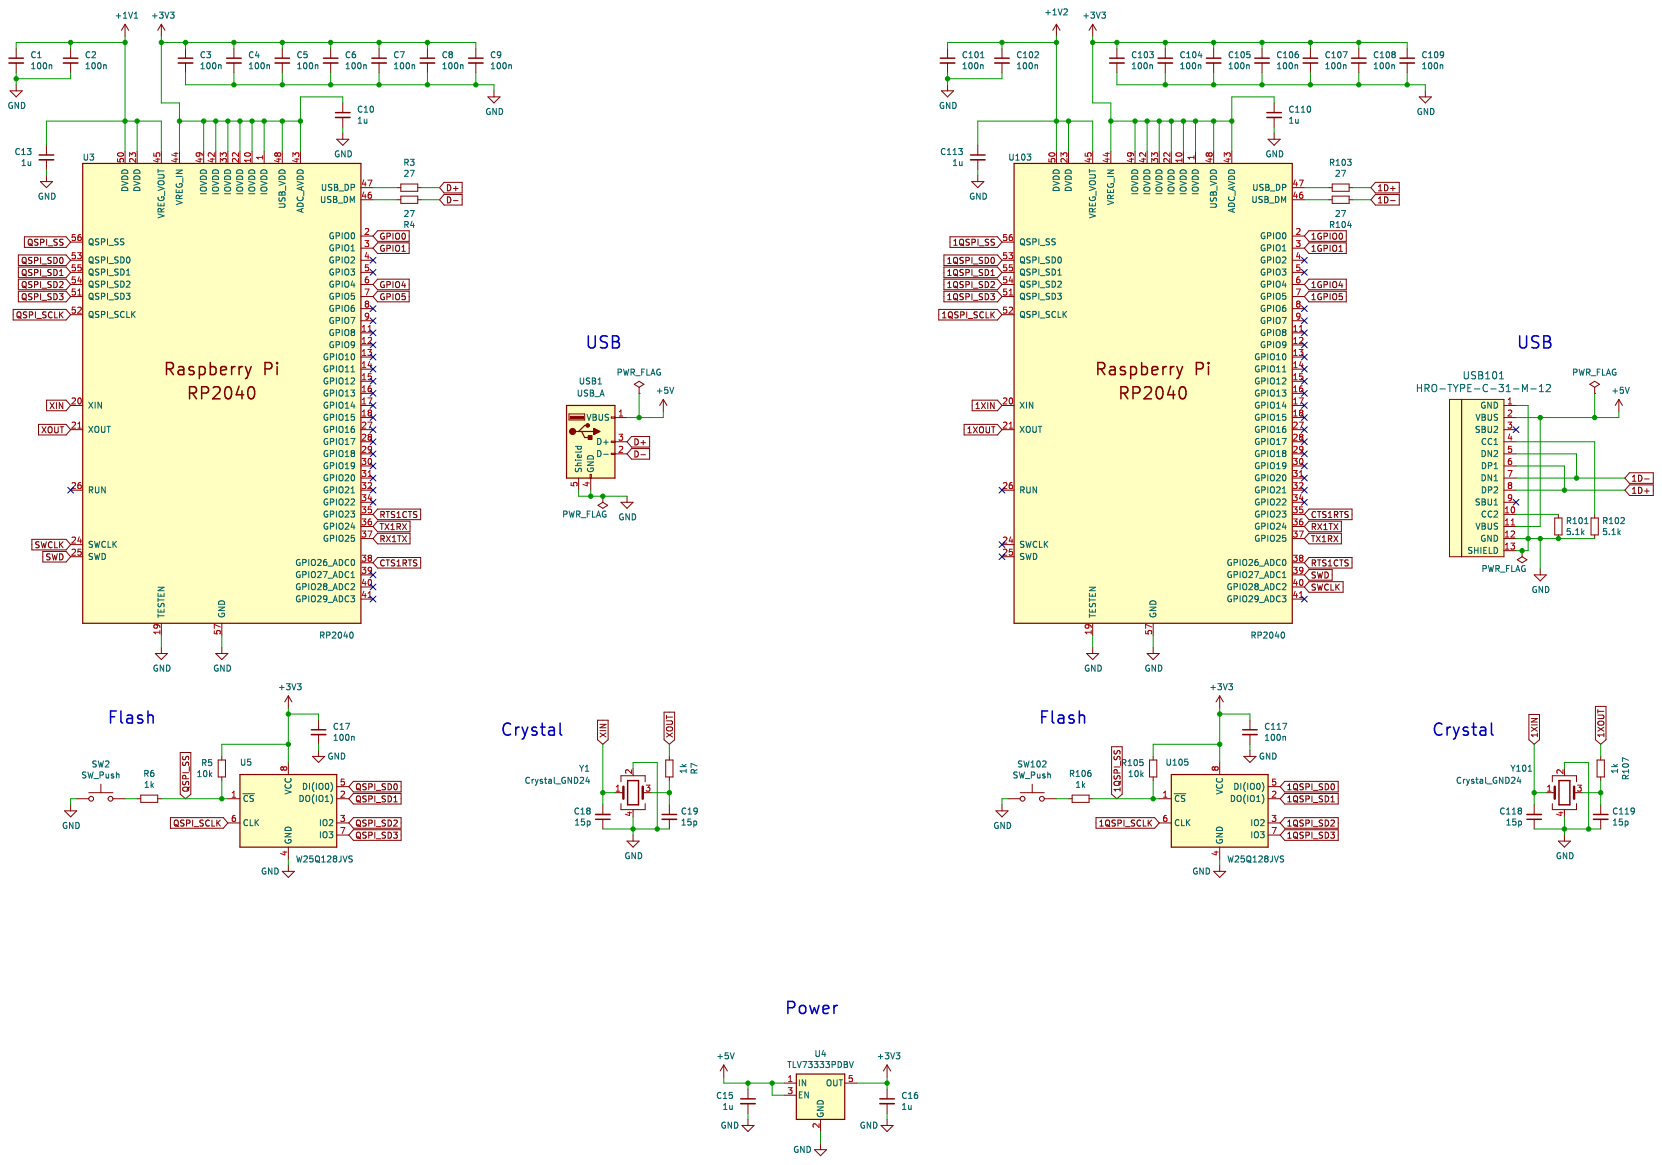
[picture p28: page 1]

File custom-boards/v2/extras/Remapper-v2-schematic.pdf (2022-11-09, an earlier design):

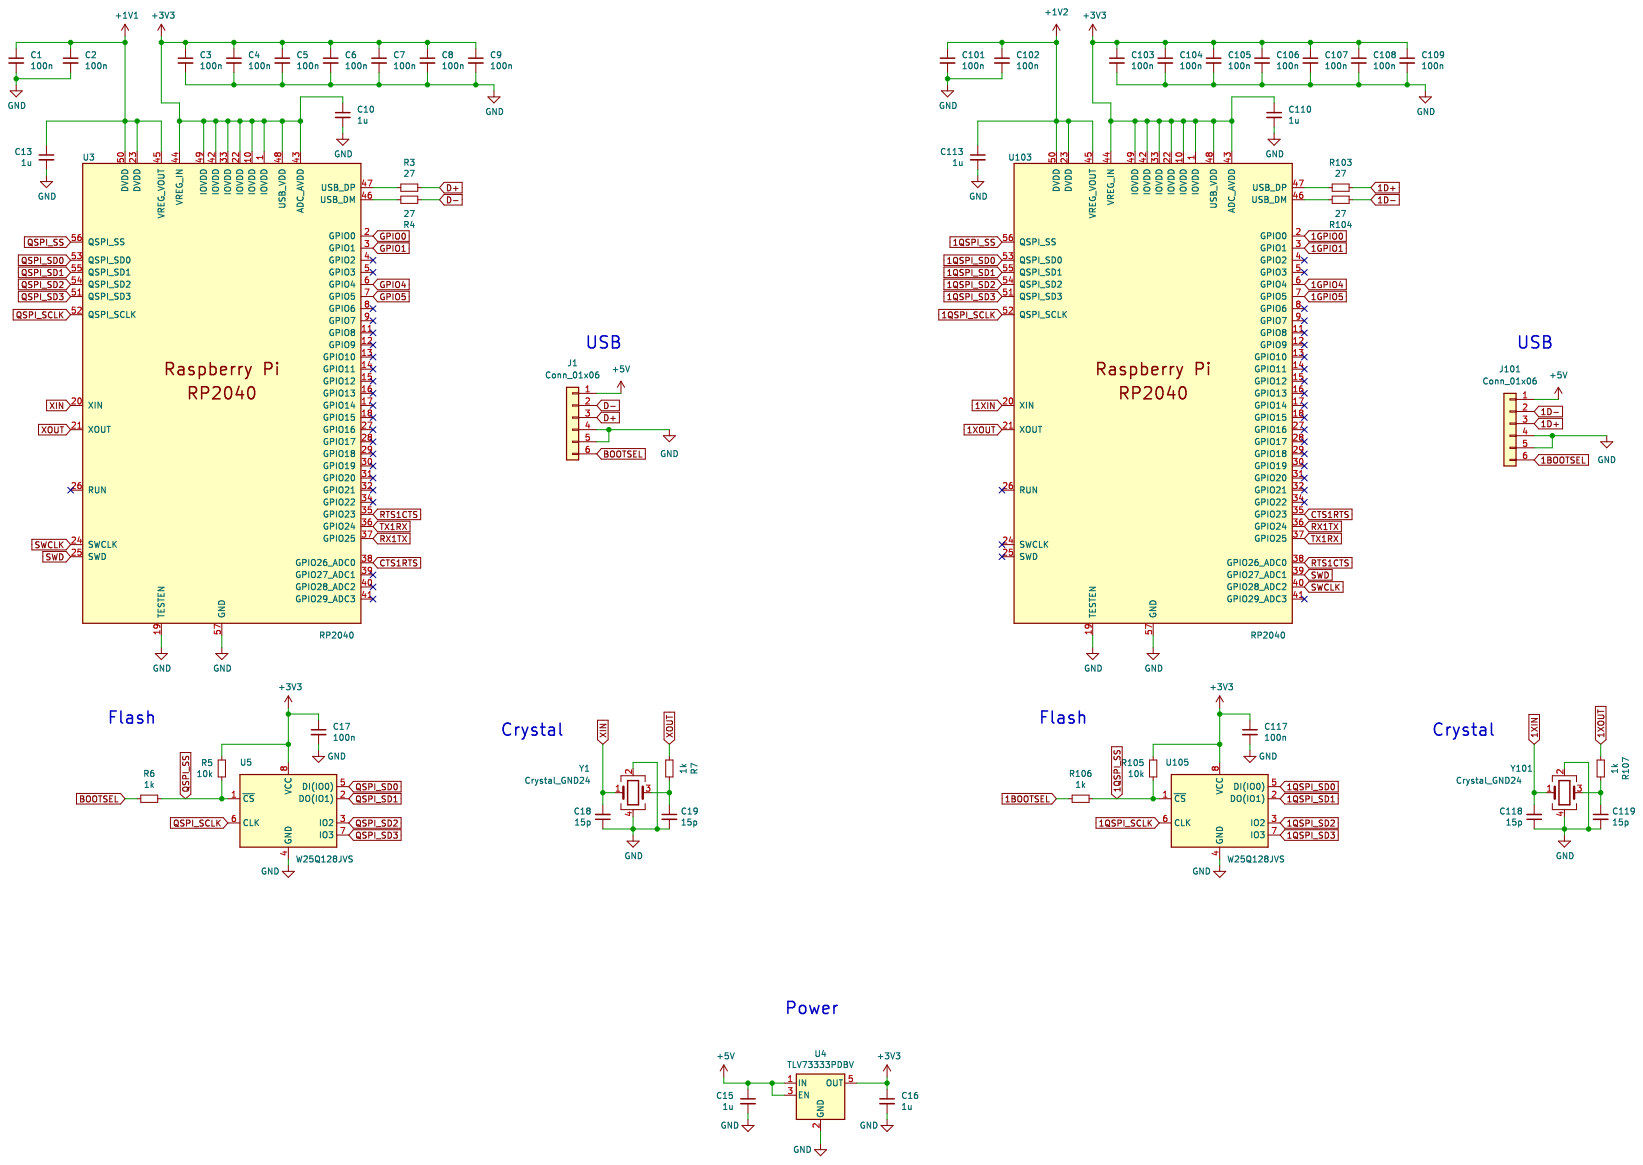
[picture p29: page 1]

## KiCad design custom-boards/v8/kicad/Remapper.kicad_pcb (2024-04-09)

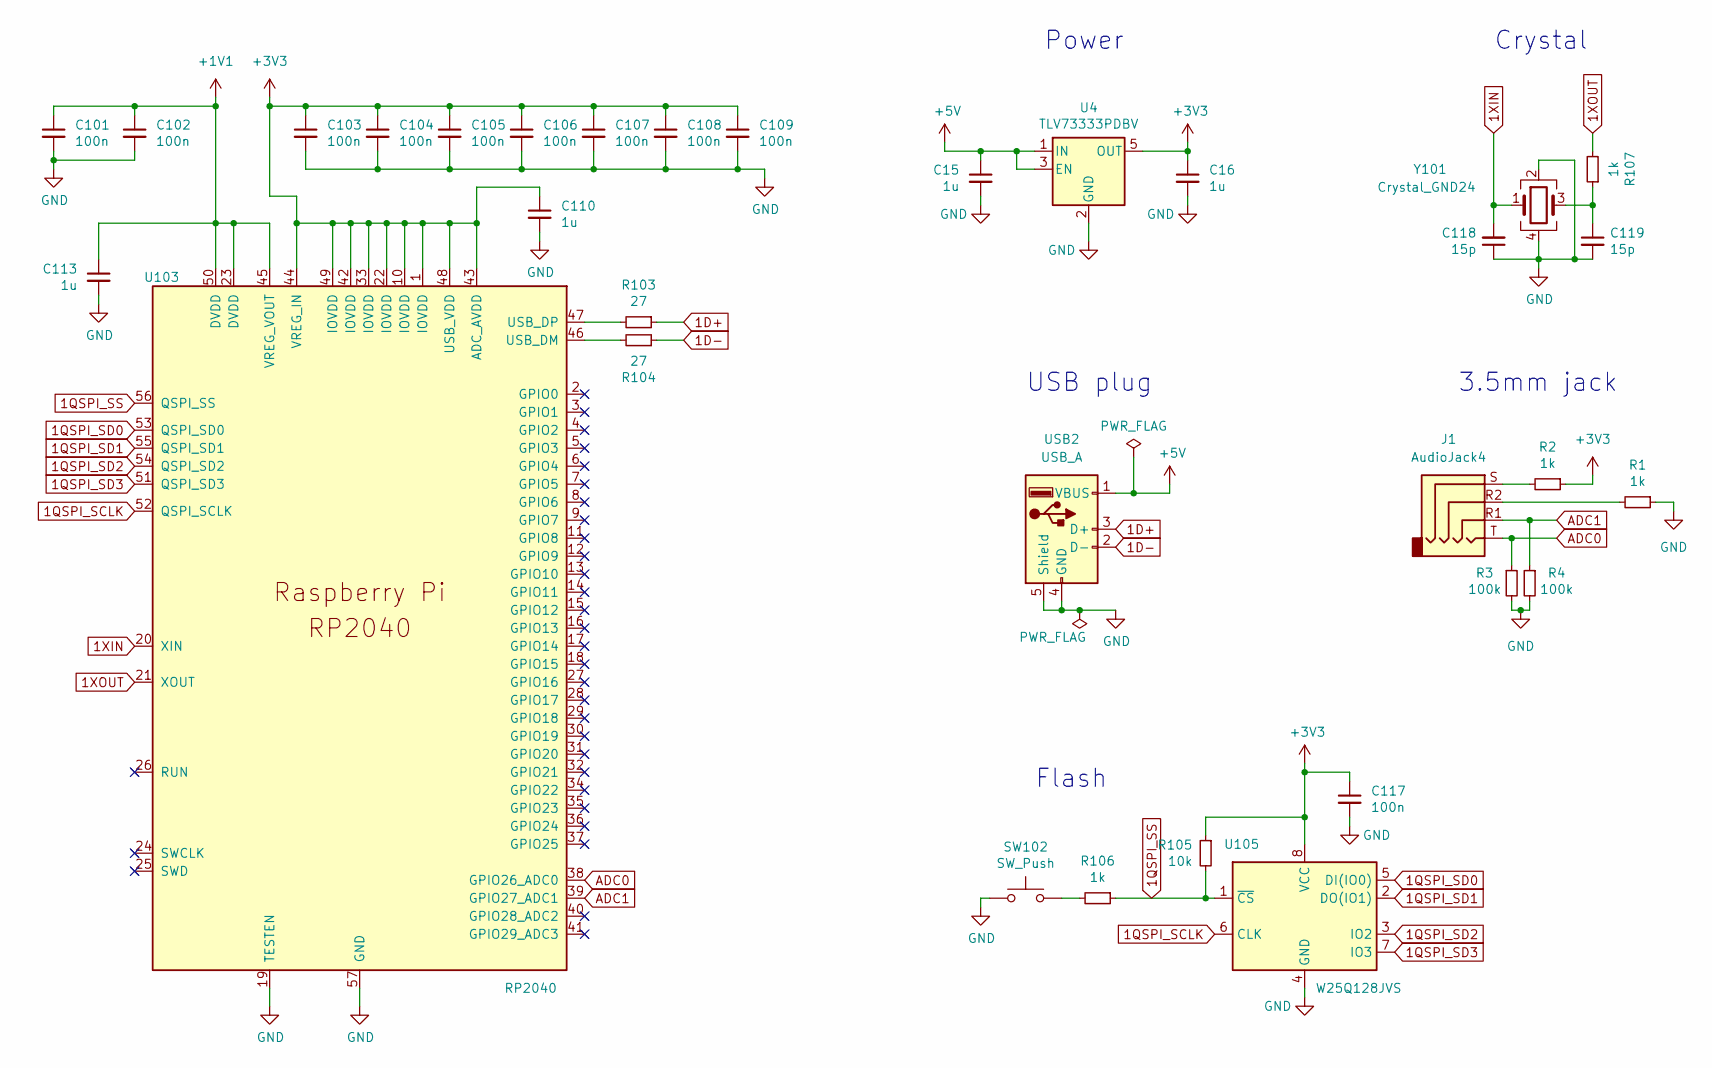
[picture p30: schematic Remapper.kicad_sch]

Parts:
C15, C16, C110, C113: 1u; C_0402_1005Metric; LCSC C52923
C101, C102, C103, C104, C105, C106, C107, C108, C109, C117: 100n; C_0402_1005Metric; LCSC C1525
C118, C119: 15p; C_0402_1005Metric; LCSC C1548
J1: AudioJack4; C18185602; LCSC C18185602
R1, R2, R106, R107: 1k; R_0402_1005Metric; LCSC C11702
R3, R4: 100k; R_0402_1005Metric; LCSC C25741
R103, R104: 27; R_0402_1005Metric; LCSC C138021
R105: 10k; R_0402_1005Metric; LCSC C25744
SW102: SW_Push; SW_SPST_B3U-1000P; LCSC C231329
U4: TLV73333PDBV; SOT-23-5; LCSC C134139
U103: RP2040; RP2040-QFN-56; LCSC C2040
U105: W25Q128JVS; 8-USON; LCSC C2843335
USB2: USB_A; C98125; LCSC C98125
Y101: Crystal_GND24; Crystal_SMD_2520-4Pin_2.5x2.0mm; LCSC C90603

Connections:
1D+: R103.1, USB2.3 (D+)
1D-: R104.1, USB2.2 (D-)
1QSPI_SCLK: U103.52 (QSPI_SCLK), U105.6 (CLK)
1QSPI_SD0: U103.53 (QSPI_SD0), U105.5 (DI(IO0))
1QSPI_SD1: U103.55 (QSPI_SD1), U105.2 (DO(IO1))
1QSPI_SD2: U103.54 (QSPI_SD2), U105.3 (IO2)
1QSPI_SD3: U103.51 (QSPI_SD3), U105.7 (IO3)
1QSPI_SS: R105.2, R106.1, U103.56 (QSPI_SS), U105.1 (~CS)
1XIN: C118.2, U103.20 (XIN), Y101.1
1XOUT: R107.2, U103.21 (XOUT)
+1V1: C101.1, C102.1, C113.1, U103.23 (DVDD), U103.45 (VREG_VOUT), U103.50 (DVDD)
+3V3: C16.1, C103.1, C104.1, C105.1, C106.1, C107.1, C108.1, C109.1, C110.1, C117.1, R2.1, R105.1, U4.5 (OUT), U103.1 (IOVDD), U103.10 (IOVDD), U103.22 (IOVDD), U103.33 (IOVDD), U103.42 (IOVDD), U103.43 (ADC_AVDD), U103.44 (VREG_IN), U103.48 (USB_VDD), U103.49 (IOVDD), U105.8 (VCC)
+5V: C15.1, U4.1 (IN), U4.3 (EN), USB2.1 (VBUS)
ADC0: J1.T, R3.1, U103.38 (GPIO26_ADC0)
ADC1: J1.R1, R4.1, U103.39 (GPIO27_ADC1)
GND: C15.2, C16.2, C101.2, C102.2, C103.2, C104.2, C105.2, C106.2, C107.2, C108.2, C109.2, C110.2, C113.2, C117.2, C118.1, C119.2, R1.1, R3.2, R4.2, SW102.1, U4.2 (GND), U103.19 (TESTEN), U103.57 (GND), U105.4 (GND), USB2.4 (GND), USB2.5 (Shield), Y101.2, Y101.4
unnamed: C119.1, R107.1, Y101.3
unnamed: J1.R2, R1.2
unnamed: J1.S, R2.2
unnamed: R106.2, SW102.2
unnamed: R104.2, U103.46 (USB_DM)
unnamed: R103.2, U103.47 (USB_DP)

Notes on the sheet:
Crystal
USB plug
Power
3.5mm jack
Flash

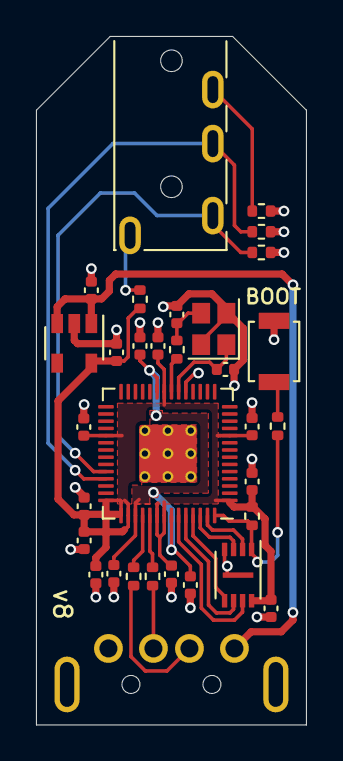
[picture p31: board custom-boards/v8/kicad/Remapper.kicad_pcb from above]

Board: 2 copper layers, 15.0 x 38.2 mm, 32 parts (0 on the bottom side), 22 nets.

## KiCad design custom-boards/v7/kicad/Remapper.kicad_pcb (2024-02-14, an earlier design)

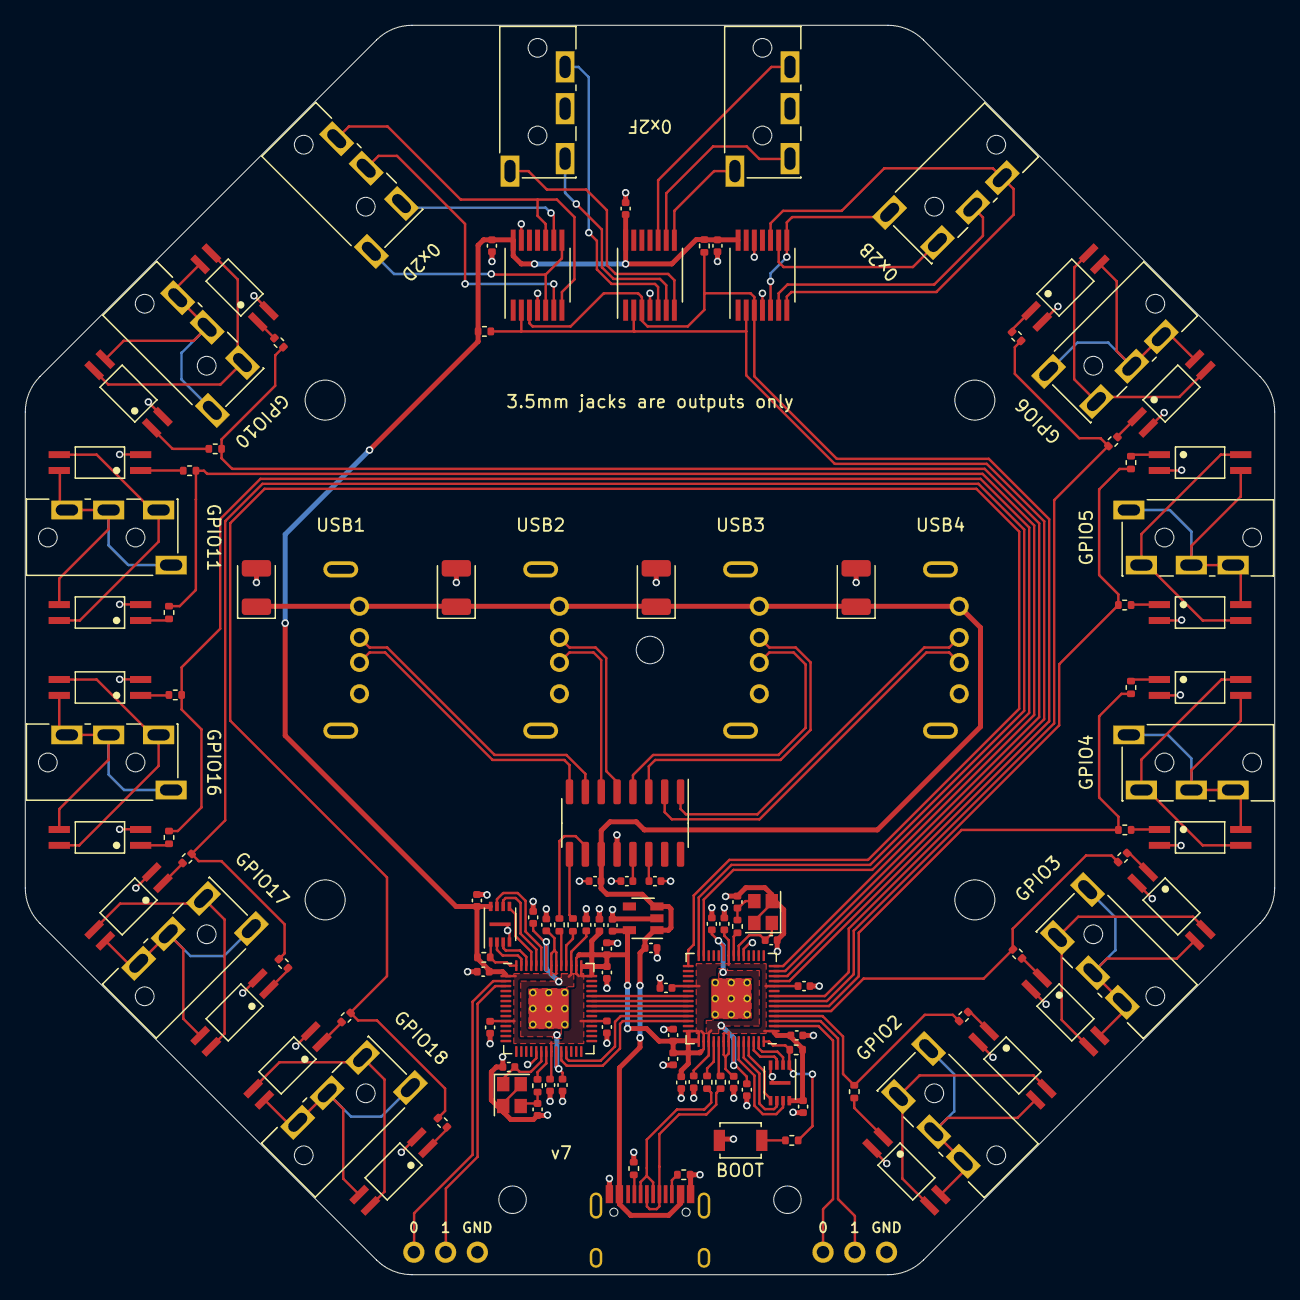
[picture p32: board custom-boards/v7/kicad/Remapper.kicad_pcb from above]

Board: 2 copper layers, 100.0 x 100.0 mm, 133 parts (0 on the bottom side), 120 nets.

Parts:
C1, C2, C3, C4, C5, C6, C7, C8, C9, C11, C12, C14, C17, C101, C102, C103, C104, C105, C106, C107, C108, C109, C117: 100n; C_0402_1005Metric
C10, C13, C15, C16, C110, C113: 1u; C_0402_1005Metric
C18, C19, C118, C119: 15p; C_0402_1005Metric
C201, C202, C203, C204: 100u; CP_EIA-3528-21_Kemet-B
C205, C206, C207: 10u; C_0402_1005Metric
H1, H2, H3, H4: MountingHole; MountingHole_3.2mm_M3
H5, H6, H7: MountingHole; MountingHole_2.2mm_M2
J1, J2, J3, J4, J5, J6, J7, J8, J9, J10, J11, J12, J13, J14: AudioJack4; C136687
J15, J16: Conn_01x03_Pin; PinHeader_1x03_P2.54mm_Vertical
R1, R2, R6, R8, R9, R10, R11, R12, R13, R14, R17, R18, R19, R20, R21, R22, R23, R24, R25, R26: 470; R_0402_1005Metric
R3, R4, R103, R104: 27; R_0402_1005Metric
R5, R105: 10k; R_0402_1005Metric
R7, R106, R107: 1k; R_0402_1005Metric
R15, R16: 4.7k; R_0402_1005Metric
R101, R102: 5.1k; R_0402_1005Metric
SW102: SW_Push; SW_SPST_B3U-1000P
U1: SL2.1A; SOP-16_3.9x9.9mm_P1.27mm
U2, U6, U7: MCP4651; TSSOP-14
U3, U103: RP2040; RP2040-QFN-56
U4: TLV73333PDBV; SOT-23-5
U5, U105: W25Q16JVUXIQ; 8-USON
U8, U9, U10, U11, U12, U13, U14, U15, U16, U17, U18, U19, U20, U21, U22, U23, U24, U25, U26, U27: EL3H7-G; SOP-4-1.27mm
USB1, USB2, USB3, USB4: USB_A; C2689978
USB101: HRO-TYPE-C-31-M-12; HRO-TYPE-C-31-M-12-Assembly
Y1, Y101: Crystal_GND24; Crystal_SMD_2520-4Pin_2.5x2.0mm

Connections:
1D+: R103.1, USB101.6 (DP1), USB101.8 (DP2)
1D-: R104.1, USB101.5 (DN2), USB101.7 (DN1)
1QSPI_SCLK: U103.52 (QSPI_SCLK), U105.6 (CLK)
1QSPI_SD0: U103.53 (QSPI_SD0), U105.5 (DI(IO0))
1QSPI_SD1: U103.55 (QSPI_SD1), U105.2 (DO(IO1))
1QSPI_SD2: U103.54 (QSPI_SD2), U105.3 (IO2)
1QSPI_SD3: U103.51 (QSPI_SD3), U105.7 (IO3)
1QSPI_SS: R105.2, R106.1, U103.56 (QSPI_SS), U105.1 (~CS)
1XIN: C118.2, U103.20 (XIN), Y101.1
1XOUT: R107.2, U103.21 (XOUT)
+1V1: C1.1, C2.1, C13.1, U3.23 (DVDD), U3.45 (VREG_VOUT), U3.50 (DVDD)
+1V2: C101.1, C102.1, C113.1, U103.23 (DVDD), U103.45 (VREG_VOUT), U103.50 (DVDD)
+3V3: C3.1, C4.1, C5.1, C6.1, C7.1, C8.1, C9.1, C10.1, C11.1, C12.1, C14.1, C16.1, C17.1, C103.1, C104.1, C105.1, C106.1, C107.1, C108.1, C109.1, C110.1, C117.1, R5.1, R15.1, R16.1, R105.1, U2.14 (VDD), U3.1 (IOVDD), U3.10 (IOVDD), U3.22 (IOVDD), U3.33 (IOVDD), U3.42 (IOVDD), U3.43 (ADC_AVDD), U3.44 (VREG_IN), U3.48 (USB_VDD), U3.49 (IOVDD), U4.5 (OUT), U5.8 (VCC), U6.14 (VDD), U7.14 (VDD), U103.1 (IOVDD), U103.10 (IOVDD), U103.22 (IOVDD), U103.33 (IOVDD), U103.42 (IOVDD), U103.43 (ADC_AVDD), U103.44 (VREG_IN), U103.48 (USB_VDD), U103.49 (IOVDD), U105.8 (VCC)
+5V: C15.1, C201.1, C202.1, C203.1, C204.1, C207.1, U1.11 (VDD5), U4.1 (IN), U4.3 (EN), USB1.1 (VBUS), USB2.1 (VBUS), USB3.1 (VBUS), USB4.1 (VBUS), USB101.2 (VBUS), USB101.11 (VBUS)
A_GPIO0: J15.1, U103.2 (GPIO0)
A_GPIO1: J15.2, U103.3 (GPIO1)
B_GPIO0: J16.1, U3.2 (GPIO0)
B_GPIO1: J16.2, U3.3 (GPIO1)
CTS1RTS: U3.38 (GPIO26_ADC0), U103.35 (GPIO23)
D+: R3.1, U1.10 (DP)
D-: R4.1, U1.9 (DM)
DM1: U1.7 (DM1), USB1.2 (D-)
DM2: U1.5 (DM2), USB2.2 (D-)
DM3: U1.3 (DM3), USB3.2 (D-)
DM4: U1.1 (DM4), USB4.2 (D-)
DP1: U1.8 (DP1), USB1.3 (D+)
DP2: U1.6 (DP2), USB2.3 (D+)
DP3: U1.4 (DP3), USB3.3 (D+)
DP4: U1.2 (DP4), USB4.3 (D+)
GND: C1.2, C2.2, C3.2, C4.2, C5.2, C6.2, C7.2, C8.2, C9.2, C10.2, C11.2, C12.2, C13.2, C14.2, C15.2, C16.2, C17.2, C18.1, C19.2, C101.2, C102.2, C103.2, C104.2, C105.2, C106.2, C107.2, C108.2, C109.2, C110.2, C113.2, C117.2, C118.1, C119.2, C201.2, C202.2, C203.2, C204.2, C205.2, C206.2, C207.2, J15.3, J16.3, R101.2, R102.2, SW102.1, U1.12 (GND), U2.4 (VSS), U2.13 (A1), U3.19 (TESTEN), U3.57 (GND), U4.2 (GND), U5.4 (GND), U6.4 (VSS), U6.12 (A2), U7.4 (VSS), U8.2, U9.2, U10.2, U11.2, U12.2, U13.2, U14.2, U15.2, U16.2, U17.2, U18.2, U19.2, U20.2, U21.2, U22.2, U23.2, U24.2, U25.2, U26.2, U27.2, U103.19 (TESTEN), U103.57 (GND), U105.4 (GND), USB1.4 (GND), USB1.5 (Shield), USB2.4 (GND), USB2.5 (Shield), USB3.4 (GND), USB3.5 (Shield), USB4.4 (GND), USB4.5 (Shield), USB101.1 (GND), USB101.12 (GND), USB101.13 (SHIELD), Y1.2, Y1.4, Y101.2, Y101.4
JACK1: R1.1, R17.1, U103.29 (GPIO18)
JACK2: R2.1, R6.1, U103.28 (GPIO17)
JACK3: R8.1, R9.1, U103.27 (GPIO16)
JACK4: R10.1, R11.1, U103.14 (GPIO11)
JACK5: R12.1, R13.1, U103.13 (GPIO10)
JACK6_R1: J1.R1, U2.6 (P1W)
JACK6_R2: J1.R2, U2.7 (P1A), U2.10 (P0B)
JACK6_S: J1.S, U2.5 (P1B), U2.8 (P0A)
JACK6_T: J1.T, U2.9 (P0W)
JACK7_R2: J3.R2, U7.5 (P1B)
JACK7_S: J3.S, U7.7 (P1A)
JACK7_T: J3.T, U7.6 (P1W)
JACK8_R2: J4.R2, U7.10 (P0B)
JACK8_S: J4.S, U7.8 (P0A)
JACK8_T: J4.T, U7.9 (P0W)
JACK9_R1: J2.R1, U6.6 (P1W)
JACK9_R2: J2.R2, U6.7 (P1A), U6.10 (P0B)
JACK9_S: J2.S, U6.5 (P1B), U6.8 (P0A)
JACK9_T: J2.T, U6.9 (P0W)
JACK10: R14.1, R18.1, U103.8 (GPIO6)
JACK11: R19.1, R20.1, U103.7 (GPIO5)
JACK12: R21.1, R22.1, U103.6 (GPIO4)
JACK13: R23.1, R24.1, U103.5 (GPIO3)
JACK14: R25.1, R26.1, U103.4 (GPIO2)
unnamed: C19.1, R7.1, Y1.3
unnamed: C119.1, R107.1, Y101.3
unnamed: J5.R1, J5.R2, J5.S, U8.4, U9.3
unnamed: J5.T, U8.3, U9.4
unnamed: J6.R1, J6.R2, J6.S, U10.4, U11.3
unnamed: J6.T, U10.3, U11.4
unnamed: J7.R1, J7.R2, J7.S, U12.4, U13.3
unnamed: J7.T, U12.3, U13.4
unnamed: J8.R1, J8.R2, J8.S, U14.4, U15.3
unnamed: J8.T, U14.3, U15.4
unnamed: J9.R1, J9.R2, J9.S, U16.4, U17.3
unnamed: J9.T, U16.3, U17.4
unnamed: J10.R1, J10.R2, J10.S, U18.4, U19.3
unnamed: J10.T, U18.3, U19.4
unnamed: J11.R1, J11.R2, J11.S, U20.4, U21.3
unnamed: J11.T, U20.3, U21.4
unnamed: J12.R1, J12.R2, J12.S, U22.4, U23.3
unnamed: J12.T, U22.3, U23.4
unnamed: J13.R1, J13.R2, J13.S, U24.4, U25.3
unnamed: J13.T, U24.3, U25.4
unnamed: J14.R1, J14.R2, J14.S, U26.4, U27.3
unnamed: J14.T, U26.3, U27.4
unnamed: R1.2, U9.1
unnamed: R2.2, U10.1
unnamed: R6.2, U11.1
unnamed: R8.2, U12.1
unnamed: R9.2, U13.1
unnamed: R10.2, U14.1
unnamed: R11.2, U15.1
unnamed: R12.2, U16.1
unnamed: R13.2, U17.1
unnamed: R14.2, U18.1
unnamed: R17.2, U8.1
unnamed: R18.2, U19.1
unnamed: R19.2, U20.1
unnamed: R20.2, U21.1
unnamed: R21.2, U22.1
unnamed: R22.2, U23.1
unnamed: R23.2, U24.1
unnamed: R24.2, U25.1
unnamed: R25.2, U26.1
unnamed: R26.2, U27.1
unnamed: R106.2, SW102.2
unnamed: C206.1, U1.14 (VDD18)
unnamed: C205.1, U1.13 (VDD33)
unnamed: R4.2, U3.46 (USB_DM)
unnamed: R3.2, U3.47 (USB_DP)
unnamed: R104.2, U103.46 (USB_DM)
unnamed: R103.2, U103.47 (USB_DP)
unnamed: R102.1, USB101.4 (CC1)
unnamed: R101.1, USB101.10 (CC2)
QSPI_SCLK: U3.52 (QSPI_SCLK), U5.6 (CLK)
QSPI_SD0: U3.53 (QSPI_SD0), U5.5 (DI(IO0))
QSPI_SD1: U3.55 (QSPI_SD1), U5.2 (DO(IO1))
QSPI_SD2: U3.54 (QSPI_SD2), U5.3 (IO2)
QSPI_SD3: U3.51 (QSPI_SD3), U5.7 (IO3)
QSPI_SS: R5.2, U3.56 (QSPI_SS), U5.1 (~CS)
RTS1CTS: U3.35 (GPIO23), U103.38 (GPIO26_ADC0)
RX1TX: U3.37 (GPIO25), U103.36 (GPIO24)
SCL: R15.2, U2.2 (SCL), U6.2 (SCL), U7.2 (SCL), U103.12 (GPIO9)
SDA: R16.2, U2.3 (SDA), U6.3 (SDA), U7.3 (SDA), U103.11 (GPIO8)
SWCLK: U3.24 (SWCLK), U103.40 (GPIO28_ADC2)
SWD: U3.25 (SWD), U103.39 (GPIO27_ADC1)
TX1RX: U3.36 (GPIO24), U103.37 (GPIO25)
XIN: C18.2, U3.20 (XIN), Y1.1
XOUT: R7.2, U3.21 (XOUT)

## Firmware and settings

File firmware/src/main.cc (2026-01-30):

#include <set>
#include <unordered_map>
#include <unordered_set>
#include <vector>

#include <bsp/board_api.h>
#include <tusb.h>

#ifdef ADC_ENABLED
#include <hardware/adc.h>
#endif
#include <hardware/flash.h>
#include <hardware/gpio.h>
#include <pico/bootrom.h>
#include <pico/mutex.h>
#include <pico/platform.h>
#include <pico/stdio.h>
#include <pico/unique_id.h>

#include "activity_led.h"
#include "config.h"
#include "crc.h"
#include "descriptor_parser.h"
#include "globals.h"
#include "i2c.h"
#include "mcp4651.h"
#include "our_descriptor.h"
#include "platform.h"
#include "remapper.h"
#include "tick.h"

// RP2350 UF2s wipe the last sector of flash every time
// because of RP2350-E10 errata mitigation. So we put
// the config one sector down.
#if PICO_RP2350
#define CONFIG_OFFSET_IN_FLASH (PICO_FLASH_SIZE_BYTES - PERSISTED_CONFIG_SIZE - 4096)
#else
#define CONFIG_OFFSET_IN_FLASH (PICO_FLASH_SIZE_BYTES - PERSISTED_CONFIG_SIZE)
#endif

#define FLASH_CONFIG_IN_MEMORY (((uint8_t*) XIP_BASE) + CONFIG_OFFSET_IN_FLASH)

#define ADC_USAGE_PAGE 0xFFF80000

uint64_t next_print = 0;

mutex_t mutexes[(uint8_t) MutexId::N];

uint32_t gpio_valid_pins_mask = 0;
uint32_t gpio_in_mask = 0;
uint32_t gpio_out_mask = 0;
uint32_t prev_gpio_state = 0;
uint64_t last_gpio_change[32] = { 0 };
bool set_gpio_dir_pending = false;

#ifdef ADC_ENABLED
uint16_t prev_adc_state[NADCS] = { 0 };
#endif

void print_stats_maybe() {
    uint64_t now = time_us_64();
    if (now > next_print) {
        print_stats();
        while (next_print < now) {
            next_print += 1000000;
        }
    }
}

void __no_inline_not_in_flash_func(sof_handler)(uint32_t frame_count) {
    sof_callback();
}

bool do_send_report(uint8_t interface, const uint8_t* report_with_id, uint8_t len) {
    if (tud_suspended() &&
        (our_descriptor->should_cause_wakeup != nullptr) &&
        our_descriptor->should_cause_wakeup(report_with_id[0], report_with_id + 1, len - 1)) {
        tud_remote_wakeup();
    } else {
        tud_hid_n_report(interface, report_with_id[0], report_with_id + 1, len - 1);
    }
    return true;  // XXX?
}

void gpio_pins_init() {
    gpio_valid_pins_mask = get_gpio_valid_pins_mask();
    gpio_init_mask(gpio_valid_pins_mask);
}

void set_gpio_inout_masks(uint32_t in_mask, uint32_t out_mask) {
    // if some pin appears as both input and output, input wins
    gpio_out_mask = (out_mask & ~in_mask) & gpio_valid_pins_mask;
    // we treat all pins except the output ones as input so that the monitor works
    gpio_in_mask = gpio_valid_pins_mask & ~gpio_out_mask;
    set_gpio_dir_pending = true;
}

void set_gpio_dir() {
    gpio_set_dir_masked(gpio_in_mask, 0);
    // output pin direction will be set in write_gpio()
    for (uint8_t i = 0; i <= 29; i++) {
        uint32_t bit = 1 << i;
        if (gpio_valid_pins_mask & bit) {
            gpio_set_pulls(i, gpio_in_mask & bit, false);
        }
    }
}

#ifdef ADC_ENABLED
void adc_pins_init() {
    adc_init();
    for (int n = 26; n < 26 + NADCS; n++) {
        adc_gpio_init(n);
    }

#ifdef PICO_SMPS_MODE_PIN
    // (This only does anything on a Pico, but won't hurt on custom board v8.)
    gpio_init(PICO_SMPS_MODE_PIN);
    gpio_set_dir(PICO_SMPS_MODE_PIN, GPIO_OUT);
    gpio_put(PICO_SMPS_MODE_PIN, true);
#endif
}
#endif

bool read_gpio(uint64_t now) {
    uint32_t gpio_state = gpio_get_all() & gpio_in_mask;
    uint32_t changed = prev_gpio_state ^ gpio_state;
    if (changed != 0) {
        for (uint8_t i = 0; i <= 29; i++) {
            uint32_t bit = 1 << i;
            if (changed & bit) {
                if (last_gpio_change[i] + gpio_debounce_time <= now) {
                    uint32_t usage = GPIO_USAGE_PAGE | i;
                    int32_t state = !(gpio_state & bit);  // active low
                    set_input_state(usage, state, state);
                    if (monitor_enabled) {
                        monitor_usage(usage, state, 0);
                    }
                    last_gpio_change[i] = now;
                } else {
                    // ignore this change
                    gpio_state ^= bit;
                    changed ^= bit;
                }
            }
        }
        prev_gpio_state = gpio_state;
    }
    return changed != 0;
}

void write_gpio() {
    if (suspended) {
        return;
    }

    uint32_t value = gpio_out_state[0] | (gpio_out_state[1] << 8) | (gpio_out_state[2] << 16) | (gpio_out_state[3] << 24);
    switch (gpio_output_mode) {
        case 0:
            gpio_put_masked(gpio_out_mask, value);
            gpio_set_dir_masked(gpio_out_mask, gpio_out_mask);
            break;
        case 1:
            gpio_put_masked(gpio_out_mask, 0);
            gpio_set_dir_masked(gpio_out_mask, value);
            break;
    }
    memset(gpio_out_state, 0, sizeof(gpio_out_state));
}

#ifdef ADC_ENABLED
bool read_adc() {
    bool changed = false;
    for (int i = 0; i < NADCS; i++) {
        adc_select_input(i);
        uint16_t state = adc_read();
        if (state != prev_adc_state[i]) {
            changed = true;
            prev_adc_state[i] = state;
        }
        uint32_t usage = ADC_USAGE_PAGE | i;
        set_input_state(usage, state, state >> 4);
        if (monitor_enabled) {
            monitor_usage(usage, state, 0);
        }
    }
    return changed;
}
#endif

void do_persist_config(uint8_t* buffer) {
#if !PICO_COPY_TO_RAM
    uint32_t ints = save_and_disable_interrupts();
#endif
    flash_range_erase(CONFIG_OFFSET_IN_FLASH, PERSISTED_CONFIG_SIZE);
    flash_range_program(CONFIG_OFFSET_IN_FLASH, buffer, PERSISTED_CONFIG_SIZE);
#if !PICO_COPY_TO_RAM
    restore_interrupts(ints);
#endif
}

void reset_to_bootloader() {
    reset_usb_boot(0, 0);
}

void pair_new_device() {
}

void clear_bonds() {
}

void my_mutexes_init() {
    for (int i = 0; i < (int8_t) MutexId::N; i++) {
        mutex_init(&mutexes[i]);
    }
}

void my_mutex_enter(MutexId id) {
    mutex_enter_blocking(&mutexes[(uint8_t) id]);
}

void my_mutex_exit(MutexId id) {
    mutex_exit(&mutexes[(uint8_t) id]);
}

uint64_t get_time() {
    return time_us_64();
}

uint64_t get_unique_id() {
    pico_unique_board_id_t unique_id;
    pico_get_unique_board_id(&unique_id);
    uint64_t ret = 0;
    for (int i = 0; i < 8; i++) {
        ret |= (uint64_t) unique_id.id[7 - i] << (8 * i);
    }
    return ret;
}

int main() {
    my_mutexes_init();
    gpio_pins_init();
#ifdef I2C_ENABLED
    our_i2c_init();
#endif
#ifdef ADC_ENABLED
    adc_pins_init();
#endif
    tick_init();
    load_config(FLASH_CONFIG_IN_MEMORY);
    our_descriptor = &our_descriptors[our_descriptor_number];
    parse_our_descriptor();
    set_mapping_from_config();
    board_init();
    extra_init();
    tusb_init();
    stdio_init_all();

    tud_sof_isr_set(sof_handler);

    next_print = time_us_64() + 1000000;

    while (true) {
        bool tick;
        bool new_report;
        read_report(&new_report, &tick);
        if (new_report) {
            activity_led_on();
        }
        if (their_descriptor_updated) {
            update_their_descriptor_derivates();
            their_descriptor_updated = false;
        }
        if (tick) {
            bool gpio_state_changed = read_gpio(time_us_64());
            if (gpio_state_changed) {
                activity_led_on();
            }
#ifdef ADC_ENABLED
            read_adc();
#endif
            process_mapping(true);
            write_gpio();
#ifdef MCP4651_ENABLED
            mcp4651_write();
#endif
        }
        tud_task();
        if (boot_protocol_updated) {
            parse_our_descriptor();
            boot_protocol_updated = false;
            config_updated = true;
        }
        if (resume_pending) {
            resume_pending = false;
            suspended = false;
        }
        if (config_updated) {
            set_mapping_from_config();
            config_updated = false;
        }
        if (set_gpio_dir_pending && !suspended) {
            set_gpio_dir();
            set_gpio_dir_pending = false;
        }
        if (tud_hid_n_ready(0) || tud_suspended()) {
            send_report(do_send_report);
        }
        if (monitor_enabled && tud_hid_n_ready(1)) {
            send_monitor_report(do_send_report);
        }
        if (our_descriptor->main_loop_task != nullptr) {
            our_descriptor->main_loop_task();
        }
        send_out_report();
        if (need_to_persist_config) {
            persist_config_return_code = persist_config();
            need_to_persist_config = false;
        }

        print_stats_maybe();

        activity_led_off_maybe();
    }

    return 0;
}

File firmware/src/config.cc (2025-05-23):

#include <cstdio>
#include <cstring>
#include <unordered_set>

#include "config.h"
#include "crc.h"
#include "globals.h"
#include "interval_override.h"
#include "our_descriptor.h"
#include "platform.h"
#include "remapper.h"

const uint8_t CONFIG_VERSION = 18;

const uint8_t CONFIG_FLAG_UNMAPPED_PASSTHROUGH = 0x01;
const uint8_t CONFIG_FLAG_UNMAPPED_PASSTHROUGH_MASK = 0b00001111;
const uint8_t CONFIG_FLAG_UNMAPPED_PASSTHROUGH_BIT = 0;
const uint8_t CONFIG_FLAG_IGNORE_AUTH_DEV_INPUTS_BIT = 4;
const uint8_t CONFIG_FLAG_GPIO_OUTPUT_MODE_BIT = 5;
const uint8_t CONFIG_FLAG_NORMALIZE_GAMEPAD_INPUTS_BIT = 6;

ConfigCommand last_config_command = ConfigCommand::NO_COMMAND;
uint32_t requested_index = 0;
uint32_t requested_secondary_index = 0;

bool checksum_ok(const uint8_t* buffer, uint16_t data_size) {
    return crc32(buffer, data_size - 4) == ((crc32_t*) (buffer + data_size - 4))->crc32;
}

bool persisted_version_ok(const uint8_t* buffer) {
    uint8_t version = ((config_version_t*) buffer)->version;
    return (version >= 3) && (version <= CONFIG_VERSION);
}

bool command_version_ok(const uint8_t* buffer) {
    uint8_t version = ((set_feature_t*) buffer)->version;
    return version == CONFIG_VERSION;
}

static mapping_config11_t mapping_config_10_to_11(mapping_config10_t mapping) {
    return (mapping_config11_t){
        .target_usage = mapping.target_usage,
        .source_usage = mapping.source_usage,
        .scaling = mapping.scaling,
        .layer_mask = mapping.layer_mask,
        .flags = mapping.flags,
        .hub_ports = 0,
    };
}

void load_config_v3_v4(const uint8_t* persisted_config) {
    persist_config_v4_t* config = (persist_config_v4_t*) persisted_config;
    if (config->version == 3) {
        unmapped_passthrough_layer_mask = (config->flags & CONFIG_FLAG_UNMAPPED_PASSTHROUGH) ? 1 : 0;
    }
    if (config->version >= 4) {
        unmapped_passthrough_layer_mask =
            (config->flags & CONFIG_FLAG_UNMAPPED_PASSTHROUGH_MASK) >> CONFIG_FLAG_UNMAPPED_PASSTHROUGH_BIT;
    }
    partial_scroll_timeout = config->partial_scroll_timeout;
    interval_override = config->interval_override;
    mapping_config10_t* buffer_mappings = (mapping_config10_t*) (persisted_config + sizeof(persist_config_v4_t));
    for (uint32_t i = 0; i < config->mapping_count; i++) {
        config_mappings.push_back(mapping_config_10_to_11(buffer_mappings[i]));
        if (config->version == 3) {
            config_mappings.back().layer_mask = 1 << config_mappings.back().layer_mask;
        }
    }

    if (config->version >= 4) {
        const uint8_t* macros_config_ptr = (persisted_config + sizeof(persist_config_v4_t) + config->mapping_count * sizeof(mapping_config10_t));
        my_mutex_enter(MutexId::MACROS);
        for (int i = 0; i < NMACROS_8; i++) {
            macros[i].clear();
            uint8_t macro_len = *macros_config_ptr;
            macros_config_ptr++;
            macros[i].reserve(macro_len);
            for (int j = 0; j < macro_len; j++) {
                uint8_t entry_len = *macros_config_ptr;
                macros_config_ptr++;
                macros[i].push_back({});
                macros[i].back().reserve(entry_len);
                for (int k = 0; k < entry_len; k++) {
                    macros[i].back().push_back(((macro_item_t*) macros_config_ptr)->usage);
                    macros_config_ptr += sizeof(macro_item_t);
                }
            }
        }
        my_mutex_exit(MutexId::MACROS);
    }
}
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

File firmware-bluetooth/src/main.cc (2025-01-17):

#include <errno.h>
#include <stddef.h>

#include <bluetooth/gatt_dm.h>
#include <bluetooth/scan.h>
#include <bluetooth/services/hogp.h>
#include <zephyr/bluetooth/bluetooth.h>
#include <zephyr/bluetooth/conn.h>
#include <zephyr/bluetooth/gatt.h>
#include <zephyr/bluetooth/hci.h>
#include <zephyr/bluetooth/uuid.h>
#include <zephyr/drivers/gpio.h>
#include <zephyr/kernel.h>
#include <zephyr/logging/log.h>
#include <zephyr/settings/settings.h>
#include <zephyr/sys/byteorder.h>
#include <zephyr/sys/printk.h>
#include <zephyr/sys/reboot.h>
#include <zephyr/types.h>
#include <zephyr/usb/class/usb_hid.h>
#include <zephyr/usb/usb_device.h>

#include "config.h"
#include "descriptor_parser.h"
#include "globals.h"
#include "our_descriptor.h"
#include "platform.h"
#include "remapper.h"

LOG_MODULE_REGISTER(remapper, LOG_LEVEL_DBG);

#define CHK(X) ({ int err = X; if (err != 0) { LOG_ERR("%s returned %d (%s:%d)", #X, err, __FILE__, __LINE__); } err == 0; })

static const int SCAN_DELAY_MS = 1000;
static const int CLEAR_BONDS_BUTTON_PRESS_MS = 3000;

// these macros don't work in C++ when used directly ("taking address of temporary array")
static auto const BT_UUID_HIDS_ = (struct bt_uuid_16) BT_UUID_INIT_16(BT_UUID_HIDS_VAL);
static auto BT_ADDR_LE_ANY_ = BT_ADDR_LE_ANY[0];
static auto BT_CONN_LE_CREATE_CONN_ = BT_CONN_LE_CREATE_CONN[0];

static struct bt_hogp hogps[CONFIG_BT_MAX_CONN];

static K_SEM_DEFINE(usb_sem0, 1, 1);
static K_SEM_DEFINE(usb_sem1, 1, 1);

static struct k_mutex mutexes[(uint8_t) MutexId::N];

static struct k_mutex get_report_mutex;
static uint8_t get_report_buf[64];
static bool get_report_response_ready = false;

static const struct device* hid_dev0;
static const struct device* hid_dev1;  // config interface

struct report_type {
    uint16_t interface;
    uint8_t len;
    uint8_t data[65];
};

struct descriptor_type {
    uint16_t size;
    uint8_t conn_idx;
    uint8_t data[512];
};

struct hogp_ready_type {
    struct bt_hogp* hogp;
};

struct disconnected_type {
    uint8_t conn_idx;
};

struct set_report_type {
    uint8_t report_id;
    uint8_t interface;
    uint16_t len;
    uint8_t data[64];
};

K_MSGQ_DEFINE(report_q, sizeof(struct report_type), 16, 4);
K_MSGQ_DEFINE(descriptor_q, sizeof(struct descriptor_type), 2, 4);
K_MSGQ_DEFINE(hogp_ready_q, sizeof(struct hogp_ready_type), CONFIG_BT_MAX_CONN, 4);
K_MSGQ_DEFINE(disconnected_q, sizeof(struct disconnected_type), CONFIG_BT_MAX_CONN, 4);
K_MSGQ_DEFINE(set_report_q, sizeof(struct set_report_type), 8, 4);
ATOMIC_DEFINE(tick_pending, 1);

#define SW0_NODE DT_ALIAS(sw0)
#if !DT_NODE_HAS_STATUS(SW0_NODE, okay)
#error "Unsupported board: sw0 devicetree alias is not defined"
#endif

#define LED0_NODE DT_ALIAS(led0)
#if !DT_NODE_HAS_STATUS(LED0_NODE, okay)
#error "Unsupported board: led0 devicetree alias is not defined"
#endif

#define LED1_NODE DT_ALIAS(led1)
#if !DT_NODE_HAS_STATUS(LED1_NODE, okay)
#error "Unsupported board: led1 devicetree alias is not defined"
#endif

static const struct gpio_dt_spec button = GPIO_DT_SPEC_GET(SW0_NODE, gpios);

static struct gpio_callback button_cb_data;

static const struct gpio_dt_spec led0 = GPIO_DT_SPEC_GET(LED0_NODE, gpios);
static const struct gpio_dt_spec led1 = GPIO_DT_SPEC_GET(LED1_NODE, gpios);

static bool scanning = false;
static bool peers_only = true;

static struct bt_le_conn_param* conn_param = BT_LE_CONN_PARAM(6, 6, 44, 400);

static void activity_led_off_work_fn(struct k_work* work) {
    gpio_pin_set_dt(&led0, false);
}
static K_WORK_DELAYABLE_DEFINE(activity_led_off_work, activity_led_off_work_fn);

enum class LedMode {
    OFF = 0,
    ON = 1,
    BLINK = 2,
};

static atomic_t led_blink_count = ATOMIC_INIT(0);
static atomic_t led_mode = (atomic_t) ATOMIC_INIT(LedMode::OFF);
static int led_blinks_left = 0;
static bool next_blink_state = true;

static void led_work_fn(struct k_work* work);
static K_WORK_DELAYABLE_DEFINE(led_work, led_work_fn);

static void led_work_fn(struct k_work* work) {
    LedMode my_led_mode = (LedMode) atomic_get(&led_mode);
    switch (my_led_mode) {
        case LedMode::OFF:
            gpio_pin_set_dt(&led1, false);
            break;
        case LedMode::ON:
            gpio_pin_set_dt(&led1, true);
            break;
        case LedMode::BLINK: {
            int next_work = 0;
            if (next_blink_state) {
                if (led_blinks_left > 0) {
                    led_blinks_left--;
                    gpio_pin_set_dt(&led1, true);
                    next_blink_state = false;
                    next_work = 100;
                } else {
                    led_blinks_left = atomic_get(&led_blink_count);
                    gpio_pin_set_dt(&led1, false);
                    next_work = 1000;
                }
            } else {
                gpio_pin_set_dt(&led1, false);
                next_blink_state = true;
                next_work = 100;
            }
            k_work_reschedule(&led_work, K_MSEC(next_work));
            break;
        }
    }
}

static void set_led_mode(LedMode led_mode_) {
    if (atomic_set(&led_mode, (atomic_val_t) led_mode_) != (atomic_val_t) led_mode_) {
        k_work_reschedule(&led_work, K_NO_WAIT);
    }
}

static void scan_start() {
    if (CHK(bt_scan_start(BT_SCAN_TYPE_SCAN_PASSIVE))) {
        LOG_DBG("Scanning started.");
        scanning = true;
    }
}

static void scan_stop() {
    if (CHK(bt_scan_stop())) {
        LOG_DBG("Scanning stopped.");
        scanning = false;
        set_led_mode(LedMode::BLINK);
    }
}

static void process_bond(const struct bt_bond_info* info, void* user_data) {
    char addr_str[BT_ADDR_LE_STR_LEN];
    bt_addr_le_to_str(&info->addr, addr_str, sizeof(addr_str));
    LOG_DBG("%s", addr_str);
    (*((int*) user_data))++;
    CHK(bt_scan_filter_add(BT_SCAN_FILTER_TYPE_ADDR, &info->addr));
}

static void count_conn_cb(struct bt_conn* conn, void* data) {
    (*((int*) data))++;
}

static int count_connections() {
    int conn_count = 0;
    bt_conn_foreach(BT_CONN_TYPE_LE, count_conn_cb, &conn_count);
    atomic_set(&led_blink_count, conn_count);
    return conn_count;
}

static bool scan_setup_filters() {
    bt_scan_filter_remove_all();

    if (!CHK(bt_scan_filter_add(BT_SCAN_FILTER_TYPE_UUID, (struct bt_uuid*) &BT_UUID_HIDS_))) {
        return false;
    }

    int bonded_count = 0;
    bt_foreach_bond(BT_ID_DEFAULT, process_bond, &bonded_count);

    int conn_count = count_connections();

    uint8_t filter_mode = BT_SCAN_UUID_FILTER;

    if (peers_only && (bonded_count > 0)) {
        if (conn_count == bonded_count) {
            LOG_DBG("all bonded peers connected, not scanning");
            return false;
        }
        filter_mode |= BT_SCAN_ADDR_FILTER;
        LOG_DBG("scanning for bonded peers only");
    } else {
        LOG_DBG("scanning for new peers");
        peers_only = false;
    }

    if (!CHK(bt_scan_filter_enable(filter_mode, true))) {
        return false;
    }

    return true;
}
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

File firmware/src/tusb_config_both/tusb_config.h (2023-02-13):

#ifndef _TUSB_CONFIG_H_
#define _TUSB_CONFIG_H_

#define CFG_TUSB_RHPORT0_MODE (OPT_MODE_DEVICE | OPT_MODE_FULL_SPEED)

#define CFG_TUSB_MEM_SECTION
#define CFG_TUSB_MEM_ALIGN __attribute__((aligned(4)))

#define CFG_TUD_ENDPOINT0_SIZE 64

#define CFG_TUD_HID 2
#define CFG_TUD_CDC 0
#define CFG_TUD_MSC 0
#define CFG_TUD_MIDI 0
#define CFG_TUD_VENDOR 0

#define CFG_TUD_HID_EP_BUFSIZE 64

#define BOARD_TUH_RHPORT 1
#define CFG_TUSB_RHPORT1_MODE (OPT_MODE_HOST | OPT_MODE_FULL_SPEED)

#define CFG_TUH_ENUMERATION_BUFSIZE 512

#define CFG_TUH_HUB 1
#define CFG_TUH_CDC 0
#define CFG_TUH_HID 16
#define CFG_TUH_MSC 0
#define CFG_TUH_VENDOR 0

#define CFG_TUH_DEVICE_MAX 16

#define CFG_TUH_HID_EPIN_BUFSIZE 64
#define CFG_TUH_HID_EPOUT_BUFSIZE 64

#define CFG_TUH_RPI_PIO_USB 1

#endif

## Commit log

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2022-06-04 Include libraries as submodules
    Add pico-sdk and TinyUSB as submodules.
    We have our own fork of TinyUSB.
    Also moves interval override to a separate file.
    Note that even though TinyUSB can now use Pico-PIO-USB as a backend,
    we still keep our local copy of an older version of Pico-PIO-USB as
    there are some issues with using it through TinyUSB that I haven't
    been able to track down.
    [config.cc]
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2022-06-13 Dual Pico version
    Adds a new hardware variant of the remapper, utilizing two Pico boards
    that communicate over serial.
    The reason for this is that while the bit-banged USB interface
    (Pico-PIO-USB library) is an awesome achievement, it has certain
    issues. With two Picos, we can use RP2040's native USB interface for
    both sides (host and device), which should result in improved
    compatibility.
    The Pico that works in host mode sends the reports it receives over
    serial to the other Pico that operates in device mode, where the
    mappings are applied and resulting reports are sent to the host.
    This commit also makes some overdue changes to the main loop with
    regard to how the mapping processing is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
    [config.cc, dual.h, our_descriptor.h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]
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2022-06-24 Multiple devices with same absolute usage fix
    This addresses the issue that came up after we added multiple devices
    support. The way we are keeping the input state meant that we only
    remember the state from the last received report for every usage so
    for example if there are two mice connected, you press and hold the
    left button on mouse 1 and then move mouse 2, the remapper thinks the
    button is released, even though it would make more sense to consider
    it pressed until it's released on mouse 1.
    With this commit we keep separate input state for every device (for
    absolute usages) and consider the input to be pressed if it's pressed
    on any of the devices.
    This also makes it even more obvious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
    [remapper.cc]
2022-06-25 Support longer report descriptors
    On the dual Pico version, the buffer size was 256 so devices with
    longer report desciptors didn't work.
    Bumped to 512 bytes, which matches the single Pico version and
    hopefully is enough to cover most devices in the wild.
    [serial.cc, serial.h, tusb_config.h]
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2022-07-13 Fix quirks not working on the dual version
    VID/PID were transmitted as 8 bits between B and A, when they should
    be 16 bits.
    This caused the quirks mechanism to not work on the dual version.
    [dual.h]
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2022-11-09 Custom boards
    Add files and documentation for custom Remapper boards.
    v1 has a USB Type-C port for connecting to the computer and a USB
    Type-A port for connecting devices.
    v2 doesn't have connectors and is meant for building into existing
    devices like trackballs.
    [Remapper-v1-BOM.csv, Remapper-v1-Bottom.stl, Remapper-v1-Top-no-holes.stl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]
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2022-12-05 Fix resolution multiplier regression in BT version
    When the second HID interface was introduced, get/set feature requests
    were mistakenly ignored on interface 0, which prevented
    high-resolution scroll from working.
    [main.cc]
2022-12-16 Fix command line config tools
    After we split the config collection into a separate USB interface,
    the command line tools needed an update to find the correct device.
    Also extracts common parts into one file.
    [get_config.py, set_config.py]
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2023-01-14 Mappings can now be present on more than one layer
    Previously each mapping was defined on exactly one layer. With this
    change, each mapping now has a list of layers on which it is active.
    Layer-triggering mappings are no longer implicitly present on all
    layers, but they are still forced to be present on the layer they
    activate.
    Also changes how the unmapped input passthrough setting works.
    Previously it was a single on/off switch and the passthrough only
    worked on layer 0. With this change, it can be enabled or disabled on
    each layer separately.
    Bumps config version to 4.
    Also fixes two bugs in sticky handling:
    - sticky button state was released on the release event (trailing
    edge) of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
    [config.cc, get_config.py, remapper.cc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]
2023-01-14 Add macros
    Adds a macro feature that works as follows.
    There's a fixed-length (8) table of macros. New usage codes
    "Macro 1"-"Macro 8" are introduced that can be outputs in a mapping.
    When a mapping with a macro as its output is triggered, the macro
    contents are queued and sent in subsequent reports.
    Each macro is a list of lists of usage codes. For example a macro
    might look like this:
    [[ Left Alt, Numpad 0 ],
    [ Left Alt, Numpad 1 ],
    [ Left Alt, Numpad 6 ],
    [ Left Alt, Numpad 5 ]]
    or like this:
    [[ Left Shift, H ],
    [ E ],
    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
    [config.cc, get_config.py, main.cc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]
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2023-01-16 Fix user button in the Bluetooth version
    We were checking the return value of gpio_pin_get() as if it was an
    error code for some reason.
    [main.cc]
2023-01-19 Rework sticky layer-activating mappings
    When we stopped forcing layer-activating mappings to be present on all
    layers, we kind of forgot about sticky mappings.
    This commit reworks the sticky parts of the layer-changing logic to
    allow for things like one button cycling between multiple layers,
    hopefully without breaking any existing use cases.
    [remapper.cc]
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2023-05-25 Defer set_mapping_from_config() execution
    Calling set_mapping_from_config() directly from handle_set_report()
    causes issues on nrf52. Set a flag instead and call it from the main
    loop.
    [config.cc, main.cc]
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2023-07-19 Make TIME use a counter, not wall clock
    The value returned by TIME in expressions will now increase by 1 on
    every process_mapping() iteration.
    This means it will still roughly reflect the passing of time, but
    there won't be fractional milliseconds anymore.
    [remapper.cc]
2023-07-19 Evaluate expressions exactly once per iteration
    Previously an expression was evaluated once per every mapping in which
    it appeared as the input (source).
    This makes it so that all expressions are evaluated exactly once per
    process_mapping() run.
    This means that an expression will be evaluated even if it doesn't
    appear as input in any mapping and that it will only be evaluated once
    even if it appears as an input in more than one mapping.
    This makes sense together with the new register functionality. An
    expression can for example keep a running average of the mouse cursor
    speed in a register and this value can then be used in other
    expressions.
    The expressions are evaluated in order, after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
    [remapper.cc]
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2023-09-27 Add a buffer for serial writes to avoid blocking
    A deadlock could potentially happen when both A and B sides wanted to
    write at the same time and blocked.
    This adds a buffer so that writes normally don't block and are
    interleaved with reads.
    [serial.cc]
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2023-10-07 Workaround for Xbox Adaptive Controller BLE UUIDs
    This is a workaround for the Xbox Adaptive Controller that sends UUIDs
    like this: 00002a4a-0000-0000-0000-000000000000 in Find Information
    responses.
    This is not the correct UUID128 representation for UUID16(2a4a), which
    would be: 00002a4a-0000-1000-8000-00805f9b34fb.
    [main.cc]
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2023-12-13 Prevent macros from overflowing the output buffer
    When we introduced macro step duration, we got rid of checking if the
    output report queue is empty before executing the next step of the
    macro.
    Under certain circumstances this can overflow the output buffer,
    dropping inputs.
    We bring the check back. This will sometimes mean that the actual
    macro step duration doesn't match the declared one, but that's better
    than dropping inputs.
    [remapper.cc]
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2023-12-13 Update custom boards
    This commit makes the following changes to the custom PCB designs.
    v1-v5: flash chip footprint changed, previous one caused issues in
    manufacturing. Some other components moved around as a result.
    v1-v5: flash chip changed from 1 megabyte to 2 megabyte one.
    v1: USB Type A port component changed, previous one was consistently
    soldered on crooked by JLCPCB.
    The new designs are named v1.1-v5.1.
    Schematics and enclosure files are unchanged.
    [Remapper-v1-BOM.csv, Remapper-v1.1-BOM.csv, Remapper-v2-BOM.csv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]
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2024-01-02 Bring back copy_to_ram
    The single Pico version was traditionally a copy-to-RAM binary because
    of issues with multicore code when persisting the config to flash.
    After the switch from using the Pico-PIO-USB library directly to using
    it as a TinyUSB backend, we no longer use the second core. I thought
    this would make it okay to get rid of copy-to-RAM and reclaim some
    memory this way so that's what we did.
    Unfortunately it seems that certain connected devices don't handle the
    short break in interrupt handling well and they stop working when the
    config is written to flash.
    This commit makes the single Pico version a copy-to-RAM binary again,
    though not entirely.
    To save some memory, we use a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
    [main.cc, remapper_single.cc]
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2024-01-09 Stop sending reports when our descriptor changes
    When the user saves a new config and the emulated device type doesn't
    match the one that was active on bootup then it probably doesn't make
    sense to keep sending inputs to the host (as we are likely sending
    left analog stick axes as mouse movement or the other way round).
    [remapper.cc]
2024-01-09 Handle keyboard RollOver
    Some keyboards can't handle certain combinations of keys being pressed
    (because of hardware or report descriptor limitations). When they
    detect a situation like this they send a special usage code
    (0x00070001). When we see this usage we now ignore the entire report.
    There's nothing we can do about the keyboard's limitations but at
    least now when it happens it doesn't look like the user released some
    keys when they didn't.
    [remapper.cc]
2024-01-09 Let hub_port=1 when there's no hub
    When there's no hub, the port number was 0. Let's set it to 1 in that
    case to avoid confusion with 0 meaning "all ports" down the line.
    [remapper.cc]
2024-01-09 Fix a bug when loading certain macros from device
    A macro like this:
    [
    [
    "0x00070004",
    "0x00070005"
    ],
    [
    "0x00070006"
    ],
    [
    "0x00070007"
    ]
    ]
    would load back as:
    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
    [config.cc]
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2024-04-09 Ignore empty input reports
    Some devices occasionally send empty input reports for whatever reason.
    Because of how we currently read reports, an empty report was
    interpreted as all inputs set to zero values.
    To avoid this issue, just ignore empty reports.
    [remapper.cc]
2024-04-09 Fix for zero values not being sent to digipots
    Output values are only written out if they're non-zero, which works
    because outgoing input reports are set to all zeros before every
    iteration.
    Analog outputs are not part of the outgoing input reports and weren't
    set to zero before every iteration, which resulted in zero values never
    being sent to the digital potentiometers.
    This adds clearing the analog output state before every iteration, which
    should fix the issue.
    [remapper.cc]
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2024-04-09 User-defined quirks
    Adds the possibility to configure your own quirks to work around
    broken report descriptors.
    New usages can be added and usages present in the descriptor can be
    modified or removed.
    Array and usage-range (min-max) usages are not currently supported.
    Bumps config version to 12.
    [config.cc, get_config.py, set_config.py]
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2024-04-19 Fix for interface number in user defined quirks
    It turns out that the thing that we called interface is not the
    interface number as it appears in the USB descriptors and instead it's
    an internal tinyusb index, which meant that user defined quirks only
    worked correctly on the first connected device because then the
    numbers matched.
    This makes the actual interface number available to the apply_quirks()
    function.
    [dual.h, main.cc, remapper_dual_a.cc]
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2024-05-22 Properly check horizontal scroll hi-res flag
    Previously the condition would check vertical scroll hi-res flag
    instead.
    This was never a problem in real life as the flags are typically set
    together.
    [remapper.cc]
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2024-05-22 Add boot protocol keyboard support
    This makes it so that we can act as a keyboard in boot protocol mode.
    The default is report protocol mode and the host can request a switch
    to boot protocol. We revert to report protocol on (re-)mount.
    [main.cc, our_descriptor.h, remapper.cc]
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2024-05-22 Fix for expressions longer than 255 ops
    Bumps config version to 13.
    [config.cc, types.h]
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2024-05-28 Make mapping source is_relative/is_binary per-port
    Previously connecting both a mouse and a gamepad at the same time
    would cause issues because mouse X/Y uses the same usages as left
    analog stick X/Y and we only kept a global per-usage is_analog flag.
    Now we also keep a separate flag per port so it should be possible to
    map the two device classes separately (using per-port mappings).
    [remapper.cc]
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2024-06-27 New emulated device type: XAC compatible
    This adds a new emulated device type that is meant to be used when
    plugging HID Remapper into USB ports on the Xbox Adaptive Controller.
    Technically other device types like the Switch gamepad were already
    compatible, but this lets us have exactly the inputs the XAC
    understands with proper labels.
    Also I secretly hope this will be compatible with the Hori Flex.
    Bumps config version to 14.
    [config.cc, our_descriptor.h]
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2024-10-17 [nrf52] Ensure process_mapping is called after every incoming report
    We now make sure process_mapping is called after every incoming report
    to avoid situations where we read a report with a key pressed, then a
    report with that key released, without an iteration of the processing
    engine in between, therefore missing the keystroke completely.
    [main.cc]
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2024-10-17 Avoid get_state_ptr() call in expressions
    This speeds up expression evaluation a bit by avoiding the call to
    get_state_ptr() in operations that fetch input states.
    If an input_state (prev_input_state, etc.) op is immediately preceded
    by a usage constant, the pointer to the input state is saved in the
    expression element structure.
    [remapper.cc, types.h]
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2024-11-19 Consistently treat array usages as binary
    Because they are.
    Previously we stored input state for array range usages using the
    per-interface mask scheme, but since they weren't flagged as binary,
    we then treated the per-interface mask value verbatim when processing
    absolute-to-relative mappings, which resulted in incorrect output
    values.
    Previously we didn't use the per-interface mask scheme to store input
    state for array non-range usages, overwriting state from other
    devices.
    [remapper.cc]
2024-11-19 Ignore per-port mappings if nothing plugged in
    If a mapping has the hub port set on its source (input), we now ignore
    the mapping if no device is plugged into that port.
    So if you unplug a device while one of its buttons was pressed or a
    joystick was in a non-neutral position, that state no longer remains
    stuck (as far as per-port mappings are concerned).
    When hub port is set on a mapping with an expression as its source,
    the expression is still evaluated as previously (port register is
    separate from this), but the entire mapping won't be applied.
    [remapper.cc, types.h]
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2024-11-25 Split D-pad into four synthetic usages
    Introduce "D-pad left", "D-pad right", "D-pad up", "D-pad down" usages
    that don't actually appear in the incoming and outgoing reports, but
    make it easier to set up typical mappings. For example to make WASD
    work as the D-pad, you can now create four simple mapping without
    having to use expressions. Similarly to map the D-pad directions on a
    gamepad to keys or buttons, you can now create simple mappings with
    "D-pad left" etc. as source.
    Because HID Remapper now sets the outgoing value of the D-pad usage
    based on the state of the four synthetic direction usages, mappings
    with D-pad (0x00010039) directly set as their target no longer work,
    which is a bre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
    [remapper.cc, types.h]
2024-12-02 Make multiple mappings for the same stick work better
    Previously when we had multiple mappings with the same stick axis as
    the target, we would select one of the sources that was in a
    non-neutral position with no control over what happens when there's
    more than one. This doesn't work very well because some sticks don't
    stay at precisely 128 when neutral. In practice if we wanted such
    mappings, we had to use expressions and handle it ourselves.
    This commit makes it so that when there's more than one source for a
    stick axis, we sum their inputs, thus handling the most common use
    case.
    [remapper.cc]
2024-12-02 Only process config changes after RESUME
    A typical sequence when saving config to HID Remapper looks something
    like this:
    SUSPEND
    SET_CONFIG
    CLEAR_MAPPING
    ADD_MAPPING
    ...
    CLEAR_MACROS
    APPEND_TO_MACRO
    ...
    CLEAR_EXPRESSIONS
    APPEND_TO_EXPRESSION
    ...
    CLEAR_QUIRKS
    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
    [config.cc, main.cc]
2024-12-02 Avoid blocking when writing to serial
    This makes it so that in B-to-A serial communication, certain types of
    packets (REQUEST_B_INIT, REPORT_RECEIVED, START_OF_FRAME,
    MIDI_RECEIVED) are dropped when the outgoing buffer is full and we'd
    have to block. This way we can keep regularly calling tuh_task().
    This should never happen during normal operation.
    [serial.cc, serial.h]
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2024-12-02 Change config location in flash on RP2350
    Because of RP2350-E10 errata mitigation, currently RP2350 UF2s wipe
    the last sector of flash every time, which unfortunately is where we
    keep our configuration.
    Move it down 4096 bytes on RP2350 to avoid the issue.
    [main.cc]
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2024-12-02 Reset internal state on config save
    We now reset registers, frame counter ("time") and accumulated
    fractional relative usage values on configuration save.
    This should make it easier to test certain configurations without
    having to unplug the device every time.
    [config.cc, remapper.cc]
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2025-01-03 [nrf52] Handle SET/GET_REPORT in main loop
    This makes it so that instead of handling SET_REPORT requests directly
    from set_report_cb(), we queue them and process them in the main loop.
    The idea is that this way we won't have to worry about concurrent
    access to variables if the callback is called while we're inside
    process_mapping() etc. On RP2040 we pretty much don't have to worry
    about it because all the callbacks are called from tud_task().
    GET_REPORT responses are also generated asynchronously in the main
    loop so if get_report_cb() is called before the response is ready, we
    send back an empty response. The host is now responsible for retrying
    the GET_REPORT request in such situations.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
    [config.cc, get_config.py, main.cc]
2025-01-03 Protect against overflow when persisting config
    Don't overflow the buffer when the persisted config doesn't fit in the
    space we have for it in flash.
    [config.cc]
2025-01-03 PERSIST_CONFIG return code
    Make it possible to check if PERSIST_CONFIG command succeeded or
    failed due to the config being too large to persist in flash.
    [config.cc, main.cc, set_config.py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]
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2025-01-03 Scale stick and trigger inputs to 0-255 range
    Previously mappings like this:
    Left stick X -> Left stick X
    only worked correctly if the plugged in device used a 0-255 range for
    its sticks.
    This makes it so that non-binary absolute usages are scaled to 0-255
    range based on their logical_minimum and logical_maximum. This
    eliminates the need for expressions when remapping devices with such
    usages.
    INPUT_STATE expression operation still gives the raw value as before.
    New INPUT_STATE_SCALED operation gives the scaled value.
    [remapper.cc, types.h]
2025-01-03 Assign all expression input state slots on demand
    Previously we assigned state slots to some, but not all, inputs used
    in expressions on configuration load, and we also did an
    "optimization" pass that stored some state pointers in expressions so
    that we didn't have to go through get_state_ptr() on every evaluation.
    Now we just do get_state_ptr() with assign_if_absent=true while
    evaluating the expressions and cache that pointer.
    This means that only constant usages and port numbers will now work.
    If you want to do clever things like fetch input states with the usage
    code or port number depending on some other input or register state,
    fetch them all statically and then choose the one you wa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
    [remapper.cc]
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2025-01-15 Fix regression: INPUT_STATE for analog/MIDI/GPIO
    Auto-scaling absolute values to 0-255 range broke INPUT_STATE
    expression operation for analog, MIDI and GPIO inputs because
    INPUT_STATE reads raw state and we were only setting the scaled state.
    We now set both raw and scaled states for analog, MIDI and GPIO
    inputs.
    [main.cc, remapper.cc]
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2025-01-17 [nrf52] Fix regression: scroll resolution multiplier
    When we started handling SET_REPORT requests asynchronously (in the
    main loop) I had hoped that it wasn't going to be an issue for the
    scroll resolution multiplier. Turns out it can be an issue on Windows.
    This makes it so that scroll resolution multiplier modifications are
    handled immediately, instead of being queued and processed in the main
    loop, so that subsequent GET_REPORT requests always get the updated
    value.
    [main.cc, our_descriptor.h, remapper.cc]
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2025-03-10 Don't sync SOF between device and host
    This makes it so that the SOF clock on the downstream facing side is
    no longer synchronized to the upstream facing side on the single Pico
    variant.
    While I think overall the behavior was desirable, unfortunately it
    caused issues in certain situations, causing devices to not work if
    they were plugged into HID Remapper before it was plugged into the PC
    or if the PC was turned on with everything already plugged in. There
    were related issues with KVM switches and sleep/wake. Also because the
    processing engine didn't run at all when there were no SOF packets
    coming from the host, HID Remapper couldn't be used as a USB-to-GPIO
    decoder without a host.
    All of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
    [remapper_single.cc]
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2025-05-23 Allow registers as mapping outputs
    Make it so that mappings with registers as targets work as expected
    (setting the registers to values coming from the inputs).
    This allows for more generic expressions with the registers acting as
    parameters/placeholders, so that the expression doesn't have to be
    modified just to change the inputs it's acting on.
    Because of the order of evaluating expressions and mappings, the
    values in the registers are delayed by one frame compared to if they
    were read directly.
    [remapper.cc]
2025-06-17 Invalidate cached state pointers in expressions
    This makes it so that the cached state pointers in expressions are
    reset when we reset all the state slot assignments.
    Not doing this wasn't an issue when we were resetting the state slots
    after a configuration save, because in that case the expressions were
    recreated anyway, but it was an issue when set_mapping_from_config()
    was called after a boot/report protocol change.
    [remapper.cc]
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
